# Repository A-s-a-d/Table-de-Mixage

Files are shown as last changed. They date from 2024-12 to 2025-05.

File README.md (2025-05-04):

# Cahier des charges  
[📄 lien vers Cahier des charges global (par le chef de projet)](CDC.pdf)  

Le but du projet est de créer une **table de mixage hybride**.  
Le système est divisé en **quatre sous-systèmes principaux**, chacun ayant un rôle spécifique dans la gestion du son, de l’alimentation et de l’interaction avec l’utilisateur.

---

# Sous-système : Entrées analogiques et numériques  
Ce sous-système gère la **réception des signaux audio et numériques** provenant des instruments.  
Il comprend l’interface physique entre les entrées (microphones, synthétiseurs, entrées MIDI) et le **programme de traitement** fonctionnant sur la Raspberry Pi.  
L’objectif est d’assurer une **conversion propre** des signaux vers un format numérique exploitable.

[📁 lien vers Dossier Sous-système Entrées](SousSysteme_Entrees/)  

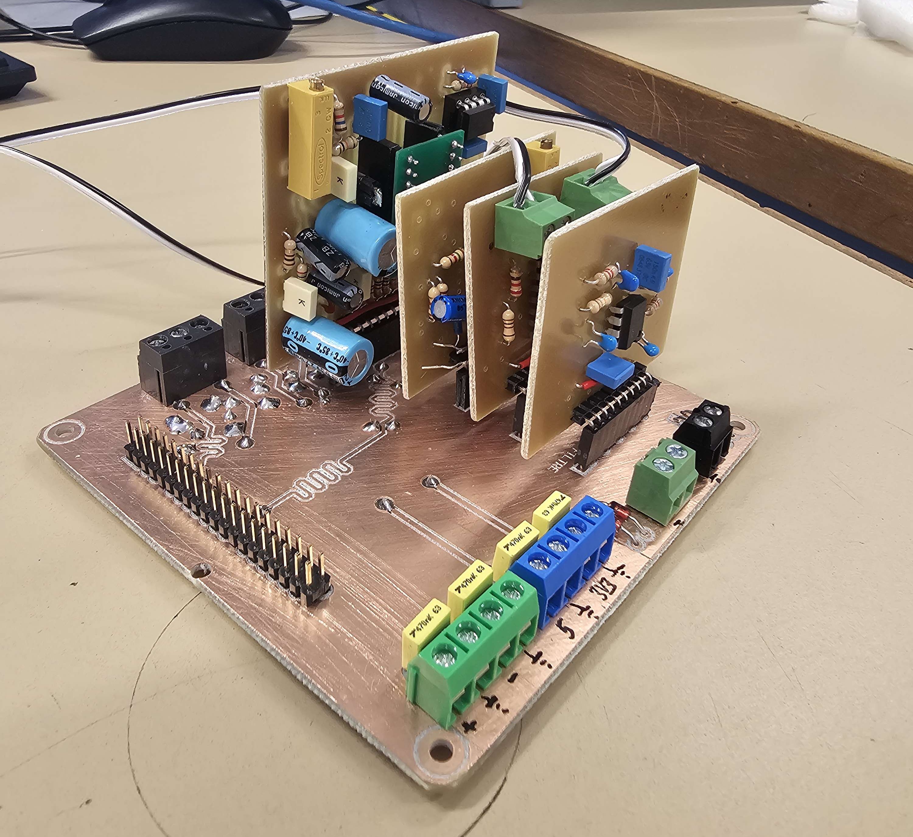
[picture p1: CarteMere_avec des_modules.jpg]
Carte mère avec des modules


---

# Sous-système : IHM et effets  
Ce sous-système englobe l’**interface homme-machine (IHM)** ainsi que la gestion des **effets sonores** (réverbération, équalisation, filtres, etc.).  
Il permet à l’utilisateur d’interagir en temps réel avec la table de mixage à l’aide de boutons, d’écrans ou de potentiomètres.

[📁 lien vers Dossier Sous-système IHM et effets](SousSysteme_IHM/)

---

# Sous-système : Amplification et restitution  
Ce sous-système s’occupe de **l’amplification** du signal audio traité et de sa **restitution** via des sorties jack ou haut-parleurs.  
Il est chargé de garantir une **qualité sonore fidèle** et adaptée aux usages finaux (monitoring, diffusion, etc.).

[📁 lien vers Dossier Sous-système Amplification et restitution](SousSysteme_Ampli_Restitution/)

---

# Sous-système : Alimentation et CAO 3D  
Ce sous-système prend en charge la **gestion de l’alimentation électrique** de l’ensemble du système, incluant la protection et la distribution.  
Il comprend également la **modélisation 3D** du boîtier via des outils de CAO, pour intégrer tous les composants de manière ergonomique.

[📁 lien vers Dossier Sous-système Alimentation et CAO 3D](SousSysteme_Alim/)

---

# Planification  
[📄 lien vers Dossier de planification du projet](DossierPlanification.pdf)

## Diagramme de Gantt  
[📊 lien vers Gantt (version 2)](Gantt_V2.pdf)

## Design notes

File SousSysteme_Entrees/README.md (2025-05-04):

# Sous-système : Entrées analogiques et numériques  

Ce sous-système est dédié à la **gestion des signaux d'entrée**, qu’ils soient **analogiques (ex. : micro, instruments)** ou **numériques (ex. : MIDI, USB)**.  
Il assure la **numérisation, le pré-traitement**, et le **transfert des données** vers le cœur logiciel de la Raspberry Pi.  
Ce sous-système est crucial pour acquisition des signaux.

---

## 📄 [Documentation / Dossier Technique](Documentation/)  
Ce dossier contient :
- Les **spécifications fonctionnelles et techniques** de ce sous-système
- Les **schémas blocs**
- Les **justifications des choix de composants**
- Le **compte rendu de tests** et mesures

C’est la référence principale pour comprendre la logique et l’architecture de ce module.

---

## 🔧 [Électronique](Electronique/)  
Ce répertoire regroupe :
- Les **schémas électroniques** (fichiers Altium, PDF, etc.)
  - voir video pour comment convertir fichier Altium en Kicad : https://www.youtube.com/watch?v=ORND7ThJx7o
- Les **typons** et routages PCB (Gerber)
- Les **simulations** (LTSpice)
Il documente toute la partie matérielle et les circuits analogiques/numériques nécessaires à l’interface avec la Raspberry Pi.

---

## 💻 [WorkSpace Linux / Programmes Linux](Linux_WorkSpace/)  
Ce dossier contient :
- Les **programmes de traitement des entrées** développés sous Linux
- Les **scripts d’acquisition**
- La configuration de l’environnement Linux pour le sous-système (drivers, services, dépendances, etc.)
- 
C’est ici que se fait le lien entre le matériel d’acquisition et le **traitement logiciel**.

---

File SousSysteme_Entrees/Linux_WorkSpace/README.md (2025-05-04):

## 💻 [WorkSpace Linux / Programmes Linux](Linux_WorkSpace/)

Ce répertoire regroupe tous les **programmes, fonctions, scripts et tutoriels** nécessaires au fonctionnement du sous-système sous Linux. Il est conçu pour faciliter le développement, l’automatisation et le test sur Raspberry Pi.

---

### 🔤 [C / C++ Programming](Linux_WorkSpace/C_Cpp_Programming/)

Contient des **exemples de code, fonctions spécifiques au sous-système**, ainsi que des **modèles de projet**.

#### 📁 Exemples :  
- [Non Blocking Execution (C)](Linux_WorkSpace/C_Cpp_Programming/Exemples/NonBlockingExecutionC/)
- [Digital Write sur GPIO de la Pi](Linux_WorkSpace/C_Cpp_Programming/Exemples/Pi_Digital_write/)
- [Test SPI](Linux_WorkSpace/C_Cpp_Programming/Exemples/Spi_Test/)
- [Multithreading + Synchronisation](Linux_WorkSpace/C_Cpp_Programming/Exemples/Threading_with_Synchronization/)
- [UART Data Handling](Linux_WorkSpace/C_Cpp_Programming/Exemples/Uart_data/)
- [Utilisation des Threads](Linux_WorkSpace/C_Cpp_Programming/Exemples/Use_Threads/)

#### 📁 Fonctions spécifiques au Sous-Système :  
- [Génération d'horloge 11.265 MHz](Linux_WorkSpace/C_Cpp_Programming/Function_SS/CLK_11_265_000Hz/)
- [Réception MIDI IN](Linux_WorkSpace/C_Cpp_Programming/Function_SS/MIDI_IN/)
- [SPI - MCP3564 (ADC)](Linux_WorkSpace/C_Cpp_Programming/Function_SS/Spi_Mcp3564/)

#### 📁 Templates de projets :  
- [Template C/C++](Linux_WorkSpace/C_Cpp_Programming/Templates/Template_C_Cpp/)
- [Template avec WiringPi](Linux_WorkSpace/C_Cpp_Programming/Templates/Template_WiringPi/)

---

### ⚙️ [Installations et Automatisation](Linux_WorkSpace/Installations_and_automation/)

Instructions, guides et scripts pour la **configuration de l’environnement Linux** et les installations nécessaires.

- [Activer l’UART](Linux_WorkSpace/Installations_and_automation/Activate_uart.md)
- [Configurer Git](Linux_WorkSpace/Installations_and_automation/git.md)
- [Liste des installations nécessaires](Linux_WorkSpace/Installations_and_automation/Installations_needed.md)
- [Connexion Bureau à Distance](Linux_WorkSpace/Installations_and_automation/RemoteDesktop.md)

---

### 🖥️ [Commandes Linux](Linux_WorkSpace/linux_commands/)

Scripts utiles pour la ligne de commande, manipulation de fichiers, utilisateurs, etc.

- [Commandes fichiers/dossiers](Linux_WorkSpace/linux_commands/file_and_folder_commands.sh)
- [Commandes importantes](Linux_WorkSpace/linux_commands/important_commands.sh)
- [Commandes utilisateur](Linux_WorkSpace/linux_commands/user_commands.sh)

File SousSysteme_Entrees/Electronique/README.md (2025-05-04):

## 🔧 [Électronique](Electronique/)

Ce répertoire regroupe toute la conception matérielle et les tests associés au sous-système Entrées. Il est structuré en plusieurs sous-dossiers détaillés ci-dessous.

---

### 📐 [CAO PCB](Electronique/CAO_PCB/)  
Contient les projets de **conception des circuits imprimés** avec leur hiérarchie modulaire.

- [01 - Suiveur](Electronique/CAO_PCB/01-Suiveur/)
- [02 - Détection et Ampli](Electronique/CAO_PCB/02-Detection_et_Ampli/)
- [03 - Offset et PBF](Electronique/CAO_PCB/03-Offset_et_PBF/)
- [04 - ADC + Filtre Antialiasing](Electronique/CAO_PCB/04-ADC+antiallaising/)
- [Assemblage des Modules Analogiques](Electronique/CAO_PCB/Assamblage_Modules_Analogique/)
- [Carte Mère](Electronique/CAO_PCB/Carte_Mere/)
- [MCP3564 (Convertisseur ADC)](Electronique/CAO_PCB/MCP3564/)
- [Library - Composant ](Electronique/CAO_PCB/Library)

---

### 🧾 [Fichiers Gerber (CAO PCB Gerber)](Electronique/CAO_PCB_GERBER/)  
Fichiers prêts pour la **fabrication des circuits imprimés**.

- [01 - Suiveur](Electronique/CAO_PCB_GERBER/01-Suiveur/)
- [02 - Détection et Ampli](Electronique/CAO_PCB_GERBER/02-Detection_et_Ampli/)
- [03 - Offset et PBF](Electronique/CAO_PCB_GERBER/03-Offset_et_PBF/)
- [04 - ADC + Antialiasing](Electronique/CAO_PCB_GERBER/04-ADC+antiallaising/)
- [Carte Mère](Electronique/CAO_PCB_GERBER/Carte_Mere/)
- [MCP3564](Electronique/CAO_PCB_GERBER/MCP3564/)

---

### 🔁 [Simulations](Electronique/SIMULATIONS/)  
Simulations de circuits réalisés sous LTspice ou autre pour validation des choix de conception.

---

### 🧪 [Tests](Electronique/TESTS/)

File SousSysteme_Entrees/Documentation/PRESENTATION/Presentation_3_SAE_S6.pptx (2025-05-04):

## Table de Mixage : SmartMix

SAE BUT 3 GEII ESE

## Sommaire

1. Présentation de système
2. Détails des sous-systèmes
3. Conception et mise en œuvre
4. Implantation
5. Vérification
6. Dysfonctionnements et maintenance
7. État actuel du système
8. Conclusion et pistes d'amélioration

## Présentation de système

Mixage des signaux audios (analogiques ou numériques) envoyés par des instruments développés par les étudiants de BUT 3 GEII ESE

Fonctionnalités clés :
- 2 Entrées Numériques
- 2 Entrées Analogiques
- Synchronisation des données

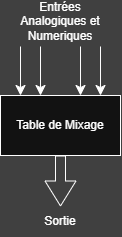
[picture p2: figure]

## FAST

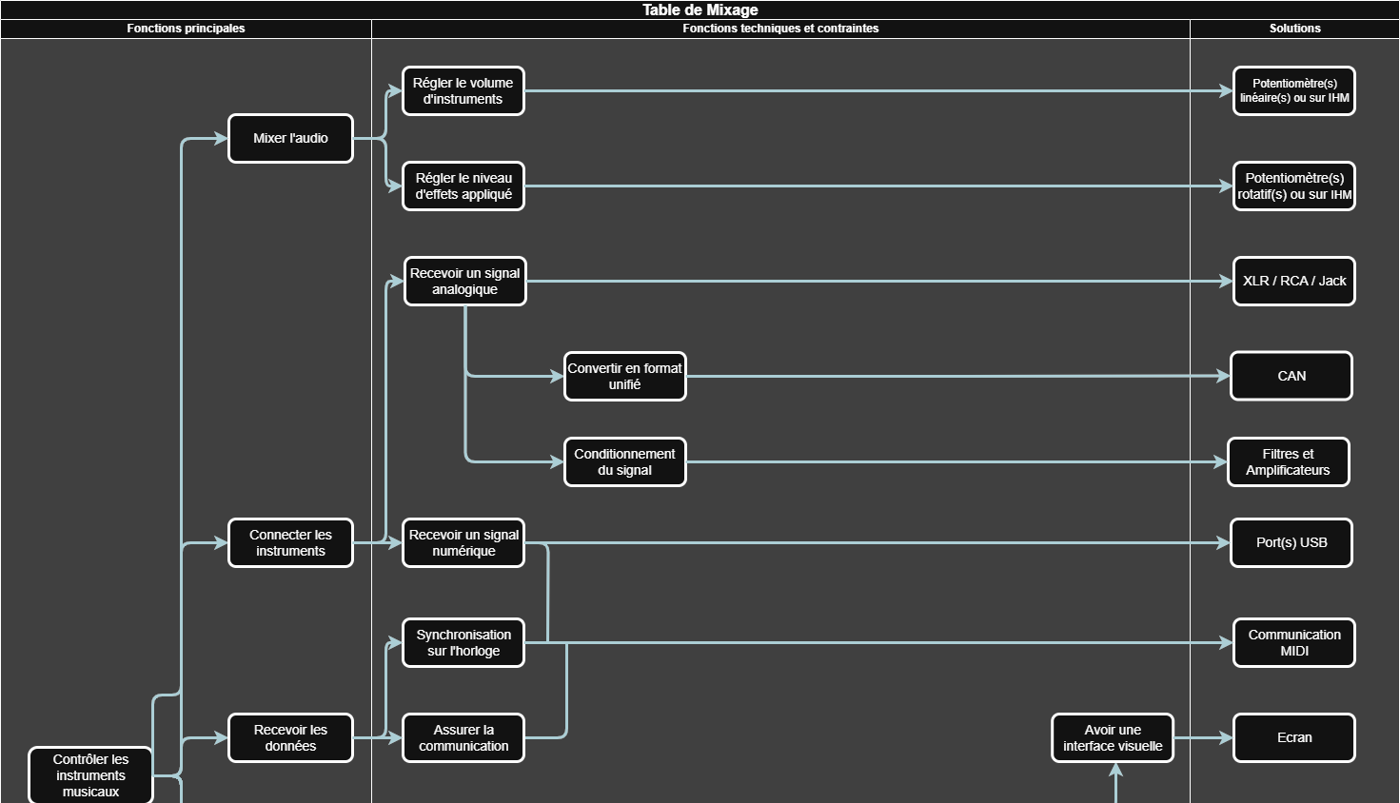
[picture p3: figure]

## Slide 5

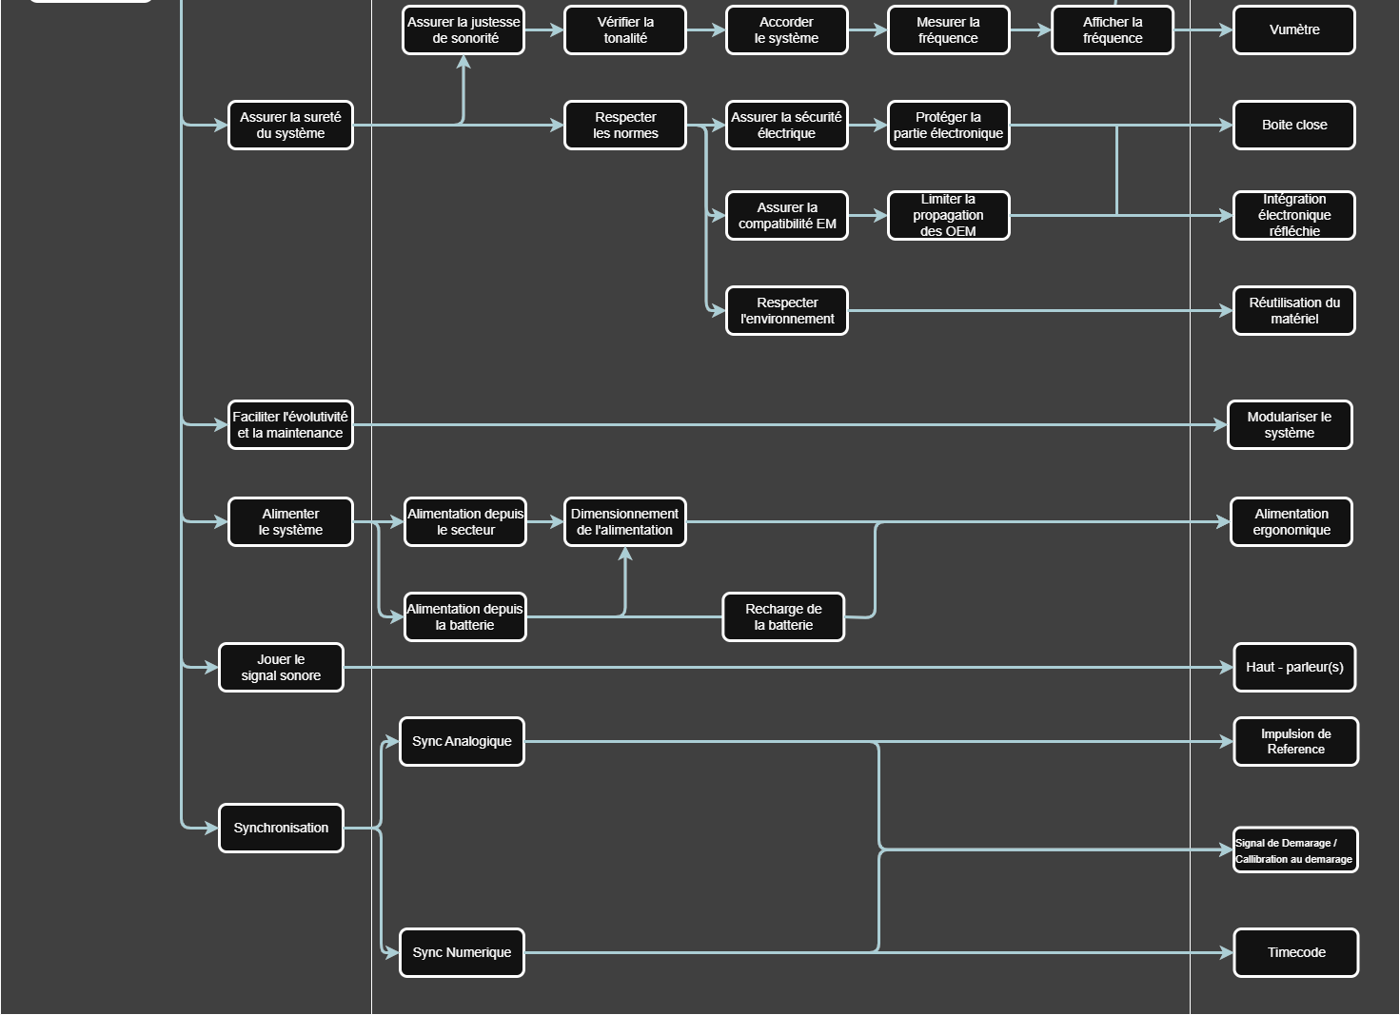
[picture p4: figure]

## Détails des sous-systèmes

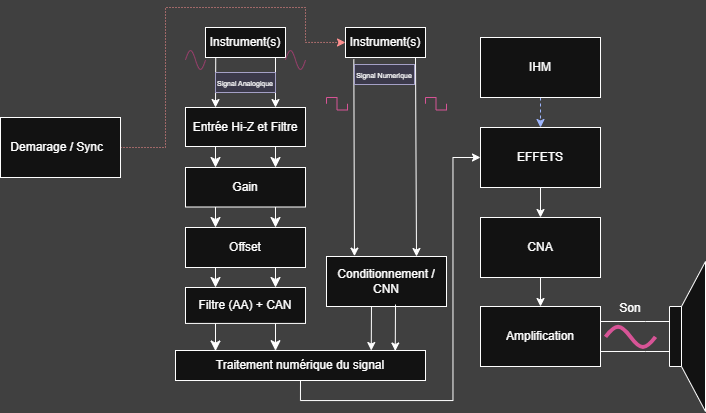
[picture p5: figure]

## Conception

- Conception d’un système électronique modulaire
- Traitement des Signaux analogiques et numériques : filtrage, Gain, Offset, conversion, synchronisation
- Choix techniques justifiés en fonction des contraintes de performance, consommation et coût
- Outils et technologies utilisés :
  - Raspberry Pi 4B
  - CAO : Altium Designer
  - Simulation : LTSpice
  - Langages : C++, Python
  - Versioning : Git (GitHub -> GitLab)

## Conception

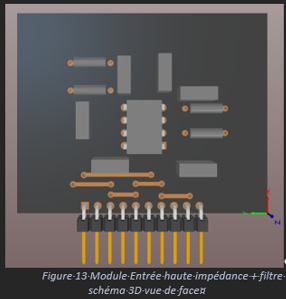
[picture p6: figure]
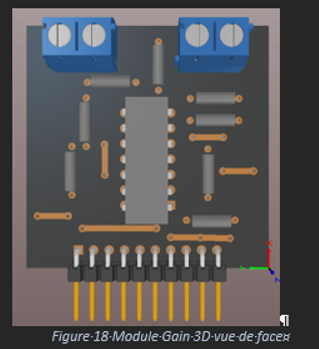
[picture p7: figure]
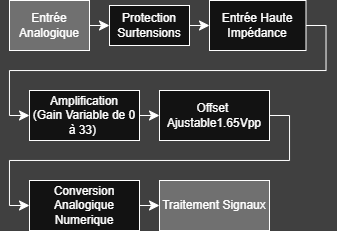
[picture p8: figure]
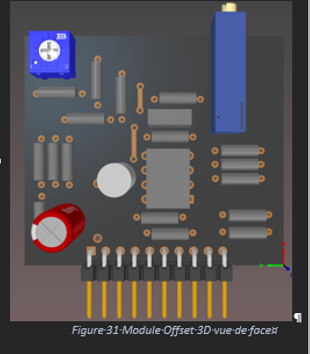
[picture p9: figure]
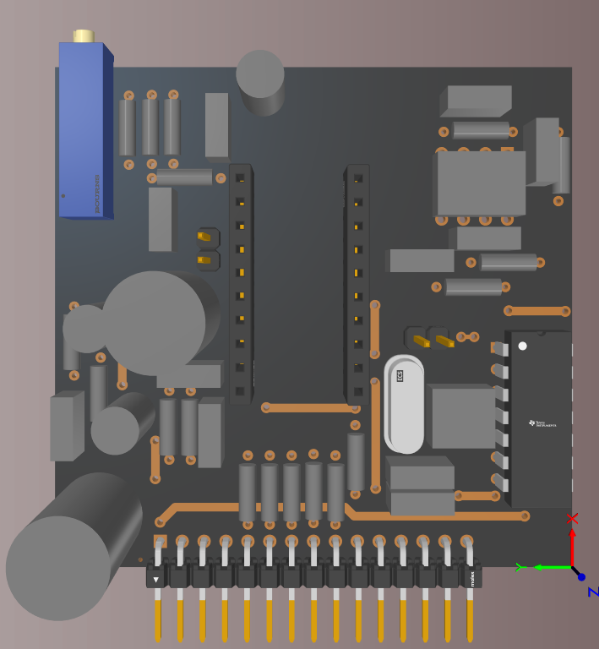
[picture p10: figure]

## Conception

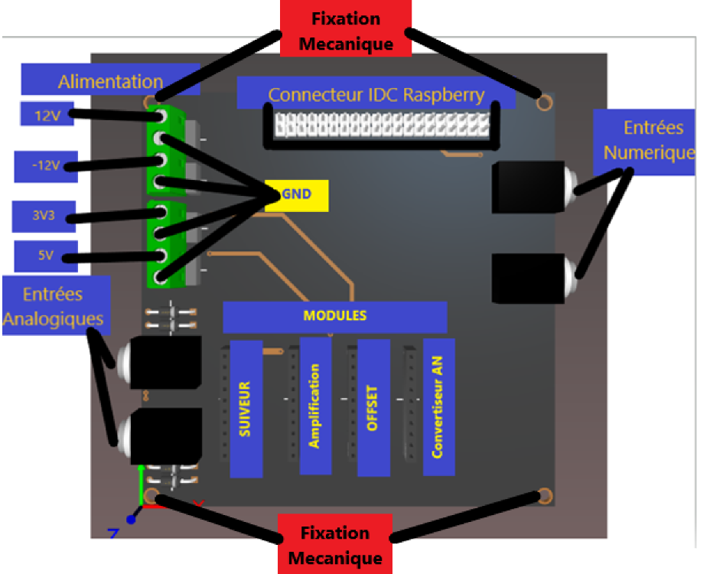
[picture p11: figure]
Carte Mere avec des modules

## Vérification

- Approche PDCA (Plan – Do – Check – Act) :
  - Plan : Planifier : définition des objectifs de tests et critères de validation
  - Do : Déployer : exécution des tests unitaires et d'intégration
  - Check : Contrôler : analyse des résultats, identification des écarts
  - Act : Ajuster : actions correctives et amélioration continue

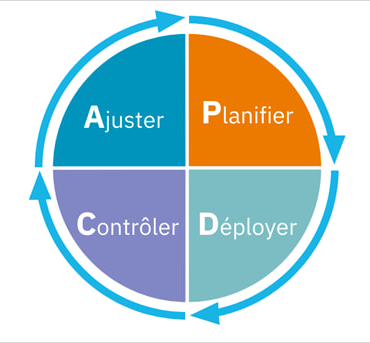
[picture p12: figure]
Cycle PDCA ou Roue de deming

## Vérification

- Exemple :
  - Plan : Conception de Carte ADC et horloge externe avec un oscillateur quartz
  - Do : Test de différents signaux
  - Check : problème avec l’horloge 11MHz, a cause des caractéristiques des composants
  - Act : Configurer la carte pour utiliser le 2eme mode de Horloge Externe.

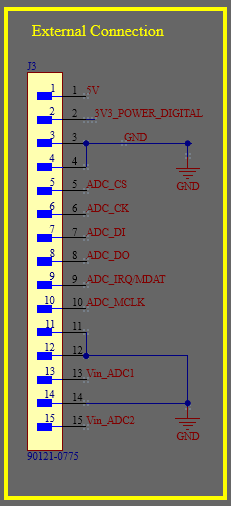
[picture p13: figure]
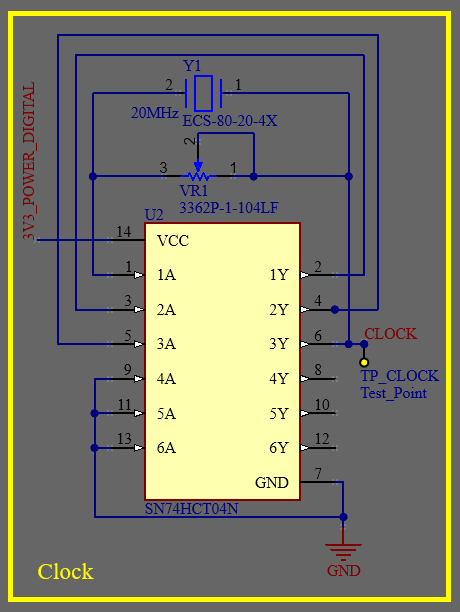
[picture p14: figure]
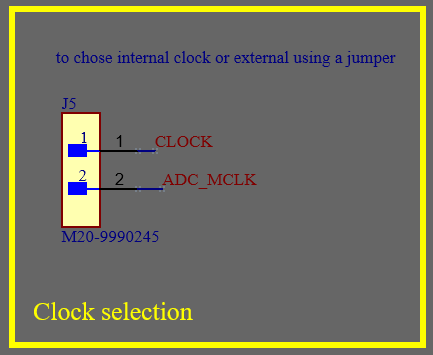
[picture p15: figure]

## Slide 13

Exemple de dysfonctionnement

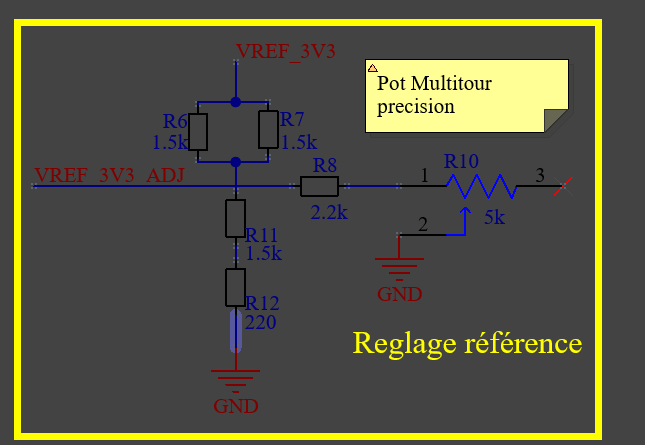
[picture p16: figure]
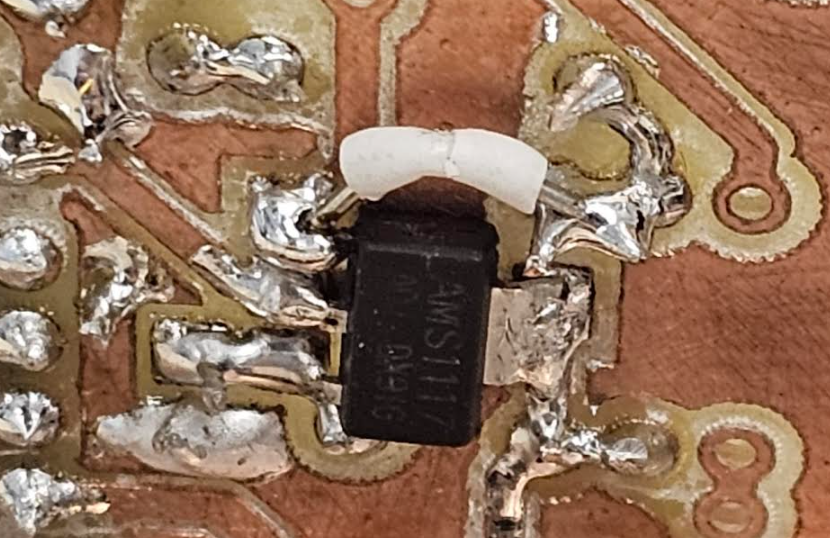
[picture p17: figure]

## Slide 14

Synthèse globale des Test et état actuelle de système

Sous-système | Modules Testés | Type de Test | Critères de Validation | Résultats | Actions Correctives
Carte Mère | FT9-0 & FT9-1 | Tests de fonctionnement | Bonne modularité et absence de court-circuit | Fonctionnel | Aucune
Entrée Audio Analogique | FT2-0 | Test de pré-amplification et filtrage | Amplification correcte, atténuation bruit | Fonctionnel | Aucune
| FT2-1 | Test de régulation du gain | Variation du gain conforme aux attentes | Fonctionnel | Aucune
| FT2-2 | Test de décalage (offset) | Offset réglable et stable | Fonctionnel | Aucune
| FT3-0 | Conversion analogique-numérique (ADC) | Résolution entre 12 et 24 bits, échantillonnage à 44,1 kHz | Fonctionnel | Aucune
Entrée Audio Numérique | FT1-0 | Test de réception MIDI | Réception des messages MIDI sans erreur | Fonctionnel | Aucune
| FT6 | Synchronisation MIDI | | Non-disponible ou en cours | Aucune
| FT3 -1 | Programme Conversion Analogique Numérique | | Non-disponible ou en cours | Aucune

## Implantation, Checklist

- Alimentations
  - Tensions requises : +12V, -12V, 3.3V, 5V.
  - Connexion aux connecteurs dédiés.
- 2. Connexions des Entrées Analogiques & Numériques
  - Sources Analogiques : jack 3.5mm, sources audios.
  - Signaux Numériques : Niveau logique 3.3V pour le MIDI, jack 3.5mm

- 3. Installation du Système
  - Préparation de la carte SD.
  - Installation de Raspberry Pi OS et des bibliothèques nécessaires.
  - Démarrage de la Raspberry Pi avec le programme dédié.
- 4. Précautions
  - Respect des niveaux de signal : +4 dBu (1.736V peak) pour l’analogique.
  - Manipulation électrique uniquement système éteint.
  - Suivi des schémas et consignes de sécurité.

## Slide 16

Maintenance Préventive

Définition :
Intervention anticipée pour éviter l’apparition de pannes.
Actions réalisées :
- Vérification régulière des connexions entre modules
- Inspection visuelle pour détecter usure ou corrosion
- Nettoyage des éléments sensibles
- Exemple concret : Nettoyage régulier des potentiomètres pour garantir leur bon fonctionnement

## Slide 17

Maintenance Corrective

Définition :
Intervention après l'apparition d'un dysfonctionnement pour restaurer le système.
Actions réalisées :
- Remplacement des modules ou composants défectueux
- Réparation des connexions endommagées
- Exemple concret : Remplacement des potentiomètres en fin de vie ou présentant des erreurs de lecture

## Facilité de Maintenance

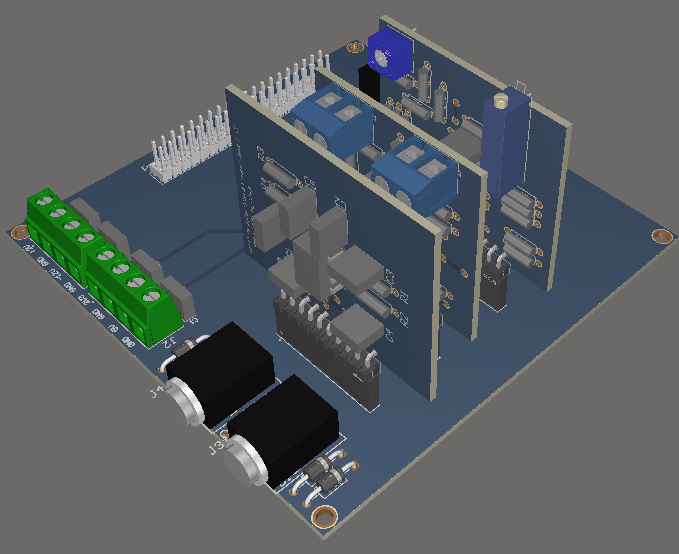
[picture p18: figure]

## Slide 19

Check List & CDC

- Mixer l’Audio
- Connecter les Instruments
- Recevoir les données
- Assuer la sureté du systeme
- Facilite de l’évoluivité et la maintenance
- Alimenter le système
- Envoyer un signal sonore en sortie.
- Synchronisation

Fonctionne
Fonctionne en état degradé
Non fonctionnel

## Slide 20

Reste a Faire

- Finir la programmation de ADC
- Intégrer tous les systèmes ensemble
- Gain automatique : Signaux analogiques
- Mettre plus d’entrées et moyens d’envoyer des signaux.
- Mettre en place des procédures de maintenance automatisées pour détecter les défaillances rapidement.
- Traitement temps réel.

Pistes ameliorations

## Questions

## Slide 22

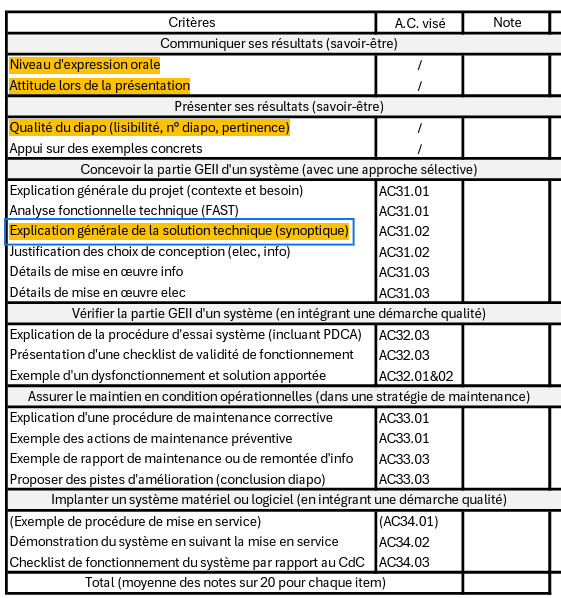
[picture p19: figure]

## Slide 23

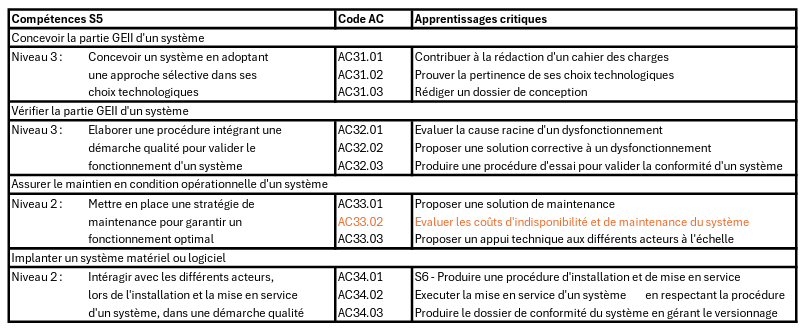
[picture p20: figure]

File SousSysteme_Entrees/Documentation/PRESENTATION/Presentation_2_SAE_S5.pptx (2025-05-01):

## Table de Mixage : SmartMix

SAE BUT 3 GEII ESE

MUHAMMAD Asad

## Sommaire

1. Présentation et Objectifs
2. Présentation des sous-systèmes
3. Approche pour la conception du système
4. Détails des sous-systèmes, Conception et mise en œuvre
5. État actuel du système
6. Dysfonctionnements et maintenance
7. Conclusion et pistes d'amélioration

## Contexte et Besoin

Mixage des signaux audios (analogiques ou numériques) envoyés par des instruments développés par les étudiants de BUT 3 GEII ESE

Fonctionnalités clés :
- 2 Entrées Numériques
- 2 Entrées Analogiques
- Synchronisation des données


## FAST


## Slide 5


## Caractéristiques principales

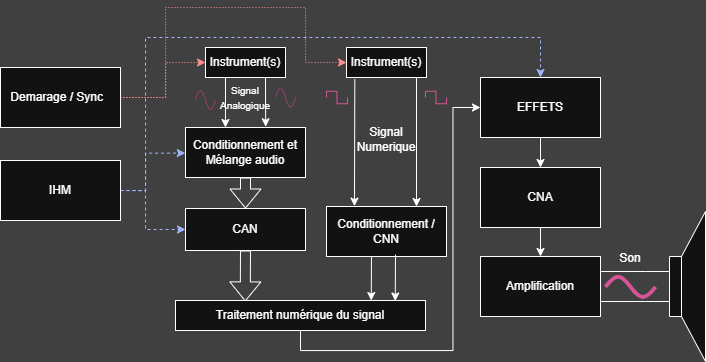
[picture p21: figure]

## Conditionnement de signal analogique


100mVpp- ~3.3Vpp

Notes: Simulations electriques sur LTSpice et PCB sur Altium designer

## Entrée Numérique

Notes: Choix Raspberry Pi :
Interface Graphique sur un ecran couleur
Performances améliorées
Conectivité et interfacess disponibles, Nombres d’UARTS disponibles
Gestion des Tâches Complexes
Plus d’outils disponiibles avec une possibilitées de programmer en plusieurs languages, automatiser avec des scripts.

Inconvenient :
Pas Temps reel, mais la vitesste doit etre suffisant pour ne pas impacter le système.
Sinons des solutions comme :
isolations des cœurs
Et programmation multicoeurs

## Approche de Conception : Modulaire

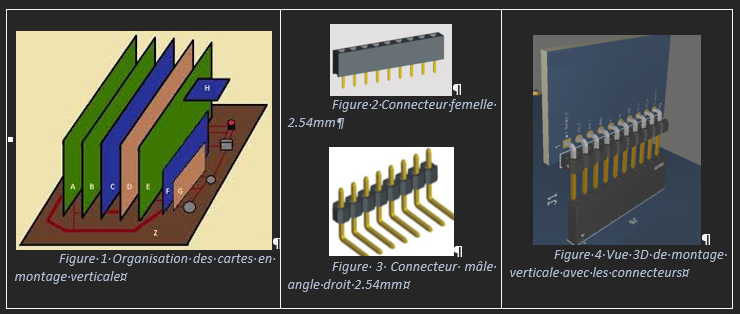
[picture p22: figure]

Développement parallèle, Maintenance Facile, Réutilisabilité, Améliorations faciles.

## Entrée et Protection Surtensions

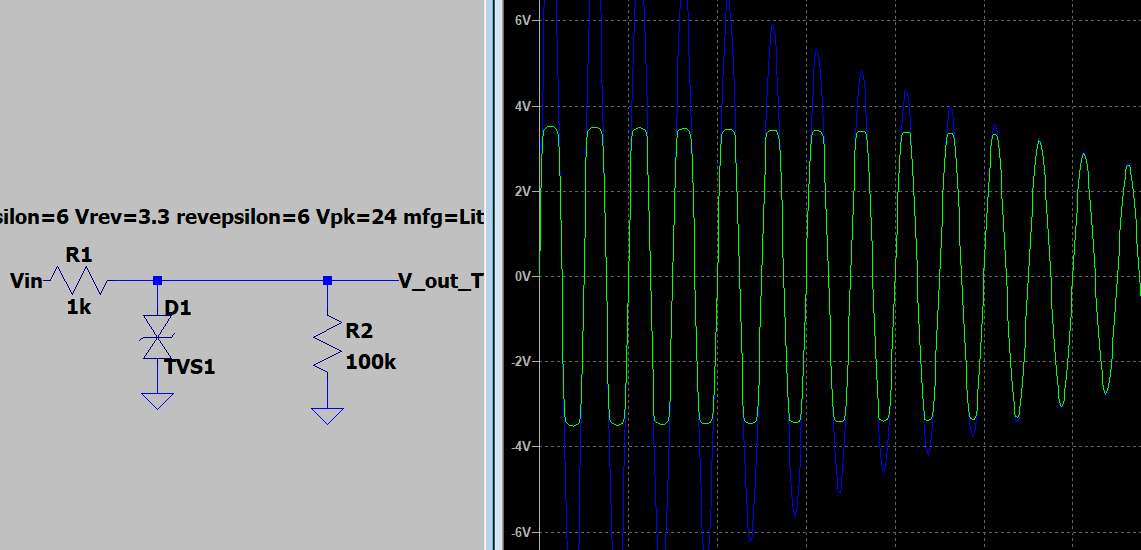
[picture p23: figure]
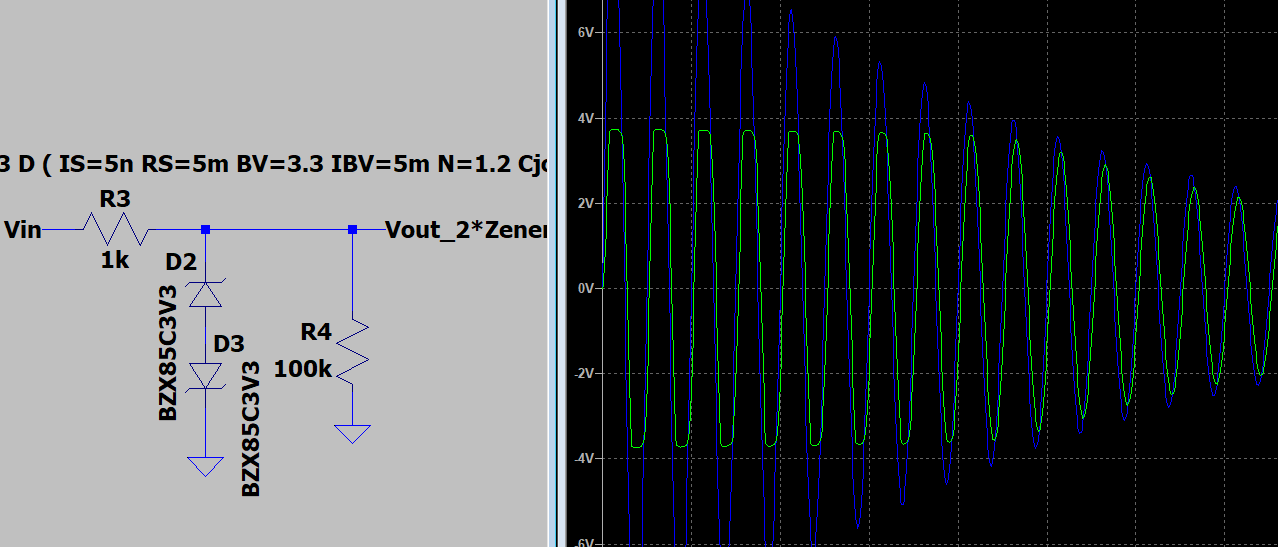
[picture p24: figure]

## Entrée Haute Impédance

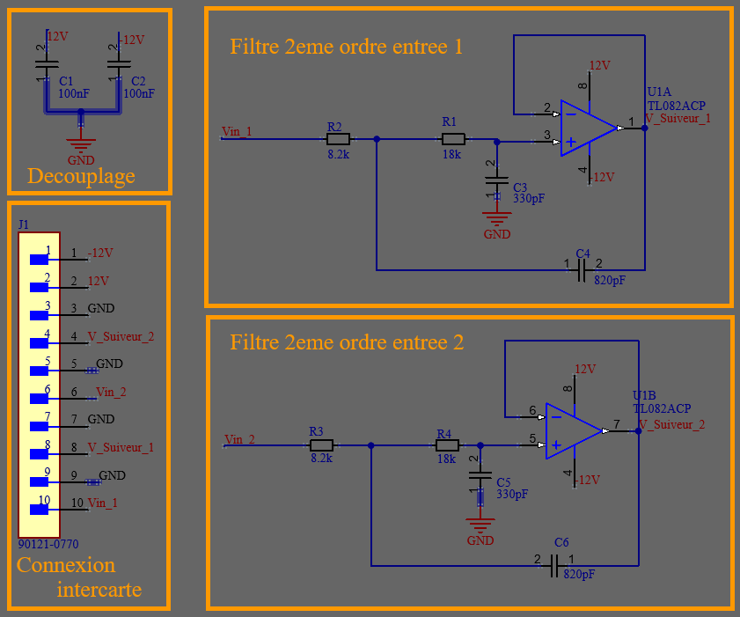
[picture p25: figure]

Module


## Entrée Haute Impédance

Module


## Amplification


Module

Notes: Ampli gain automatique

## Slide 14

Amplification


A module


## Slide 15

Offset

Module

## Offset


A module


## Conversion Analogique Numérique

Module
- ADC : Mcp3564
  - 24 bits
  - Maximum 152kHz
  - SPI

En developpement

## Carte Mère


## Mise en œuvre électrique, Checklist

- Alimentations
  - Tensions requises : +12V, -12V, 3.3V, 5V.
  - Connexion aux connecteurs dédiés.
- 2. Connexions des Entrées Analogiques & Numériques
  - Sources Analogiques : jack 3.5mm, sources audios.
  - Signaux Numériques : Niveau logique 3.3V pour le MIDI, jack 3.5mm

- 3. Installation du Système
  - Préparation de la carte SD.
  - Installation de Raspberry Pi OS et des bibliothèques nécessaires.
  - Démarrage de la Raspberry Pi avec le programme dédié.
- 4. Précautions
  - Respect des niveaux de signal : +4 dBu (1.736V peak) pour l’analogique.
  - Manipulation électrique uniquement système éteint.
  - Suivi des schémas et consignes de sécurité.

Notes: Remarque : La conversion Analogique-Numérique n'est pas encore disponible. Une mise à jour du document et du programme sera effectuée sur GitLab ultérieurement.

## Entrée Numérique et Isolation électrique


=

## Données Midi

MIDI Communication Tips – CHD Elektroservis

MIDI Standard | Utilisé | Pourquoi
31250 baud | 115200 baud | 31250 n’est pas standard 16C650, donc il faut une configuration manuelle.
0 – 5V | 0 – 3.3V | 0-3.3V is the logic levels for Raspberry Pi.

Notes: N’est pas en kernal,
Standard 16C650
Diviseur flotant donc peutetre avec freqence de horloge a modifier.
termios
A kernel is a computer program at the core of a computer's operating system that always has complete control over everything in the system. The kernel is also responsible for preventing and mitigating conflicts between different processes.[1] It is the portion of the operating system code that is always resident in memory[2] and facilitates interactions between hardware and software components. A full kernel controls all hardware resources (e.g. I/O, memory, cryptography) via device drivers, arbitrates conflicts between processes concerning such resources, and optimizes the utilization of common resources e.g. CPU & cache usage, file systems, and network sockets. On most systems, the kernel is one of the first programs loaded on startup (after the bootloader). It handles the rest of startup as well as memory, peripherals, and input/output (I/O) requests from software, translating them into data-processing instructions for the central processing unit.

## GPIO : Uart

Raspberry Pi


## Configuration Uart

- Installer Pi Os
- Modifier les fichiers de configuration de démarrage " “Boot” pour activer les UARTs.
- Installer la bibliothèque : Wiring Pi.
- C / C++ programme pour la réception des données séries.
- Les données sont disponibles pour le traitement numérique.

Raspberry Pi

## Mise en oeuvre Informatique, Checklist

- 1. Installation et Configuration du Système
  - Préparation de la carte SD avec Raspberry Pi OS
  - Installation des bibliothèques nécessaires (WiringPi, etc.)
- 2. Développement et Programmation
  - Gestion des entrées/sorties MIDI
  - Lancement du programme de réception des données MIDI.
- 3. Tests et Validation
  - Vérification du bon fonctionnement conditionnement des signaux analogiques.
  - Vérification de la réception des données MIDI.

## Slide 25

Synthèse globale des Teste et état actuelle de système

Sous-système | Modules Testés | Type de Test | Critères de Validation | Résultats | Actions Correctives
Carte Mère | FT9-0 & FT9-1 | Tests de fonctionnement | Bonne modularité et absence de court-circuit | Fonctionnel | Aucune
Entrée Audio Analogique | FT2-0 | Test de pré-amplification et filtrage | Amplification correcte, atténuation bruit | Fonctionnel | Aucune
| FT2-1 | Test de régulation du gain | Variation du gain conforme aux attentes | Fonctionnel | Aucune
| FT2-2 | Test de décalage (offset) | Offset réglable et stable | Fonctionnel | Aucune
| FT3-0 | Conversion analogique-numérique (ADC) | Résolution entre 12 et 24 bits, échantillonnage à 44,1 kHz | Non-disponible ou en cours | Aucune
Entrée Audio Numérique | FT1-0 | Test de réception MIDI | Réception des messages MIDI sans erreur | Fonctionnel | Aucune
| FT6 | Synchronisation horloge MIDI | | Non-disponible ou en cours | Aucune
| FT3 -1 | Programme Conversion Analogique Numerique | | Non-disponible ou en cours | Aucune

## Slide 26

Exemple de dysfonctionnement

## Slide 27

Maintenance

- Corrective :
  - Remplacement des modules défectueux.
- Préventive :
  - Vérification régulière de la bonne connexion des modules.
  - Inspection des connexions pour détecter tout signe d’usure ou de corrosion.

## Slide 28

Pistes ameliorations

- Gain automatique : Signaux analogiques
- Mettre plus d’entrées et moyens d’envoyer des signaux.
- Mettre en place des procédures de maintenance automatisées pour détecter les défaillances rapidement.
- Traitement temps réel.

## Questions

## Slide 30


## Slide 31


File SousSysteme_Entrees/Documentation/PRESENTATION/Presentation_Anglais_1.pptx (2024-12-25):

## Mixing Console

SAE BUT 3 GEII ESE

MUHAMMAD Asad

## Summary

- Introduction
- Key Objectives
- How does It Work?
- Core Features
- Eco-Friendly and Cost-Effective
- Development Timeline
- Teamwork and Integration
- Conclusion

## Introduction


Key points :
- Designing an automated audio mixer.
- Synchronizing multiple music streams (MIDI and analog).

## Key Objectives

- Develop a functional audio control system.
- Ensure compatibility with 2 digital and 2 analog inputs.
- Ensure Synchronisation of signals.
- Incorporate sustainable, cost-effective design principles.

## How does It Work?


Key functions:
- MIDI and analog input handling.
- Real-time synchronization.
- Physical interface with faders, knobs, and display.
- Power supply.

## Core Features


## Eco-Friendly and Cost-Effective

Key points
Reuse of existing materials.
Budget cap of €200 for new components.
Open-source principles for future use and transparency.

## Development Timeline


## Teamwork and Integration

- Signal Input + Signal Processing
- User Interface + Signal Effects
- 3D-CAD + Power supply
- Signal Output + Amplification

## Conclusion and current state

- What the project achieves.
- Importance of sustainability and innovation.
- Future potential for advanced system.

## Questions

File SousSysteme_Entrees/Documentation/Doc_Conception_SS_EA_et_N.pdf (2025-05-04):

BUT 3 – SAE S5

CY IUT – GEII Neuville

# Document de Conception

## Projet tutoré Mixeur Sous-système Entrées

## Document rédigé par : MUHAMMAD Asad Version : 1.2 [4 mai 2025]

BUT 3 – SAE S5 | Document de Conception


4 mai 2025 | Version : 1.2 | 1

## Historique des modifications et révisions de ce document :

N° de version | Date | Auteur | Description et circonstances de la modification
V 0 | | MUHAMMAD Asad | Brouillon : première version, modèle fourni.
V 1.0 | 09/02/2025 | MUHAMMAD Asad | Première rédaction complète du document.
V1.1 | 16/02/2025 | MUHAMMAD Asad | Corrections (valeurs numériques …etc)
V 1.2 | 04/05/2025 | MUHAMMAD Asad | Mise a jour Fin de Projet

## Grilles d'évaluations

## Avant-propos¹

Ce document présente la conception d’une table de mixage audio destiné à offrir une solution compacte et performante pour le traitement et la gestion de signaux sonores.

L’approche adoptée dans ce document vise à fournir une description claire de l’architecture du système, des choix techniques et des principales fonctionnalités, sans entrer dans les détails de mise en œuvre. Il sert de base à la compréhension globale du projet avant d’aborder les aspects plus spécifiques liés à la fabrication et au développement logiciel.

1 Référence : Gestion de projet, 50 outils pour agir ; F. Bouchaouir, Y. Dentinger, O. Englender ; Vuibert ;
2014. | Expression du besoin et cahier des charges fonctionnel ; J. Bernard-Bousières ; AFNOR ; 2012.

## Table des matières

## Répartition des responsabilités dans la rédaction du dossier

Partie du dossier | Responsable
Avant-propos I. Contexte du projet A. Situation et description B. Besoins et objectifs II. Rappel des fonctions | Muhammad Asad & VRONSKYI Volodymyr
III. Choix des outils de travail | Assignation en fonction des outils utilisés dans chaque sous-système
IV. Conception détaillée des fonctions A. Assurer la fiabilité et la maintenance 1. Système modulaire avec sous-systèmes indépendants 2. Protection des entrées audio contre les surtensions | Muhammad Asad & VRONSKYI Volodymyr
3. Protection des alimentations contre les courts-circuits | RAMIRES MATOS Victor & IDMOND Benjy
B. Gestion de l’entrée audio analogique 1. Conditionner le signal analogique (pré-amplification et filtrage) 2. Régulation dynamique du gain du signal 3. Application d’un décalage sur le signal analogique 4. Conversion du signal analogique en numérique | Muhammad Asad & VRONSKYI Volodymyr
C. Gestion de l’entrée audio numérique 1. Réception des signaux MIDI via interface DIN ou USB 2. Synchronisation des horloges MIDI avec le traitement audio 3. Conversion des données MIDI en signal audio | Muhammad Asad & VRONSKYI Volodymyr
D. Traitement numérique du signal audio 1. Application de filtres et algorithmes de mixage numérique 2. Gestion du mixage audio en temps réel ….3. Fournir un IHM pour la gestion des paramètres de mixage et effets. | YIGIT Enes & EL KARANI Djibril
4. Restitution du signal audio traité 5. Sortie stéréo ou ligne pour restitution sonore | LATHRO-SERI Nathan & ERBE Gabriel
E. Amplification du signal audio 1. Amplification en tension et en courant pour restitution optimale | LATHRO-SERI Nathan & ERBE Gabriel
F. Gestion de l’alimentation électrique 1. Alimentation via batterie rechargeable 2. Recharge via adaptateur secteur ou alimentation DC G. Format compact et ergonomie 1. Conception d’un boîtier robuste et léger 2. Optimisation des dimensions pour transport et intégration | RAMIRES MATOS Victor & IDMOND Benjy

## Table des Figures

Figure 19 Régulateur de tension variable/programmable pour une référence de tension stable........ 23

## I. Contexte du projet

### A. Situation et description

Le projet consiste à concevoir et réaliser une table de mixage audio automatique capable de traiter et de synchroniser plusieurs flux audios provenant d’instruments de musique. Ce dispositif sera intégré à l’Orchestrion, un système automatisé conçu pour reproduire les performances d’un orchestre en combinant différents instruments.

Développé dans le cadre de la SAE (Situation d’Apprentissage et d’Évaluation), ce projet sera présenté lors des Journées Portes Ouvertes de l’IUT de Cergy-Pontoise. Il met en avant la conception d’un dispositif électronique physique tout en respectant des contraintes écologiques et économiques.

### B. Besoins et objectifs

L’objectif principal de ce projet est de valoriser les enseignements du BUT GEII (Bachelor Universitaire de Technologie en Génie Électrique et Informatique Industrielle) à travers la création d’une unité de contrôle audio automatisée.

Ce mixeur audio doit permettre :

- Le traitement et la synchronisation de plusieurs sources sonores en temps réel.
- Une intégration optimisée au sein de l’Orchestrion, garantissant une interaction fluide avec les instruments automatisés.
- Une gestion efficace du signal audio tout en maintenant une faible consommation énergétique.

En plus des contraintes techniques, le projet répond également à des enjeux écologiques et économiques, en favorisant l’utilisation de composants optimisés et durables.

## II. Rappel des fonctions

- FT9 : Assurer la fiabilité et la maintenance
- FT9-0 : Concevoir un système modulaire avec des sous-systèmes indépendants (entrée audio, traitement, interface utilisateur, alimentation).
- FT9-1 : Garantir la sécurité électrique grâce à une protection contre les surtensions et courts-circuits sur les entrées Analogiques et Numériques.
- FT9-2 : Garantir la sécurité électrique grâce à une protection contre les surtensions et courts-circuits sur les Alimentations.
- FT2, FT3 : Gérer l’entrée audio analogique
- FT2-0 : Conditionner le signal analogique via pré amplification et filtrage.
- FT2-1 : Réguler le gain du signal d’entrée.
- FT2-2 : Appliquer un décalage (offset) sur le signal analogique AC.
- FT3 : Convertir le signal analogique en numérique (ADC) avec une résolution minimale de 12 à 16 bits et une fréquence d’échantillonnage de 44,1 kHz.
- FT1, FT6 : Gérer l’entrée audio numérique
- FT1-0 : Réceptionner les signaux MIDI.
- FT6 : Synchroniser les horloges MIDI avec le traitement audio interne.
- FT1-1 : Convertir les données MIDI en audio grâce à une synthèse numérique.
- FT5, FT6, FT7, FS1, FS2 : Assurer le traitement numérique du signal et produire un signal sonore
- FT5-0 : Appliquer des algorithmes de filtrage numérique (IIR/FIR) et de mixage pour ajuster les niveaux sonores et ajouter des effets.
- FT5-1 : Gérer le mixage audio en temps réel avec une allocation dynamique des canaux.
- FT7, FS1, FS2 : Fournir une IHM pour la gestion des paramètres de mixage et effets.
- FT6-0 : Restituer le signal audio
- FT6-1 : Fournir une sortie stéréo pour deux haut-parleurs intégrés ou une sortie ligne (non amplifiée).
- FT6-2 : Amplifier le signal audio
- Assurer l’amplification en tension et en courant du signal audio pour une restitution optimale.
- FT8 : Gérer l’alimentation électrique
- Assurer une alimentation via une batterie rechargeable.
- Permettre la recharge via un adaptateur secteur, une alimentation DC.
- FC6, FT9 : Garantir un format compact et une bonne ergonomie
- Concevoir un boîtier robuste et léger, en matériaux résistants aux chocs et adaptés aux manipulations fréquentes.
- Optimiser les dimensions pour faciliter le transport et l’intégration dans un setup mobile.¹

1
Les Fonction barrées seront rédigées dans le document de fabrication de sous système

## III.Choix des Outils de travail

### A. Conception du PCB avec Altium Designer

1. Altium Designer : Outil Principale :

Pour la réalisation du circuit imprimé, Altium Designer a été choisi en raison de ses capacités avancées en conception multi-cartes, ce qui est particulièrement adapté à l’architecture modulaire du projet.

La conception du PCB suit plusieurs étapes :

- Schématisation du circuit : Création des schémas électriques des différentes cartes en définissant les composants et leurs connexions.
- Placement des composants : Positionnement des composants sur le PCB en prenant en compte l’optimisation de l’espace et les contraintes thermiques.
- Routage des pistes : Traçage des connexions électriques en respectant les règles de conception pour minimiser les interférences et assurer la qualité du signal.
- Vérifications : Analyse du design via les outils de validation d’Altium Designer afin d’éviter les erreurs électriques et mécaniques.
- Intégration dans un projet multi-cartes : Ajout et gestion des différentes cartes (carte mère et cartes modules) dans un projet multi-cartes d'Altium Designer, facilitant ainsi la cohérence des connexions et l’optimisation du routage inter-cartes.
- Génération des fichiers de fabrication : Production des fichiers Gerber et des documents nécessaires à la fabrication et à l’assemblage du circuit imprimé.

Grâce à Altium Designer, l’architecture modulaire et verticale du système est optimisée, assurant une intégration mécanique et électrique efficace entre la carte mère et les modules.
2. Alternatives : Ki-Cad et Proteus pour certaines parties du projet
Pour les circuits qui ne nécessitent pas une architecture modulaire et qui doivent uniquement gérer des entrées et sorties, d’autres logiciels peuvent être employés :

Ki-Cad : Open-source, idéal pour des conceptions simples et collaboratives sans restriction de licence.

Proteus : Disponible à l’université, utile pour des schémas rapides et des simulations avant fabrication.

Ces outils offrent une flexibilité supplémentaire en fonction des besoins spécifiques du projet, tout en maintenant Altium Designer comme principal logiciel pour la conception des modules et de la carte mère.

### B. Simulations circuits LTSPICE

1. LTSPICE : Outil principal pour la simulation de circuits

LTSpice est privilégié pour la simulation des circuits en raison de son large choix de composants et de la facilité de création des modèles de simulation. Il offre une flexibilité optimale pour concevoir des simulations précises et réalistes de circuits complexes. L'outil permet également d'ajuster facilement les paramètres des composants, ce qui facilite la modélisation fine des comportements électriques. Grâce à sa puissance et à ses capacités de simulation rapide, LTSpice permet d'identifier et de corriger d'éventuelles erreurs avant la fabrication, réduisant ainsi les risques et les coûts.

2. Alternative : Proteus pour des simulations et conception PCB


En alternative, Proteus peut être utilisé pour les simulations de circuits. Il permet de passer facilement de la simulation à la conception du PCB, ce qui simplifie l'ensemble du processus de conception. Toutefois, Proteus est limité par un choix restreint de composants par rapport à LTSpice, ce qui peut rendre son utilisation moins flexible pour certains parties complexes nécessitant des composants spécifiques.

C. Choix de « cerveau » de notre système.

Notre système doit gérer plusieurs signaux analogiques et numériques en entrée et en sortie, tout en fournissant une interface utilisateur permettant de contrôler et d’ajuster différents paramètres. Pour cela, nous avons besoin d’un dispositif capable d’exécuter plusieurs tâches en parallèle, de traiter des signaux en temps réel et de communiquer avec divers périphériques.

Après analyse des différentes options, nous avons opté pour une Raspberry Pi 4, un micro-ordinateur monocarte (SBC) puissant et polyvalent, développé par la Fondation Raspberry Pi.
1. Caractéristiques de la Raspberry Pi 4 : La Raspberry Pi 4 est équipée d’un processeur Broadcom BCM2711, un quad-core Cortex-A72 (ARM v8) cadencé à 1,5 GHz, offrant des performances nettement supérieures aux générations précédentes. Elle dispose de plusieurs interfaces de communication et d’entrées/sorties essentielles pour notre application :
- 40 broches GPIO configurables pour différents usages.
- UART : 6 interfaces (dont certaines partagées avec d'autres fonctions)
- SPI : 6 interfaces matérielles.
- I²C : 6 interfaces matérielles.
- PWM : Jusqu'à 2 canaux matériels, plus d'autres via software.
- GPIO : 28 broches utilisables pour des entrées/sorties générales.
- Connectivité avancée :
- 2× USB 3.0 + 2× USB 2.0
- 2× micro-HDMI (résolution jusqu’à 4K)
- Ethernet Gigabit et Wi-Fi 5 GHz pour la communication réseau
- Slot microSD pour le stockage du système et des données
2. Pourquoi une Raspberry Pi 4 et non un microcontrôleur ? Contrairement aux microcontrôleurs comme les STM32 ou ESP32, la Raspberry Pi 4 dispose d’un système d’exploitation (Linux) qui permet d’exécuter plusieurs processus simultanément, ce qui est essentiel pour notre projet. Elle facilite également le développement grâce à la prise en charge de multiples langages de programmation (Python, C, C++, JavaScript, etc.), tandis que les microcontrôleurs nécessitent souvent un code unique compilé en firmware.

En comparaison avec les FPGA, bien que ceux-ci soient plus performants pour le traitement parallèle, ils nécessitent une programmation bas niveau (VHDL/Verilog) et ne disposent pas d’un système d’exploitation intégré, rendant la gestion des tâches complexes plus contraignante.

Avantages pour notre projet :

- Puissance de calcul suffisante pour le traitement du signal et l’analyse audio.
- Compatibilité avec un large éventail de capteurs et périphériques via ses nombreuses interfaces GPIO.
- Possibilité d’exécuter plusieurs scripts et processus en parallèle, notamment pour la gestion des signaux et l’interface utilisateur.
- Facilité d’utilisation et de développement (comparé à FPGA) grâce à un environnement Linux complet.

Grâce à ces caractéristiques, la Raspberry Pi 4 s’impose comme le choix idéal pour notre projet, offrant un équilibre optimal entre performance, flexibilité et accessibilité.

### D. Choix de langage de programmation

Pour programmer notre Raspberry Pi, nous avons décidé d’utiliser le langage C comme langage principal. Ce choix est principalement motivé par plusieurs raisons :

- Performance : Le langage C permet un contrôle précis sur les ressources matérielles et optimise l’utilisation du processeur, ce qui est essentiel dans un projet embarqué où la gestion des performances est cruciale, notamment pour le traitement audio en temps réel.
- Portabilité : Le C est largement utilisé dans les environnements embarqués et supporté par de nombreuses plateformes, ce qui garantit une bonne compatibilité et pérennité du projet.
- Bibliothèques et support : Le Raspberry Pi dispose de nombreuses bibliothèques en C, notamment pour interagir avec les périphériques GPIO, les interfaces série (comme UART pour MIDI), et d'autres modules nécessaires au bon fonctionnement du projet.

Par ailleurs, Bash est également utilisé dans le projet pour automatiser certaines tâches, telles que la gestion des processus de démarrage du système, la configuration initiale des périphériques ou l'exécution de scripts de maintenance. L'utilisation de Bash permet de simplifier l'administration et la configuration du système sans avoir à développer des scripts complexes dans des langages de plus haut niveau.

Enfin, Node.js est utilisé pour certaines parties du projet nécessitant une gestion d’événements asynchrones, notamment pour l’interface utilisateur ou la gestion de la communication réseau. Node.js est particulièrement adapté pour ces tâches en raison de sa nature non-bloquante et de sa capacité à gérer des entrées/sorties simultanées de manière efficace. Il permet également de développer des applications Web ou des interfaces simples pour interagir avec notre système via un navigateur, ce qui facilite la gestion et le contrôle du mixeur audio à distance.

## IV.Conception détaillée des fonctions

### A. Assurer la Fiabilité et maintenance

1. Système modulaire avec sous-systèmes indépendants L’architecture du système repose sur une conception modulaire visant à améliorer la flexibilité, la maintenance et l’évolutivité du dispositif. Cette approche permet d’individualiser les différentes fonctions du système en les répartissant sur plusieurs cartes distinctes.
1.1. Justification du découpage en modules Plutôt qu’un circuit unique intégrant l’ensemble des fonctionnalités, le choix d’une architecture modulaire a été retenu pour plusieurs raisons :
- Maintenance facilitée : En cas de panne ou d’évolution, il est possible de remplacer un module spécifique sans impacter l’ensemble du système.
- Optimisation de l’espace : Le montage avec des modules permet une conception plus compacte et structurée.
- Facilité d’assemblage et d’évolution : Des améliorations futures peuvent être intégrées en remplaçant ou en ajoutant de nouveaux modules.
1.2. Organisation des cartes Le système est structuré autour de deux types de cartes principales :
- Carte mère : Elle assure l’interconnexion entre les différents modules et gère l’alimentation et la distribution des signaux.
- Cartes modules : Chacune d’elles remplit une fonction spécifique et se connecte à la carte mère via un connecteur dédié. Ces cartes peuvent inclure des fonctions comme le conditionnement du signal, la conversion analogique-numérique (ADC), le traitement numérique ou l’amplification.
1.3. Connectique et assemblage Les cartes modules sont montées verticalement sur la carte mère à l’aide de connecteurs headers mâles coudés sur les modules et connecteurs femelles 2,54 mm sur la carte mère. Cette disposition permet un gain de place, une meilleure accessibilité aux composants et une maintenance facilitée, tout en garantissant une connexion robuste entre les différents éléments du système.

Figure 1 Organisation des cartes en montage verticale

Figure 2 Connecteur femelle 2.54mm

Figure 3 Connecteur mâle
angle droit 2.54mm

Figure 4 Vue 3D de montage verticale avec les connecteurs

2. Protection des entrées audio contre les surtensions (FT9-1) Pour garantir la fiabilité et la durabilité du système, plusieurs protections électriques sont prises en compte dans la conception :
- Protection contre les surtensions : les entrées du système intègrent des diodes TVS (Transient Voltage Suppression) afin d’absorber les pics de tension et de préserver les composants sensibles.

Deux circuits à diodes sont proposés : l’un utilisant une diode TVS, l’autre basé sur deux diodes Zener offrant un fonctionnement similaire.

Dans la simulation ci-dessous, une diode TVS bidirectionnelle est utilisée. On observe que celle-ci absorbe efficacement les pics de tension dépassant sa tension de claquage (bleu : entrée, vert : sortie).


Figure 5 Montage protection pics de surtension, avec doide TVS bidirectionnelle

De même, la simulation suivante illustre le comportement d’un circuit avec deux diodes Zener, permettant d’absorber les surtensions au-delà de la tension de claquage.


Figure 6 Montage protection pics de surtension avec 2 diodes Zeners

Ces circuits permettent de protéger les entrées de notre système contre les pics de surtensions, le 2eme on peut réaliser le 2eme montage avec les composants disponible à l’IUT, donc on choisit le 2eme montage.

- Circuits de clampage / Limitation de la tension des entrées analogiques : L’intégration de diodes Zener, Schottky ou d’un montage à amplificateur opérationnel permet de limiter la tension d’entrée des ADC à une valeur prédéfinie, assurant ainsi leur protection contre les surtensions (exemple : 3.3V pour les entrées audio).

Deux montages sont proposés : l’un utilisant une diode Zener, l’autre un amplificateur opérationnel.

La simulation suivante illustre le circuit de clampage avec une diode Zener (basé sur le même principe que montage en Figure 5 et Figure 6). Lorsque la tension aux bornes de la diode dépasse sa tension de claquage, celle-ci devient conductrice et limite la tension en sortie.


Figure 7 Circuit de clampage entrée analogique avec diode Zener

La simulation suivante montre le circuit de clampage utilisant un amplificateur opérationnel en montage non inverseur avec un gain de 1. La sortie de l’AOP ne pouvant pas dépasser sa tension d’alimentation, elle est automatiquement limitée lorsque la tension d’entrée excède cette valeur maximale.


Figure 8 Circuit de clampage entrée analogique avec AOP

Nous avons choisi d’utiliser le deuxième montage avec un AOP, car notre circuit intègre déjà des amplificateurs opérationnels. En limitant la tension d’alimentation de l’AOP, nous pouvons réaliser cette fonction. L’AOP sélectionné doit avoir une sortie Rail-to-Rail afin de garantir un fonctionnement optimal. L’un des modèles disponibles répondant à ces critères est le MCP6022, qui est également disponible dans le stock de l’université.

- Isolation galvanique : Afin de protéger les circuits sensibles et d’éviter les interférences, une isolation galvanique est envisagée sur certaines interfaces critiques, comme l’entrée MIDI et d’autres interfaces numériques.

Deux montages sont proposés, basés sur un optocoupleur à phototransistor.

Le premier montage, simple, est limité à une fréquence maximale d’environ 25 kHz. En effet, les caractéristiques internes du phototransistor imposent des temps de montée et de descente qui restreignent la fréquence de fonctionnement.


Figure 9 Montage simple optocoupleur à phototransistor, Fmax<=25kHz

Le montage suivant améliore les performances en utilisant le même optocoupleur, mais avec un circuit optimisé inspiré d’un schéma publié dans le livre Troubleshooting Analog Circuits de Bob Pease, le montage proposé avec un inverseur en sortie permet d’avoir une fréquence max d’environ 125kHz.


Figure 10 Montage améliorée optocoupleur à phototransistor. Fmax <= 125kHz

Ce circuit améliore le transfert de courant effectif (CTR) en ajoutant un transistor en sortie, permettant une meilleure commutation et une tension de sortie allant de rail à rail. Deux résistances supplémentaires optimisent également le temps de réponse :

- R1 accélère le temps de descente en tirant la base du transistor de sortie vers le bas.
- R2 applique une rétroaction positive sur la base du phototransistor, augmentant son courant de base lorsqu’il commence à conduire, ce qui accélère son activation.

Dans cette configuration, Pease recommande des valeurs de 2 MΩ pour R1 et 1 kΩ pour R2.

Ce circuit introduit un léger retard sur le signal de sortie, mais celui-ci reste négligeable dans le cadre de notre application et ne pose pas de problème de performance.

Le choix du montage utilisé dépendra de la fréquence des signaux à isoler afin d’assurer une transmission fiable et adaptée aux exigences du système.

Pour les signaux basés sur les spécifications MIDI, dont le baud rate est de 31 250 bauds, le montage de Buson amélioré basé sur l’optocoupleur à phototransistor 4N25 est un bon choix. Il peut également être remplacé par un 6N138, ces deux composants étant des optocoupleurs de type Darlington.

En revanche, pour les signaux à fréquences plus élevées, tels que I2C et SPI, ce montage n’est pas adapté. D’autres optocoupleurs, comme le 6N137, peuvent être utilisés. Ce dernier dispose d’une sortie numérique et peut gérer des signaux allant jusqu’à 10 MBd, ce qui le rend parfaitement compatible avec ces signaux.

Note : Au final les optocoupleurs n’étaient pas ajoutés dans le design de PCB car n’étaient pas disponible.


3. Protection des alimentations contre les courts-circuits

### B. Gestion de l’entrée audio analogique

1. Conditionner le signal analogique (filtrage) Le filtrage est une étape essentielle du conditionnement du signal analogique. Il permet d’éliminer les composantes indésirables, telles que le bruit haute fréquence ou les interférences, garantissant ainsi une meilleure qualité audio.

En plus de son rôle dans la purification du signal, le filtrage assure une entrée haute impédance, ce qui est crucial pour préserver l’intégrité du signal. Une haute impédance limite le courant entrant et empêche la source audio d’être « chargée », réduisant ainsi l’atténuation et la distorsion pour une transmission fidèle et sans perte de qualité.

Enfin, cette étape est essentielle pour l’adaptation du signal au traitement numérique, notamment en supprimant les fréquences supérieures à la bande utile afin d’éviter les artefacts tels que l’aliasing lors de la conversion analogique-numérique (CAN).

1.1. Choix du filtre : un filtre passe-bas actif d’ordre 2 Pour notre application, nous avons opté pour un filtre passe-bas actif de type Sallen-Key d’ordre
2. Ce choix offre un bon compromis entre simplicité de mise en œuvre, stabilité et efficacité dans l’atténuation des hautes fréquences.

Justification du choix d’un filtre d’ordre 4 :

Un filtre d’ordre 2 présente une pente d’atténuation de -12 dB/octave, ce qui est suffisant pour limiter les hautes fréquences au-delà de 20 kHz, tout en minimisant la complexité du circuit. Contrairement à un filtre d’ordre 4, il nécessite moins de composants actifs et réduit ainsi la consommation d’énergie et les erreurs de phase potentielles.

Caractéristiques du filtre :

- Type : Passe-bas actif (Sallen-Key)
- Ordre : 2
- Fréquence de coupure (fc) : 20 kHz
- Gain : Unité (1x) pour éviter toute amplification ou atténuation non souhaitée

Voici le montage du filtre d’ordre 2 :


Figure 11 Montage Filtre Sallen-Key d’ordre 2

L'élément actif est un amplificateur de tension de gain K. Idéalement, l'amplificateur doit avoir une impédance d'entrée assez grande pour pouvoir être considérée comme infinie, et une impédance de sortie nulle. Il réalise la fonction suivante :

Vs

(t) = KV1(t)

Pour un ampli-op idéal, la fonction de transfert est de la forme suivante :

H(ω) = A

K
1 + mj ω
ωc

+ (j

ω
ωc

)

2

Avec :

ω0 =

1
R√C1C2

m = 2√
C1
C2

+ √
C2
C1

(1 − K)

Pour concevoir le filtre et calculer précisément les valeurs des composants, nous allons utiliser Analog Filter Wizard développé par Analog Devices. Cet outil permet de réaliser des filtres en fonction des paramètres souhaités et fournit des suggestions optimisées pour garantir des performances optimales. Il facilite également la simulation et l'ajustement des valeurs afin d'obtenir la meilleure réponse en fréquence possible.

Lien vers le site : https://tools.analog.com/en/filterwizard/


Figure 12 Analog filter wizard

Figure 13 Paramètres de filtre sur Analog filter wizard

En utilisant le logiciel de conception de filtres, nous avons conçu le filtre suivant :


Figure 14 Filtre proposé par analog filter wizard en fonction des parametres

Il s'agit d'un filtre de second ordre Chebyshev, avec une ondulation de 0,07 dB dans la bande passante. Ce filtre présente des caractéristiques de réponse en fréquence telles que :

- Une atténuation de -1 dB à 20 kHz.
- Une atténuation de -3 dB à 26,5 kHz.

En ce qui concerne la phase, le filtre présente une variation qui atteint -72° à la fréquence maximale de 20 kHz. Cette phase montre l’effet de la réactivité du filtre aux hautes fréquences, un aspect important à prendre en compte pour éviter des distorsions indésirables dans le signal, surtout dans les applications audio où la précision de phase est cruciale pour la qualité du son.

Le choix du filtre Chebyshev de second ordre a été motivé par son excellent compromis entre la réponse en fréquence et la régularité de la phase dans les applications audio. Bien que ce type de filtre introduise une petite ondulation dans la bande passante, il permet d’obtenir des caractéristiques de coupure plus nettes et d’atteindre un niveau d'atténuation suffisant dans la bande de transition, ce qui est essentiel pour le traitement des signaux audio dans notre projet.


Figure 15 Diagramme de Bode (Gain) de filtre | Figure 16Diagramme de Bode (Phase) de filtre

2. Régulation du gain du signal Le signal provenant des sources telles que les instruments de musique n'est pas suffisamment amplifié pour être utilisé avec un convertisseur analogique-numérique (ADC), et pour exploiter pleinement la plage de mesure de ce dernier, il doit être adapté. Nous allons donc utiliser un amplificateur de tension pour adapter ce signal à l'entrée de l'ADC.

Les sources musicales ont une amplitude variante entre 50 mVpp et 1,65 Vpp, mais nous souhaitons obtenir un signal de sortie maximum de 0 à 3,3 V (soit un signal équivalent de 1,65 Vpp). Pour cela, un gain variable est nécessaire :

- Gain de 1 (pas d'amplification) si le signal d'entrée est de 1,65 Vpp,
- Gain de 33 si le signal d'entrée est de 50 mVpp, ce qui permettra d'obtenir 1,65 Vpp en sortie.

Pour obtenir ce gain réglable, nous allons utiliser un potentiomètre afin de permettre un ajustement manuel du gain en fonction des besoins.

2.1. Montage de l'amplificateur Le circuit d'amplification sera constitué de deux amplificateurs :
- Un amplificateur inverseur avec un gain variable allant de 0 à 33.
- Un second amplificateur inverseur avec un gain de 1.

Le second amplificateur est utilisé pour conserver la phase entre l'entrée et la sortie du système. Le premier amplificateur permet de régler le gain en fonction de l'amplitude du signal d'entrée, et le second amplificateur rétablit la phase tout en maintenant un gain unitaire pour éviter toute inversion de phase indésirable dans le signal amplifié.

Voici le montage d’un amplificateur inverseur :


Figure 17 Montage Amplificateur Inverseur

Le gain d’un amplificateur inverseur est de : Ve
Vs

= G = −

R2
R1

En mettant en série deux montages inverseurs, nous pouvons éliminer le signe négatif. L’avantage de cette configuration, comparée à d’autres comme le montage non-inverseur, est qu’elle permet d’obtenir un gain minimum de 0.

Voici le schéma de notre système :


Figure 18 Montage 2 régulation du gain du signal

Un potentiomètre est utilisé dans le premier montage, permettant de régler le gain.

3. Application d’un décalage sur le signal analogique Le signal audio provenant des instruments de musique est un signal alternatif (AC), ce qui signifie qu’il comporte des parties négatives. Or, ces signaux ne sont pas adaptés aux circuits numériques, tels que les convertisseurs analogique-numérique (CAN), les microcontrôleurs et d’autres composants numériques, qui pourraient être endommagés par des tensions négatives.

Pour éviter cela, nous devons ajouter une composante continue (DC) à notre signal, également appelée offset ou décalage DC. Cet ajout permet de décaler le signal vers des valeurs strictement positives, le rendant compatible avec les circuits numériques tout en préservant son intégrité.

3.1. Source de tension stable et fixe L'ajout d’un décalage DC nécessite une tension de référence stable et fixe pour assurer un décalage constant du signal, sans fluctuations indésirables.

Nous utilisons un régulateur de tension pour générer cette tension de référence. Comparé à d’autres solutions, comme une référence basée sur une diode Zener ou des circuits similaires, le régulateur de tension offre une meilleure stabilité, une précision accrue, et réduit la sensibilité aux variations de charge et de température. En effet, les diodes Zener peuvent être sujettes à des variations de tension en fonction du courant qui les traverse, ce qui peut entraîner une instabilité de l’offset.

Le montage suivant utilise un potentiomètre multi tour de précision, permettant d'ajuster précisément la tension de référence et donc l’offset appliqué au signal.


Figure 19 Régulateur de tension variable/programmable pour une référence de tension stable


Figure 20 Montage simplifié regulateur de tension variable/programable.

Pour que la référence de tension soit réglable, la tension en sortie de montage d’un régulateur de tension de variable se définie par la relation suivante :

Vout = 1.25 ∗ (1 +
R1′

R3′)

Dans le montage simplifié (Figure 20), la valeur de R3' est fixée, tandis que R1' est réglable, ce qui permet un ajustement précis du circuit. Cependant, si R1' était un potentiomètre unique, Vout pourrait descendre jusqu'à 1.25V, ce qui n’est pas idéal pour un réglage de précision.

Pour pallier ce problème, le montage présenté en Figure 19 propose une solution améliorée. Il utilise une résistance fixe R2 en parallèle avec un réseau de deux résistances en série (R2 + R4), où R4 est un potentiomètre. Cette configuration permet de régler la tension dans une plage définie autour de 3.3V, évitant ainsi d'atteindre des valeurs trop basses qui compromettraient la précision du réglage.

Cella nous donne l’expression suivante :

Vout = 1.25 ∗ (1 +
R1

′ =

R1(R2 + R4)
R1 + (R2 + R4)

R3 = R3′ )

3.2. Montage Offset
Pour ajouter un offset au signal audio, nous utilisons un amplificateur différentiel, qui permet d'additionner la tension de référence à notre signal tout en maintenant une bonne linéarité et une faible distorsion. Ce montage garantit que le décalage DC est appliqué de manière uniforme, sans altérer les caractéristiques du signal d'origine.

Principe du montage différentiel :


Figure 21 Montage amplificateur différentiel

L’amplificateur opérationnel (AOP) est supposé idéal et fonctionne en régime linéaire, ce qui signifie que ses entrées sont à des tensions égales :

V+ = V−

La tension V+ est obtenue via un pont diviseur de tension, tandis que V−est déterminée par le théorème de Millman :

V+ = V2 (

R2
R1 + R2

)

V− =

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
V1R2 + VsR1
R1 + R2

or, puisque V+ = V− =

V2R2
R1 + R2

=

V1R2 + VsR1
R1 + R2

⇔

V2R2
R1 + R2

= (V2 − V1

)

R2
R1 + R2

⇔ Vs =

R2
R1

(V2 − V1

)

En choisissant R1 = R2, nous obtenons l'expression suivante :

Vs = V2 − V1

3.3. Justification et mise en œuvre Nous avons choisi V2 comme tension de référence, car nous souhaitons ajouter un offset positif au signal. Cela signifie que le signal d’entrée doit être appliqué sur V1 (entrée inverseuse).

Ce choix entraîne une inversion de phase du signal, ce qui n'est pas problématique en soi. Si nécessaire, un montage inverseur en amont permettrait de rétablir la phase d'origine.

Pour notre application, nous devons ajouter un offset de 1.65V à un signal audio de 1.63Vpp, afin d’obtenir un signal compatible avec un système numérique en 0 - 3.3V.

En choisissant R1 = R2, la tension sur l'entrée non inverseuse V+ est divisée par 2, ce qui signifie que pour obtenir un décalage de 1.65V, il faut appliquer une tension de 1.65 V / 2 = 825mV sur l'entrée V+.

Le pont diviseur de tension doit donc réduire la tension de référence de 3.3V à 825mV, soit : 3.3V
4

= 825mV

Le montage réalisé suit donc la fonction :

Vs = −Vin + 1.65

Dans la simulation suivante, nous pouvons observer que l’offset est bien appliqué à notre signal, bien que celui-ci soit inversé.


Figure 22 Simulation Offset avec montage différentiel

4. Conversion du signal analogique en numérique Après avoir conditionné le signal analogique, il est nécessaire de le numériser à l'aide d'un convertisseur analogique-numérique (ADC).

Contrairement à la plupart des microcontrôleurs, notre micro-ordinateur ne possède pas d’ADC intégré, nous devons donc utiliser un convertisseur externe.

Pour un signal audio, la qualité minimale recommandée est de 16 bits avec une fréquence d’échantillonnage de 44,1 kHz, soit un débit de 705 kbps sans compression. La fréquence maximale audible par l’oreille humaine est d’environ 20 kHz. Selon le théorème de Nyquist, la fréquence d’échantillonnage doit être au moins deux fois supérieure pour éviter la perte d’information. En choisissant 44,1 kHz, nous respectons cette condition tout en optimisant la taille des données à traiter.

Représentation de numérisation d’un signal et impact selon la fréquence d’échantillonnage :


Figure 23 Numérisation d'un signal et impact de fréquence d'échantillonnage

Voici un tableau présentant les différentes qualités standards :


Figure 24 Tableau présentant quelques exemples des standard qualité audio

Ce choix correspond à une qualité "High Fidelity" (44,1 kHz, 16 bits). Toutefois, une qualité inférieure avec une fréquence d’échantillonnage et une résolution réduites reste envisageable si la priorité est de minimiser la quantité de données.

4.1. Choix du Convertisseur Analogique-Numérique Nous avons sélectionné l’ADC suivante qui communique en utilisant le SPI :

MCP3564 : ADC 24 bits, jusqu’à 8 canaux, utilisant une architecture ΔΣ (Delta-Sigma). Il offre une meilleure résolution et une faible distorsion, idéal pour des applications nécessitant une grande précision.

Fréquence d’échantillonnage : 44kHz par canal donc 88kHz pour 2.

En sélectionnant mode OSR total 32. La fréquence MCLK doit être de 11.265MHz pour avoir cette configuration. Pour cella on utilise l’horloge externe généré par la Raspberry pi.

4.2. Filtre anti repliement La fréquence d’échantillonnage réel est de 1.408MHz donc pour le filtre anti repliement on peut choisir un filtre d’ordre plus petit.

### C. Gestion de l’entrée audio numérique

Le MIDI (Musical Instrument Digital Interface) intervient dans le contrôle des instruments de musique tels que les échantillonneurs ou synthétiseurs dédiés ou intégrés aux ordinateur sous forme de cartes. Le MIDI permet également de contrôler les consoles de mixage, des processeurs d'effets et des systèmes d'enregistrement.

Le MIDI est une interface de contrôle sérielle originellement dédiée aux systèmes musicaux. Mais il a rapidement débordé de sa vocation première et intervient aujourd'hui dans le contrôle d'un large éventail de matériel non seulement audio, mais destinés à l'éclairage du spectacle.

Le protocole MIDI intègre de nombreux paramètres de commande, la majorité d'entre eux étant librement affectables par l'utilisateur en fonction de ses besoins. Il est possible de contrôler des instruments de musique polyphonique en temps dit pseudo-réel : les temps de transmission ne sont pas perceptibles dans la majorité des cas. Il est également possible d'adresser plusieurs appareils différents sur le même flot de données MIDI.

Le MIDI est un moyen économique de contrôler et stocker des informations sonores. En comparaison avec de l'audionumérique échantillonné (16 bits/44100 Hz) qui peu requérir un espace de stockage très important, les informations MIDI pour une minute de musique peuvent tout à fait ne pas excéder 5 ko. De même la charge de travail imposée à un ordinateur est beaucoup plus faible avec du MIDI qu'avec de l'audio.

1.1. Connectique et interface MIDI Historiquement, le MIDI utilise un connecteur DIN 5 broches, mais depuis MIDI 2.0, une alternative est le mini-jack TRS 2,5 mm, plus compact et couramment utilisé sur les appareils récents. L’adaptation entre DIN-5 et TRS est possible avec un câblage approprié.

Afin d'utiliser un ordinateur comme contrôleur central dans un système MIDI, il faut disposer d'une interface MIDI. Chaque interface MIDI possède au moins un port IN et un port OUT. Le port THRU n'est pas toujours nécessaire.

1.2. Transport des données MIDI Le standard MIDI spécifie une interface sérielle unidirectionnelle fonctionnant à 31.24 kbits (à + ou - 1 %). Ce taux a été fixé à l'époque où la vitesse des microprocesseurs était beaucoup plus basse qu’aujourd’hui : ce taux était une division pratique d'un taux d'horloge maître type de 1 ou 2 MHz. Le taux devait de plus être suffisamment bas pour assurer une transmission sans perte sur des câbles et interfaces simples, tout en autorisant un délai de transmission raisonnable entre instruments.

La transmission des données est unidirectionnelle entre le transmetteur et le récepteur. Le retour requiert une liaison MIDI séparée.

Les messages de contrôle sont transmis par groupes d'octets précédés par un bit de début et suivis par un bit de fin à chaque octet afin de synchroniser la réception des données, la transmission étant asynchrone.

L'addition des bits de début et de fin indique que chaque mot de 8 bits occupe en fait une période de 10 bits à la transmission (pour une durée totale de 320 microsecondes). Un message MIDI typique consiste en un, deux ou trois octets. Certains messages spéciaux peuvent toutefois être plus longs.

1.3. Canaux MIDI
Les messages MIDI sont constitués d'un certain nombre d'octets. Chaque partie du message a une vocation spécifique, l'une d'entre elles étant de définir le canal de réception auquel le message est destiné. De cette façon, un appareil de contrôle peut adresser ses données à un appareil de réception de manière spécifique.

Un appareil réglé pour recevoir un ou plusieurs canaux donnés réagit uniquement aux informations qui sont adressées à ces canaux et ignorent les autres.

A la base, il existe 16 canaux MIDI et les instruments peuvent être réglés en vue de recevoir spécifiquement sur un ou plusieurs de ces canaux, ou sur tous les canaux à la fois.

La limite de 16 canaux peut être dépassée en utilisant une interface multiport connectée à un ordinateur. Chacun des ports physique de l'interface peut alors prendre en charge 16 canaux MIDI.

1.4. Structure des messages MIDI A la base, il existe deux types d'octets de message MIDI : l'octet de statut et l'octet de données.

Sur les huit bits de ces octets, seuls sept sont actifs car le premier bit de chaque octet est réservé à la qualification du type (statut ou données) ce qui offre donc 2 puissance 7 (128) valeurs possibles.

Les octets de statut débutent toujours par un 0.

La première moitié (3 bits) de l'octet de statut indique le type de message. Cela donne donc 8 types de messages possibles. Il existe cependant des cas particuliers avec les message systèmes.

La seconde moitié le numéro de canal (4 bits) est attribuée à la définition du numéro de canal auquel le message est adressé. Cela offre 2 puissance 4 (16) canaux possibles.


Figure 25 Trame MIDI

Les messages MIDI standards peuvent avoir une longueur de 3 octets mais ce n'est pas le cas général, et certains cas assez communs font exception à la règle.


Le tableau suivant résume le format et le contenu des principaux types de message MIDI.

Figure 26 Format et le contenu des principaux types de message MIDI.

Le tableau des notes dans un message MIDI :

Figure 27 Notes MIDI

2. Synchronisation des horloges MIDI avec le traitement audio La synchronisation des horloges MIDI avec le traitement audio est un aspect crucial pour assurer que les événements MIDI (comme le déclenchement de notes ou de changements de contrôleurs) se produisent au moment exact dans le traitement audio.

Le MIDI TimeCode (MTC) est très exploité comme moyen de synchroniser des équipements contrôlés par MIDI avec une véritable référence temporelle. Les interfaces MIDI multiports disposent généralement d'un port de timecode SMPTE/EBU qui permet de lire et d'écrire du timecode longitudinal (LTC). Le LTC est converti en MTC et peut ainsi être géré par un logiciel MIDI.

Dans une trame de timecode LTC, deux groupes de données binaires sont alloués aux heures, minutes, secondes et images, ces groupes représentant respectivement les dizaines et les unités de chaque section, ce qui donne au total huit groupes binaires. Ce format doit être converti en un format compatible avec les autres données MIDI (octet de statut suivi par les octets de données).

Il existe deux types de message de synchronisation MTC :

Le premier (full-frame) met à jour le récepteur régulièrement. Il est transmis sous la forme d'un message en système exclusif universel en temps réel.

Le second (quarter-frame) met à jour la position du timecode en une fois, dans des situations comme l'avance rapide. Il est dénoté par l'octet de statut (&1F).

Comme une trame de timecode comporte trop d'informations pour pouvoir être transmise sous la forme standard du message MIDI à 3 octets. Elle est donc tronçonnées en 8 messages séparées (quarter-frame). Quatre de ces message sont transmis à chaque trame de timecode afin de limiter le taux de transmission. Chaque message du groupe de huit représente une partie de la valeur du timecode et prend la forme générale : & [F1] [ Données].


Figure 28 Format message MIDI Timecode

3. Conversion des données MIDI en signal audio La conversion des données MIDI en un signal audio réel est un processus clé qui permet de transformer les informations de contrôle MIDI en une sortie sonore. MIDI étant un protocole de données numériques ne générant pas directement de son, il faut un moteur de synthèse pour traduire ces données en un signal audio analogique ou numérique. Ce processus est réalisé grâce à un moteur de synthèse audio qui peut interpréter les messages MIDI reçus et générer un signal sonore en conséquence.

Les données MIDI, telles que les événements de note, les contrôleurs et les messages de changement de programme, sont utilisées pour activer des instruments virtuels ou des échantillons audio. Cela se fait généralement par deux approches principales : la synthèse par échantillonnage et la synthèse par modélisation physique. La synthèse par échantillonnage consiste à jouer des enregistrements préenregistrés de sons instrumentaux, alors que la synthèse par modélisation physique génère des sons à partir de modèles mathématiques des instruments.

Le signal audio généré peut être au format .wav, qui est un format standard pour les fichiers audio non compressés, ou un autre format approprié selon les besoins du système (par exemple, .aiff ou .flac pour la gestion d'audio compressé ou de haute qualité). Une fois les données MIDI converties en audio, ces signaux sont traités par le système de mixage, où ils peuvent être ajustés, modifiés et fusionnés avec d’autres signaux audio dans un environnement en temps réel.

La conversion MIDI vers audio dans ce projet est un élément essentiel pour permettre à l'Orchestrion de recréer des performances musicales en combinant les divers instruments MIDI et en les intégrant dans une composition sonore cohérente. Cela ouvre également la possibilité d'utiliser des effets audio comme la réverbération, la modulation ou le filtrage, afin d'ajuster le son final généré par les signaux MIDI.

### D. Traitement numérique du signal audio

1. Application de filtres et algorithmes de mixage numérique
2. Gestion du mixage audio en temps réel
3. Fournir un IHM pour la gestion des paramètres de mixage et effets.
4. Restitution du signal audio traité
5. Sortie stéréo ou ligne pour restitution sonore

### E. Amplification du signal audio

1. Amplification en tension et en courant pour restitution optimale

### F. Gestion de l’alimentation électrique

1. Alimentation via batterie rechargeable
2. Recharge via adaptateur secteur ou alimentation DC

### G. Format compact et ergonomie

1. Conception d’un boîtier robuste et léger
2. Optimisation des dimensions pour transport et intégration

## V. Développement en cours et prochaines étapes

Programmation ADC – SPI

Communication entre différentes programmes MIDI – SPI(ADC) - IHM

## ANNEX

Simulations :

Les Fichiers de simulations seront disponibles sur l’espace d’hébergement git (github et gitlab).

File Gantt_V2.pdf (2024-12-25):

24 | 30 | 7 | 14 | 21 | 28 | 4 | 11 | 18 | 25 | 2 | 9 | 16 | 23 | 30 | 6 | 13 | 20 | 27 | 3 | 10 | 17 | 24 | 3 | 10 | 17 | 24 | 31 | 7 | 14 | 21 | 28
9/24 | 10/24 | 11/24 | 12/24 | 1/25 | 2/25 | 3/25 | 4/25
Projet SAE | 0h | 16%
Initiation du Projet Jalons et livrab... | 0h | 68%
Recherche Bibliographique | 0 | 100%
Etude du Besoin et Analyse Fonctio... | 0 | 100%
Redaction CdC | 0 | 100%
Repartition des Taches | 0 | 100%
CdC sous systèmes | 0 | 10%
Liste de materiel | 0 | 0%
Dossier de conception | 0 | 0%
Document de fabrication électroniq... | 0 | 0%
Procédures et rapports de tests des ... | 0 | 0%
Procédure et rapport de maintenanc... | 0 | 0%
Prototype opérationnel | 0 | 0%
Soutenance S5 | 0 | 0%
Dossier d'oeuvre exécuté | 0 | 0%
Procédures et rapports de tests du s... | 0 | 0%
Procédure et rapport de maintenanc... | 0 | 0%
Procédure d'installation et de mise ... | 0 | 0%
Prototye opérationnel | 0 | 0%
Presentation Finale : Soutenance S6 | 0 | 0%
Flux Signaux Numerique : Raspber... | 0h | 21%
Recherches Sous Partie | 0 | 100%
Initialisation Raspberry pi 4 | 0 | 100%
Réception données Midi | 0 | 0%
CNN données MIDI | 0 | 0%
Synchroniser le flux de données | 0 | 0%
Flux Signaux Analogique | 0h | 11%
Conditionnement de signal | 0 | 30%
Conversion Analogique Numerique | 0 | 40%
Conversion Numerique Numerique | 0 | 0%
Synchronisation des Données | 0 | 0%
Envoie vers Raspberry | 0 | 0%
Conception PCB | 0 | 0%
Gestion donnees audio / effets | 0h | 0%
Ajouter les effets | 0 | 0%
IHM | 0h | 0%
1er Interface | 0 | 0%
Restitusion de signal Sonore | 0h | 0%
Amplification | 0 | 0%
Conversion Numerique Analogique | 0 | 0%
Tester des solutions pour l’ampli aud... | 0 | 0%
Alimentation | 0h | 0%
Alimentation principale | 0 | 0%
Alimentation Batterie | 0 | 0%
Systeme de Recharge | 0 | 0%
Systeme de Protection | 0 | 0%
CAO 3D | 0h | 0%
Modéliser la boite pour le prototype | 0 | 0%
Imprimer la boite | 0 | 0%

Recherche Bibliographique

Repartition des Ta; CdC sous systèmes; Recherches Sous Partie; Initialisat; Réception données Midi; CNN données MIDI; Synchroniser le flux de données; Conditionnement de signal; Conversion Analogique; Conversi; Synchronisation des Données; Envoie vers Raspberry; Conception PCB; Ajouter les effets; 1er Interface; Amplification; Conversion Numerique Analogique

Etude du Besoin et Analyse Fonctionnelle

Redaction CdC

Tester des solutions pour l’ampli audio déterminer la solution finale

Alimentation principale

Alimentation Batterie

Systeme de Recharge

Systeme de Protection

Modéliser la boite pour le pr

Im

Powered by TCPDF (www.tcpdf.org)

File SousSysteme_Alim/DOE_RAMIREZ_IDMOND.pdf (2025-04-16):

11/04/2025 | Version : 1.0 | 1

CY IUT – GEII Neuville

# Dossier d’œuvre exécuté

## Sous système: Alimentation et CAO

### Document rédigé par : « RAMIREZ Victor » Version : 1.0 – 11/04/2025

## Avant-propos

Dans le projet “Table de mixage”, il faut plusieurs tensions stables pour alimenter les cartes électroniques, les actionneurs et certains modules analogiques. Pour cela, une alimentation spécifique a été développée. Elle utilise un chargeur de PC comme source principale et transforme le 19V fourni en plusieurs tensions nécessaires au projet. Nous avons aussi été chargé de la conception assistée par ordinateur (CAO) du boîtier destiné à accueillir les éléments électroniques de la table de mixage automatique. Cette conception vise à répondre aux contraintes d’intégration physique des composants (Raspberry Pi, alimentation, cartes électroniques), tout en assurant robustesse, accessibilité, et bonne circulation de l’air. Ce document explique le fonctionnement, les choix techniques, les tests et les pistes d’amélioration de cette alimentation.

## Table des matières


11/04/2025 | Version : 1.0 | 4

## 1. Alimentation

### 1.1. Présentation du système d’alimentation

On utilise un chargeur de PC qui fournit 19V pour 3.4A. À partir de cette tension, on crée du 5V et du 3.3V avec deux convertisseurs Buck commandés par un NE555. Le NE555 est alimenté grâce à une diode Zener de 12V avec résistance série, car il consomme très peu. On crée aussi une tension symétrique ±9.5V à partir de la masse virtuelle, utile pour les parties analogiques. On appelle cela convertisseur Buck car ce type de convertisseur permet de réduire la tension d’entrée tout en conservant un bon rendement. C’est un convertisseur abaisseur (step-down) à base de composants discrets : interrupteur (MOSFET), diode, inductance et condensateurs.

### 1.2. Schéma de principe

Le schéma de principe ci-dessous illustre la répartition des tensions depuis l’entrée 19V fournie par un chargeur de PC. On observe la régulation vers 12V via une diode Zener pour alimenter le NE555, puis la génération des tensions 5V et 3.3V à travers deux convertisseurs Buck. Une masse virtuelle permet également de créer une tension symétrique ±9.5V, essentielle pour les modules analogiques.

### 1.3. Conception et fabrication

Le système d’alimentation a été conçu pour transformer une seule tension d’entrée de 19V, fournie par un chargeur de PC (3.4A), en plusieurs tensions adaptées aux besoins du projet : 5V, 3.3V et ±9.5V. Ces tensions alimentent les actionneurs, les cartes de contrôle et les circuits analogiques.

Convertisseurs Buck

On utilise deux convertisseurs Buck pour obtenir 5V et 3.3V.

Chaque convertisseur est composé de :

- Un NE555 configuré en oscillateur pour générer un signal PWM
- Un MOSFET piloté par le NE555
- Une diode Schottky, une bobine et un condensateur pour lisser la tension

Le rapport cyclique du signal du NE555 détermine la tension de sortie du Buck. Pour pouvoir régler cette tension plus précisément, on a intégré un potentiomètre multi-tours dans le circuit du NE555. Cela permet d’ajuster avec précision le rapport cyclique et donc d’obtenir une tension stable et bien réglée selon les besoins (5V ou 3.3V).

Pourquoi on appelle ça un convertisseur Buck ?

Le terme “Buck” vient de l’anglais et signifie réduction. Un convertisseur Buck est un circuit électronique qui abaisse une tension d’entrée élevée (ici 19V) vers une tension plus basse, tout en conservant un bon rendement. C’est un convertisseur de type step-down.

Alimentation du NE555 et masse virtuelle

Le NE555 est alimenté par une diode Zener de 12V avec une résistance série, car il ne consomme que très peu de courant.

Ensuite, pour obtenir une tension symétrique ±9.5V, on crée une masse virtuelle à partir de deux résistances identiques montées en pont diviseur, un AOP, des transistors et des condensateurs entre le +19V et la masse. Le point milieu devient une référence virtuelle.

Cette tension symétrique est utile pour les modules analogiques qui nécessitent un signal centré autour de 0V.

Réalisation sur plaque lab

Pour le moment, on n’a pas encore fabriqué le PCB. Tous les tests ont été faits sur plaque lab. Chaque convertisseur a été câblé séparément. On a respecté l’ordre logique des composants : NE555, MOSFET, diode, self, condensateur.

Les tests ont montré que les tensions étaient stables. Le potentiomètre multi-tours facilite beaucoup l’ajustement des 5V et 3.3V.

On a fait des tests de continuité avec un multimètre, puis des mesures de tension à vide et en charge. Le montage est stable et aucun composant ne chauffe anormalement.

On a aussi utilisé un oscilloscope pour observer le signal PWM du NE555. Le signal est propre, et la sortie en tension ne présente pas de bruit important.

Voici le schéma final de l’alimentation :


### 1.4. Dimensionnement de l’alimentation

Pour s’assurer que notre alimentation est adaptée, on a realisé un tableau des besoins. Il indique les tensions, les courants et les puissances minimales et maximales nécessaires au bon fonctionnement du projet.

Tension (V) | I Min (A) | I Max (A) | P Min (W) | P Max (W)
9 | 1 | 2 | 9 | 18
-9 | 1 | 2 | 9 | 18
5 | 3 | 5 | 15 | 25
3.3 | 1 | 2 | 3.3 | 6.6
Total | | | 36.3 | 67.6

Notre alimentation 19V-3.4A délivre 64.6W (19x3.4), ce qui est suffisant vu que tous les composants ne sont pas actifs à la fois. On a donc une marge acceptable, et le système est bien dimensionné.

### 1.5. Procédure de mise en service

Avant de connecter les autres sous-systèmes au système d’alimentation, il est important de suivre les étapes suivantes afin d’assurer une mise en service sécurisée et fonctionnelle :

Étapes de mise en service :

1. Inspection visuelle du circuit
- Vérifier l’intégrité du câblage (aucun fil dénudé ou mal connecté).
- S’assurer qu’il n’y a pas de court-circuit visible sur la plaque lab.
- Contrôler la polarité des composants sensibles (diodes, condensateurs, NE555, etc.).
2. Branchement de l’alimentation principale
- Connecter le chargeur de PC 19V – 3.4A à l’entrée du circuit.
- S’assurer que la tension est bien de 19V avant toute mise sous tension.
3. Mise sous tension et premières vérifications
- Mettre le système sous tension sans charge connectée.
- Mesurer la tension de la diode Zener : elle doit fournir environ 12V pour alimenter le NE555.
- Vérifier le signal PWM en sortie du NE555 à l’aide de l’oscilloscope.
4. Contrôle des tensions de sortie
- Mesurer la tension de sortie du convertisseur Buck 1 : elle doit être proche de 5V.
- Mesurer la tension de sortie du convertisseur Buck 2 : elle doit être proche de 3.3V.
- Ajuster les potentiomètres si nécessaire pour obtenir les valeurs cibles.

5. Contrôle de la masse virtuelle
- Mesurer la tension entre la masse virtuelle et les bornes + et - : les tensions doivent être symétriques (environ +9.5V et -9.5V).
- Vérifier la stabilité avec ou sans charge légère.
6. Connexion des sous-systèmes
- Une fois toutes les tensions vérifiées, connecter les cartes logiques, modules analogiques et actionneurs.
- Refaire les mesures sous charge pour s’assurer que les tensions restent stables.
7. Test global
- Vérifier que tous les sous-systèmes réagissent normalement et que le système fonctionne sans échauffement anormal.
- Utiliser un multimètre ou une caméra thermique (si disponible) pour un dernier contrôle.

### 1.6. Maintenance

Préventive
Contrôle visuel :

Inspecter les condensateurs électrolytiques : vérifier l’absence de gonflement ou de fuite.

Vérifier l’état des connecteurs, des fils et des soudures (pas de corrosion ni de dessoudage).

Comportement thermique :

Contrôler les échauffements des MOSFETs, diodes et bobine avec le doigt ou une caméra thermique (si disponible). Une température anormale indique souvent une surcharge ou un dysfonctionnement.

Tests électriques :

Vérifier les tensions de sortie à vide avec un multimètre.

Vérifier le signal PWM à l’oscilloscope en sortie du NE555.

Mesurer la tension aux bornes de la masse virtuelle pour s’assurer qu’elle reste centrée.

Corrective

Perte de tension en sortie :

- Vérifier la présence du signal PWM en sortie du NE555.

- Contrôler la continuité du circuit (test diode sur MOSFETs, diodes Schottky, etc.).
- Remplacer tout composant défectueux (Zener, MOSFET, diode, bobine…).

Instabilité des tensions :

- Contrôler les condensateurs de filtrage : leur vieillissement peut provoquer des oscillations ou du bruit.
- Vérifier que le potentiomètre du NE555 n’a pas été déréglé.

Surchauffe localisée :

- Vérifier la dissipation thermique (radiateurs si présents).
- Remplacer les composants surchauffés.

### 1.7. Améliorations possibles

Voici plusieurs pistes d’optimisation du système :

- Ajout de régulation par rétroaction (feedback)

Actuellement, la régulation se fait manuellement via un potentiomètre.

- Intégrer une boucle de rétroaction avec un amplificateur d’erreur (type TL431) permettrait une régulation automatique et plus précise.
- Ajout de voyants de statut
- Des LEDs (avec résistances en série) sur les sorties 3.3V et 5V permettent une vérification visuelle immédiate du bon fonctionnement.
- Protection à l’entrée
- Ajouter une diode de protection contre l’inversion de polarité par exemple diode Schottky
- Ajouter un fusible pour éviter les surintensités.
- Intégration sur PCB

Cela permet aussi de réduire les interférences et d’avoir une meilleure dissipation thermique.

- Filtrage

Ajouter des condensateurs céramiques supplémentaires proches des circuits sensibles pour réduire le bruit haute fréquence.

Le pcb a été finalisé le voici :


## 1. CAO

### 3.1 Présentation du boitier

Le boîtier a été conçu pour accueillir et protéger les composants électroniques de la table de mixage, notamment le Raspberry Pi, les cartes d’interface et l’alimentation. Il est composé de deux parties : un socle pour fixer les composants et un couvercle amovible.

Modélisé sur Onshape, il inclut des ouvertures précises pour les ports USB, l’alimentation et les entrées audio, ainsi que des fentes de ventilation. Il est adapté à une impression 3D en PLA ou PETG, et pensé pour être à la fois compact, accessible et simple à assembler.

### 3.2 Conception sur Onshape

La modélisation a été réalisée sur le logiciel Onshape, choisi pour sa compatibilité en ligne, sa simplicité d’utilisation, et ses outils collaboratifs.

Le boîtier final est rectangulaire et divisé en plusieurs parties :
- Un couvercle supérieur amovible pour l’accès aux composants.
- Des ouvertures latérales pour les ports USB et d’alimentation du Raspberry Pi.
- Des ouvertures avant/arrière pour les autres connecteurs audio.
- Des supports internes permettant la fixation stable du Raspberry Pi à l’aide d’entretoises

### 3.3 Avantage sur Onshape

Le choix d’Onshape s’est révélé stratégique pour ce projet. Contrairement à des logiciels comme SolidWorks (très lourd, nécessite une licence coûteuse) ou Fusion 360 (limitations dans la version gratuite), Onshape est gratuit, accessible depuis un navigateur et idéal pour le travail collaboratif.

Il permet également de travailler à distance sans perdre les fichiers, de partager facilement la modélisation avec les membres du groupe ou les enseignants et de gérer les versions automatiquement (historique des modifications intégré)

### 3.4 Résultat final de la conception

Vue basse
gauche

Vue basse
droite

Vue haute
droite

Vue haute
gauche
Vue arriere | Vue avant

Emplacement
enceinte

Emplacement
USB,ethernet

A l’interieur :
Vue sur les
emplacement
s des PCB

A l’interieur :
Vue sur les
emplacemen
ts des PCB

Passage câble
d’alimentation

écran

Données :

- Dimensions extérieures approximatives : 240 mm (L) x 200 mm (l) x 200 mm (H)
- Matériau prévu : PLA ou PETG
- Méthode de fabrication choisie : Impression 3D
- Nombre de pièces : 2 (boîtier + couvercle)
- Fixation prévue : emboîtement simple, possibilité de visser si nécessaire
- Ventilation : fentes latérales présentes sur les côtés du boîtier

### 3.5 Maintenance Préventive

La maintenance préventive vise à éviter les pannes ou dysfonctionnements en effectuant des vérifications régulières sur les composants du système. Pour le boîtier et ses éléments internes, les actions suivantes sont recommandées :
- Contrôle de l’état du boîtier (fissures, déformations, usure des fixations)
- Vérification de l’aération : nettoyage des ouvertures pour éviter l’accumulation de poussière
- Inspection visuelle des connecteurs : s’assurer qu’ils ne sont pas desserrés ou obstrués
- Contrôle du serrage des vis internes (Raspberry Pi, entretoises)
- Test de bon fonctionnement des ports (USB, alimentation, audio) à intervalles réguliers

Ces actions peuvent être planifiées tous les 3 à 6 mois selon l’utilisation du système.

### 3.6 Maintenance Corrective

La maintenance corrective intervient en cas de dysfonctionnement ou de dommage. Voici les principales opérations à prévoir :
- Remplacement du boîtier en cas de casse suite à un choc ou à une mauvaise manipulation
- Réimpression de pièces endommagées (ex : couvercle fissuré, supports cassés) si le boîtier est imprimé en 3D
- Réparation ou remplacement de fixations internes (entretoises, vis desserrées ou manquantes)
- Réajustement des ouvertures si un nouveau composant remplace un ancien et modifie les dimensions
- Nettoyage ou remplacement des ports si l’un d’eux devient inaccessible ou défectueux

La maintenance corrective est effectuée à la demande, suite à un incident ou à un diagnostic lors d’un contrôle préventif.

### 3.7 Problèmes rencontrés

Les problèmes rencontrés on surtout était lié à l’ajustement des ouvertures aux vraies dimensions des ports du Raspberry Pi ou à la création des emplacements stratégique de chaque pcb.

### 3.8 Amélioration possible

- Ajouter un système de verrouillage du couvercle (vis ou charnières)
- Intégrer des patins antidérapants en dessous du boîtier
- Optimiser l’aération avec des grilles imprimées plus larges ou un espace pour ventilateur

### 3.9 Annexes

Lien Onshape du projet : Accéder à la modélisation (https://cad.onshape.com/documents/032326b3787c1e76715cad98/w/7b044c102994627b340a6dc8/e/e7f3cf3d5f06f05159f7ded6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)

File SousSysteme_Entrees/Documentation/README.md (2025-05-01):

# Documentation du Sous-Système Entrées

## Dossiers

### [PRESENTATION](PRESENTATION)
Contient les supports de présentation liés au sous-système.

### [SCHEMAS](SCHEMAS)
Contient les schémas, blocs fonctionnels et autres représentations techniques.

---

## Documents

### [Doc_Conception_SS_EA_et_N.pdf](Doc_Conception_SS_EA_et_N.pdf)
Document de conception du sous-système Entrées Analogiques et Numériques.

### [Doc_Fabrication__SS_EA_et_N.PDF](Doc_Fabrication__SS_EA_et_N.PDF)
Document de fabrication, incluant les étapes d'assemblage et les choix techniques.

### [Procedure_d'installation_et_de_mise_en_service_SS_EA_et_N.pdf](Procedure_d'installation_et_de_mise_en_service_SS_EA_et_N.pdf)
Procédure d'installation et de mise en service du sous-système.

### [Procedure_de_maintenance_preventive_SS_EA_et_N.pdf](Procedure_de_maintenance_preventive_SS_EA_et_N.pdf)
Procédure de maintenance préventive pour assurer le bon fonctionnement dans le temps.

### [Rapport_et_procedure_de_test__SS_EA_et_N.pdf](Rapport_et_procedure_de_test__SS_EA_et_N.pdf)
Rapport de tests et procédures de vérification du sous-système.

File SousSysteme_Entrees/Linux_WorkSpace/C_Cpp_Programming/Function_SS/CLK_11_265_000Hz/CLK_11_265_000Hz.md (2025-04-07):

Le fonction pricipales de fichier CLK_11_265_000Hz.sh est d'e prendre une valeur de frequence en argument est utiliser Pigpio pour envoyer la cette frequence sur la surtie GPIO4 = GPCLK0.
On ne peux pas utiliser Pigpio et WiringPi en meme temps donc in faut assurer que les deux ne sont pas activées en meme temps. Cette fichier verifie si le Pigpio etait deja en cours d'execution sinon le script lance le Pigpio, en suite la frequence est reglé a la frequence donnée dans l'argument de fichier de script bash. et une fois que c'est fait le script "desactive"(kill the task) pigpio.

voici les lignes de script importantes :

```
sudo pigpiod
pigs hc $GPIO_PIN $FREQ # pigs hc 4 11265000, il faut remplacer les variables par des valeurs
sudo killall pigpiod
```

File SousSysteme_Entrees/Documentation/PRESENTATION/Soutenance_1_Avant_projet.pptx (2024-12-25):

## Presentation SAE S5

Conception d'une Table de Mixage

MUHAMMAD Asad
BUT 3 GEII ESE FI

## I - Analyse fonctionnelle

- Objectif principal :
  - Concevoir une table de mixage fonctionnelle pour : traiter et synchroniser des signaux audio analogiques(ou Numeriques) venant de différentes sources.
- Livrable principal : Prototype d'une table de mixage.
- Pourquoi ? : Besoin d’un outil pour synchroniser et mélanger les signaux de différents instruments créés dans le cadre de la SAÉ.


## II - Cahier des charges - Contexte du projet

- Situation : Développer un système permettant de gérer simultanément au moins deux sources musicales.
- Enjeux : Synchronisation, compatibilité avec d'autres instruments, restitution sonore de qualité.
- Le produit réalisé doit fonctionner avec les instruments de musique déjà conçus, qui fourniront des signaux audios
- Normes existantes

## III - Fonctionnalités clés

- Entrées audio : Minimum 2 entrées analogiques ou Numériques.
- Traitement audio : Mixage des signaux audio, synchronisation, gestion du gain, égalisation, Effets.
- Sorties : Restitution en format numérique ou analogique.
- IHM
- Option Hybrid

## IV - Schéma Bloc / Fonctionnel


## IV - Schéma Bloc / Fonctionnel


## V - Communication

- Signal Analogique ou Sonore :
  - Niveau ligne (Line Level) : Pro +4 dBu (~1.23 V RMS).
  - Niveau Instrument (Instrument Level)
  - Signal modulé (AM ou FM)
- Signal Numérique :
  - Protocole MIDI : Transmission des données via protocole MIDI (filière ou USB-MIDI).

## V - Communication


## VI - Synchronisation des données

- Signal de Démarrage/Enable (Common Clock Synchronization)
- Signal Analogique ou Sonore :
  - PLL (avec modulation)
  - SMPTE (avec modulation)
  - TimeStamp(version custom)
  - Impulsion de Reference (Reference Pulse) ou (Sync Pulse)
- Signal Numérique :
  - TimeStamp
  - TimeCode

## VII - Stockage et traitement des données

- Stockage :
  - Carte SD pour les microcontrôleurs
  - RAM (ou Carte SD) pour SBC (Raspberry Pi).
- Traitement :
  - Mélange Numérique (DAW,..) ou Analogique
  - Application d'effets audio Numérique ou Analogique.

## VIII - Prochaines étapes et conclusion

GANTT


- Conclusion : Ce projet offre une opportunité d'appliquer concrètement des compétences en électronique, informatique et traitement du signal.

## Questions et Réponses

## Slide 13


## Contraintes et budget

- Contraintes : Utiliser uniquement le matériel disponible à l’IUT.
- Budget : 200 € pour l’ensemble du projet.

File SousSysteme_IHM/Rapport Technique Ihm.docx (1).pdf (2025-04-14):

BUT 3 – SAE S5/6

1

CY IUT – GEII Neuville

# Rapport Technique-Sous systèmes (IHM)

## Projet Chef d’Orchestre Électronique

### Document rédigé par : « Yigit-El karani » Version : 1.0 – 10/04/2025

BUT 3 – SAE S5 | Rapport Technique
Yigit-El karani

## Avant-propos

1

Dans le cadre de notre projet d’orchestrion électronique réalisé en troisième année de BUT GEII, notre équipe a eu pour mission de développer une interface permettant de créer, modifier et visualiser des sons en temps réel.

Pour cela, nous avons choisi d’utiliser Python, un langage simple à utiliser mais très puissant, notamment grâce à des bibliothèques comme numpy, scipy, matplotlib et sounddevice. Ce choix nous a permis de nous concentrer sur la logique du traitement du signal et sur l’interface, sans perdre de temps sur des problèmes techniques complexes.

Le système fonctionne sur un Raspberry Pi 4, un petit ordinateur très pratique pour embarquer notre application dans un boîtier musical. Grâce à ça, on peut envisager une utilisation autonome du dispositif, sans avoir besoin d’un PC externe.

Ce rapport présente les différentes étapes de conception de notre IHM, les choix que nous avons faits, et la manière dont notre module interagit avec les autres parties de l’orchestrion.

## Table des matières

Avant-propos | 2
Table des matières | 2-3
1. Introduction | 4
2. Conception du système IHM | 5
2.1 Objectifs de conception | 5
2.2 Choix techniques | 5
2.3 Architecture logicielle | 6
3. Fabrication | 6
3.1 Ecriture du code | 6
3.2 Interface utilisateur | 6
3.3 Visualisation graphique | 6
3.4 Tests initiaux | 7
3.5 Difficultés rencontrés | 7
3.6 Etat final | 7
3.7 Installation et mise en oeuvre sur Raspberry PI | 7
4. Vérification et Tests | 9
4.1 Procédures de tests | 9
4.2 Procédure de test du système global | 9
4.3 Liste des actions correctives | 9
4.4 CHECKLIST du bon fonctionnement | 10
5. Maintenance corrective et préventive | 11
5.1 Plan de maintenance préventive globale | 11

1

14/01/2025 Version : 1.0

5.2 Procédures de maintenance correctives | 11
5.3 Fiche type de maintenance corrective | 12
6. Implantation du système | 13
6.1 Procédure de mise en oeuvre du système | 13
6.2 Checklist de mise en oeuvre | 13
6.3 Ouverture et améliorations possibles | 14
7. Conclusion | 14
Annexes | 14

## 1. Introduction

Ce rapport technique présente le développement de notre partie du projet d’orchestrion électronique, réalisé dans le cadre de la 3e année du BUT GEII. L’orchestrion, en tant que système automatisé composé de plusieurs instruments pilotés numériquement, nécessite une coordination efficace entre plusieurs sous-systèmes. Notre groupe s’est chargé de la réalisation de l’interface homme-machine (IHM), un élément central permettant à l’utilisateur de générer, visualiser et modifier des signaux audio en temps réel.

L’IHM développée s’intègre dans l’architecture globale de l’orchestrion. Elle permet :

- La génération de signaux MIDI bruités et numériques simulés (ondes sinusoïdales, carrées, etc.),
- L’application de traitements numériques : filtres passe-bas, passe-haut, passe-bande, inversion, décalage,
- La visualisation des signaux sur une interface graphique temps réel,
- La sortie sonore du signal traité, envoyée vers un système de diffusion ou d’enregistrement.

Le système repose sur une Raspberry Pi 4, qui exécute un programme Python utilisant des bibliothèques scientifiques (numpy, scipy, sounddevice, matplotlib) pour assurer l’ensemble des fonctions. L'IHM permet également une interaction clavier pour appliquer dynamiquement différents filtres au signal audio.

## 2. Conception du système IHM

### 2.1 Objectifs de conception

L’objectif principal de cette phase de conception était de réaliser une IHM capable de :

- Générer plusieurs signaux audio,
- Appliquer différents types de filtres numériques (passe-bas, passe-haut, passe-bande, coupe-bande, inversion, décalage),
- Visualiser en temps réel les signaux (individuels et combinés),
- Permettre une interaction simple avec l’utilisateur (commande par clavier).

Le tout devait fonctionner sur un système embarqué (Raspberry Pi 4) avec des performances suffisantes pour l’audio temps réel.

### 2.2 Choix techniques

- Langage de programmation : Python 3, pour sa simplicité, ses bibliothèques scientifiques, et sa compatibilité avec Raspberry Pi.
- Environnement de développement : Visual Studio Code (VS Code), utilisé pour l’écriture, le test et le débogage du code. Il offre une interface claire, des extensions utiles et une bonne compatibilité avec Raspberry Pi via SSH ou transfert de fichiers.
- Bibliothèques principales :

numpy : génération de signaux et traitement numérique,

scipy.signal : conception et application des filtres (Butterworth),

sounddevice : sortie audio en temps réel (interface avec la carte son),

matplotlib : visualisation graphique dynamique avec FuncAnimation.

- Fréquence d’échantillonnage : 44 100 Hz (standard audio, bonne qualité sans surcharge CPU).
- Raspberry Pi 4 : carte embarquée légère, compacte, avec sorties audio et GPIO.

### 2.3 Architecture logicielle

Le système se divise en plusieurs modules :

- Génération de signaux : fonctions spécifiques pour chaque type d’onde (MIDI bruité, carré, pseudo-carré).
- Filtrage : ensemble de fonctions qui appliquent un filtre choisi par l’utilisateur (commande via le clavier).
- Visualisation : mise à jour en temps réel de 5 courbes synchronisées (4 signaux + leur moyenne).
- Sortie audio : envoi du signal audio traité vers la sortie son de la Raspberry Pi.

## 3. Fabrication

### 3.1 Écriture du code

Le code Python a été structuré autour d’une animation matplotlib qui appelle la fonction mettre_a_jour() à chaque trame :

- À chaque appel, les 4 signaux sont générés (fréquences prédéfinies : 440 Hz, 523.25 Hz, 220 Hz, 110 Hz).
- Un filtre est sélectionné selon la touche clavier pressée (de 1 à 7).
- Le signal combiné est calculé comme la moyenne des 4 signaux filtrés.
- Le signal MIDI 1 est normalisé puis joué en sortie audio via sounddevice.write().
- Les graphiques sont mis à jour dynamiquement avec les nouvelles données.

Le développement s’est fait dans Visual Studio Code (VS Code), configuré avec l’extension Python, l’autocomplétion, la coloration syntaxique, le débogueur intégré.

### 3.2 Interface utilisateur

- Interaction simple : l’utilisateur change le filtre appliqué aux signaux avec une touche (1 à 7).
- Pas de boutons : tout se fait au clavier pour plus de légèreté et de rapidité.
- Le titre des graphes indique dynamiquement le filtre en cours ("Original", "Passe-bas", etc.).

### 3.3 Visualisation graphique

5 sous-graphes sont affichés simultanément :

MIDI bruité 1 (440 Hz); MIDI bruité 2 (523.25 Hz; Numérique 1 (carré parasité 220 Hz), Numérique 2 (pseudo-carré 110 Hz); Signal combiné (moyenne des 4)

Les courbes sont mises à jour en temps réel avec matplotlib.animation.FuncAnimation, et nous fixons la limite d’amplitude à [-320, 320], échantillons affichés = TAILLE_TRAME.

### 3.4 Tests initiaux

- Vérification que chaque signal était bien généré indépendamment.
- Application correcte des filtres : testés un par un avec les touches.
- Affichage cohérent des signaux dans les graphes.
- Lecture audio fluide, sans latence ni saturation.

### 3.5 Difficultés rencontrées

Besoin de synchroniser les signaux et le graphique en temps réel (nécessité de calibrer la taille des trames).

### 3.6 État final

À l’issue de la phase de fabrication, le système est fonctionnel, stable et prêt pour une démonstration.

### 3.8 Installation et mise en œuvre sur Raspberry Pi

3.8.1 Installation de la Raspberry Pi

- Utilisation d'une Raspberry Pi 4
- Connexion à un écran HDMI, clavier et souris
- Connexion au réseau local (Ethernet ou Wi-Fi)

3.8.2 Branchement

- Alimentation via port USB-C 5V / 3A
- Sortie audio utilisée : jack 3.5 mm
- Optionnel : ventilation passive ou active en cas de température élevée

3.8.3 Déploiement du programme

- Transfert du code Python depuis VS Code

3.8.4 Bon fonctionnement attendu

- Démarrage fluide de l’interface graphique sur écran
- Affichage des signaux à l’écran dans les 2 secondes
- Changement dynamique de filtre avec les touches 1 à 7 sans bug
- Stabilité confirmée après plusieurs minutes de fonctionnement

3.8.5 Mise à jour de Visual Studio Code

Mise à jour de VS Code recommandée régulièrement pour :

- Profiter des dernières corrections de bugs
- Bénéficier d’un meilleur support Python
- Assurer la compatibilité avec Raspberry Pi OS

## 4. Vérification et Tests

### 4.1 Procédures de tests

Pour valider le bon fonctionnement de l’IHM, plusieurs séries de tests ont été réalisées :

- Tests unitaires : vérification individuelle des fonctions de génération et de filtrage des signaux.
- Tests d’affichage : cohérence entre les signaux affichés et les signaux générés.
- Tests d’interaction : changement dynamique de filtre à l’aide des touches clavier.
- Tests de performance : évaluation de la consommation CPU et de la stabilité du flux audio.

Tous les tests ont été effectués via VS Code, permettant l’exécution directe du script Python, l’observation du terminal et la mise en évidence d’éventuelles erreurs en temps réel.

### 4.2 Procédure de test du système global

1. Lancement du script Python sur Raspberry Pi.
2. Vérification de l’ouverture correcte de la fenêtre matplotlib.
3. Attente du premier affichage des 5 signaux.
4. Pression successive sur les touches 1 à 7 pour tester tous les filtres.
5. Observation de la modification dynamique des signaux.
6. Fermeture propre du programme.

### 4.3 Liste des actions correctives

Problème rencontré | Solution apportée
Affichage ralenti avec les 5 graphiques | Réduction de la taille des trames, animation plus légère
Programme bloqué si une mauvaise touche est appuyée | Filtrage des touches acceptées dans la fonction clavier
Aucun affichage | Programme mal compilé

### 4.4 CHECKLIST du bon fonctionnement

Élément à vérifier | Statut | Détail
Raspberry bien alimenté | OK
Ouverture correcte de l’interface graphique | OK | La fenêtre matplotlib s’ouvre sans erreur
Affichage des 5 courbes | OK | Tous les signaux s’affichent dès le lancement
Changement de filtre avec les touches clavier | OK | Touche 1 à 7 réagit correctement
Titre des graphes mis à jour | OK | Le nom du filtre appliqué est affiché
Stabilité générale de l’interface | OK | Pas de blocage après plusieurs minutes
Fermeture propre du programme | OK | La fenêtre se ferme sans erreur, le script se termine bien

## 5. Maintenance corrective et préventive

### 5.1 Plan de maintenance préventive globale

Afin d'assurer le bon fonctionnement sur le long terme, voici les actions de maintenance préventive à appliquer régulièrement :

Action | Fréquence recommandée | Objectif
Vérifier les mises à jour de Python | Toutes les semaines | Éviter les incompatibilités
Mettre à jour les bibliothèques Python | Tous les mois | Corriger bugs et failles
Mettre à jour VS Code | À chaque version stable | Assurer un environnement fiable
Nettoyer les fichiers inutiles | Tous les 2 mois | Alléger la charge système
Vérifier le bon fonctionnement des filtres | À chaque nouvelle session | Garantir la validité des résultats
Redémarrer le système proprement | 1 fois par semaine | Prévenir les fuites mémoire

### 5.2 Procédures de maintenance correctives

En cas de dysfonctionnement ou bug constaté, voici les étapes recommandées :

1. Identifier clairement le symptôme (ex. : l'IHM ne s’ouvre pas, le clavier ne répond plus, une courbe ne s’affiche plus...)
2. Reproduire le problème pour confirmer qu’il est récurrent
3. Vérifier les erreurs affichées dans le terminal
4. Analyser le code à l’endroit concerné (souvent une mauvaise variable, une touche non prise en compte, etc.)
5. Corriger le bug, tester localement dans VS Code
6. Re-tester tout le fonctionnement global avant de considérer le bug résolu

### 5.3 Fiche type de maintenance corrective

Voici un modèle de fiche à remplir pour chaque intervention corrective :

Fiche de maintenance corrective

Date

Intervenant

Problème

Analyse effectuée

Actions correctives appliqués

Test

Fonctionnement après les tests

## 6. Implantation du système

### 6.1 Procédure de mise en œuvre du système

Pour mettre en œuvre le système IHM de traitement audio temps réel sur Raspberry Pi, voici les étapes à suivre :

1. Préparer la Raspberry Pi :
- Installer Raspberry Pi OS

## - Mettre à jour le système avec sudo apt update && sudo apt upgrade

2. Installer les dépendances Python :
numpy scipy matplotlib sounddevice
3. Compiler le code Python sur la Raspberry Pi via VS
4. Connecter la sortie audio jack à un oscilloscope
5. Interagir avec l’IHM via le clavier (touches 1 à 7 pour les filtres)
6. Observer l'affichage graphique en temps réel des courbes sur l'écran relié à la Raspberry Pi et sur l’oscilloscope
7. Arrêter proprement le système en fermant la fenêtre ou en coupant le script

### 6.2 Checklist de mise en œuvre

Étape | Statut

Raspberry Pi alimentée et connectée

Système d’exploitation fonctionnel

Bibliothèques Python installées

Programme lancé sans erreur

Interface graphique visible

Commandes clavier fonctionnelles

Signaux affichés correctement

Fermeture propre du programme
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

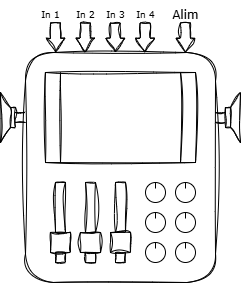
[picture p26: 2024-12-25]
SousSysteme_Entrees/Documentation/SCHEMAS/Croquis_Mixeur.drawio.png

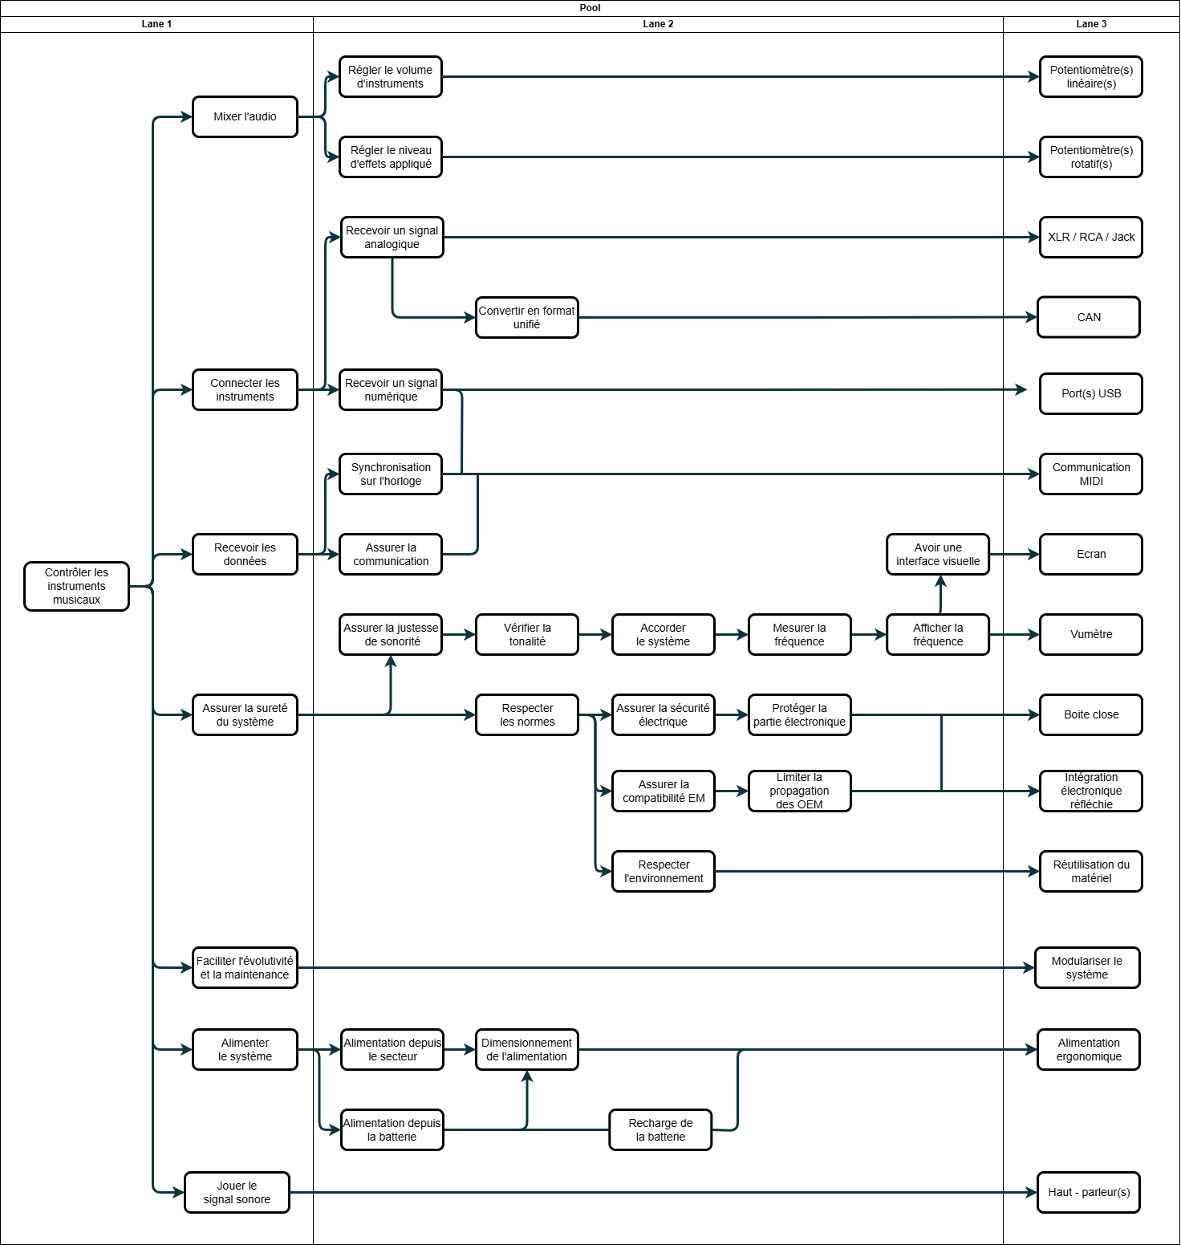
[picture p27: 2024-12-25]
SousSysteme_Entrees/Documentation/SCHEMAS/FAST_V1.drawio.png

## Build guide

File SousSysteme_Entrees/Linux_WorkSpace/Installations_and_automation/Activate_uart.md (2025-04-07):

# Activer Uart
Le raspberry pi 4B a 6 uarts en total.On peux les voirs en utilisant la command `dtoverlay -a | grep uart` dans le terminal.
Par defaut les uarts ne sont pas activés. on peux voir les uarts qui sont activées avec la commande `ls /dev/ttyA* && ls /dev/ttyS*`. 
Il ya 2 type d'uart sur raspberry pi. PL011 et miniUART. le PL011 est compatible avec 16550 Uart et les fonctionnalités de mini uart sont reduites. 
Sur le pi 4:

| Nom | Type |
| ----- | --- |
| UART0 | PL011 |
| UART1 | mini UART |
| UART2 | PL011 |
| UART3 | PL011 |
| UART4 | PL011 |
| UART5 | PL011 |

Tous les UARTS sont 3.3V, Utiliser avec 5V peux endommager les pins.

Pour pouvoir utiliser tous les uarts il faut desactiver le uart1 comme uart de console et l'utiliser comme uart normal pour cella :
- On utilise la commande `sudo raspi-config`
- Option Interface
- Port serie ou Serial Port
- Dire non au acess de shell sur port serie
- Dire non pour activer le port serie. On va l'activer manuellement apres.
- Valider

Pour activer les uarts il faut modifier le configuration de boot.txt. Pour cela on utilise un editeur de text, ici on utilise nano. avec la commande `sudo nano /boot/firmware/config.txt` on va acceder le fichier.

Toute en bas de fichier nous avons une section `[all]`.
Dans cette section on peux voir si il ya des uarts qui sont acivées. 
pour activer l'uart 1 il faut mettre `enable_uart=1` dans cette section. Pour les autres uarts on utilise 

```
dtoverlay=uart0
dtoverlay=uart2
dtoverlay=uart3
dtoverlay=uart4
dtoverlay=uart5
```

D'apres : https://www.raspberrypi.com/documentation/computers/configuration.html#networking

Pour utiliser le mini UART, vous devez configurer le Raspberry Pi pour utiliser une fréquence d'horloge fixe du cœur du VPU. En effet, l'horloge du mini UART est liée à l'horloge du cœur du VPU, de sorte que lorsque la fréquence de l'horloge du cœur change, le débit en bauds de l'UART change également. Les paramètres enable_uartet core_freqpeuvent être ajoutés pour config.txt modifier le comportement du mini UART.

`disable-bt` désactive le périphérique Bluetooth et fait du premier PL011 (UART0) l'UART principal. Vous devez également désactiver le service système qui initialise le modem, afin qu'il ne se connecte pas à l'UART, en utilisant `sudo systemctl disable hciuart`.

Il faut aussi donner les bonnes permissions aux ports series. Pour cela en terminal nous pouvons utiliser la commande : `ls -l /dev/ttyA* && ls /dev/ttyS*` pour connaitre les permission actuelle.
Pour changer les permissions nous pouvons utiliser la commande `chmod a+rw /dev/ttyAMA0` ou `ttyAMA0` doit etre remplacé par le port pour lequelle on veut changer les permissions.

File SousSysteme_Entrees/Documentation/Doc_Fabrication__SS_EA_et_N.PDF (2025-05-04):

BUT 3 – SAE S5

CY IUT – GEII Neuville

# Document de Fabrication

## Projet tutoré Mixeur Sous-système Entrées

## Document rédigé par : MUHAMMAD Asad Version : 1.1 [4 mai 2025]

BUT 3 – SAE S5 | Dossier de fabrication
4 mai 2025 | Version : 1.1 | 1

## Historique des modifications et révisions de ce document :

N° de version | Date | Auteur | Description et circonstances de la modification
V 0 | | MUHAMMAD Asad | Brouillon : première version, modèle fourni.
V 1.0 | 16/02/2025 | MUHAMMAD Asad | Première rédaction du document.
V 1.1 | 04/05/2025 | MUHAMMAD Asad | Mise a jour Fin de Projet

## Grilles d'évaluations

## Avant-propos¹

Ce document de fabrication décrit en détail la réalisation matérielle du sous-système d’entrées de la table de mixage audio développée dans le cadre du projet tutoré Mixeur Sous-système Entrées. Il constitue un guide technique permettant d’assurer une fabrication rigoureuse et conforme aux spécifications définies dans le document de conception.

L’objectif de ce document est d’apporter une vision claire des différentes étapes de fabrication, des choix techniques et des contrôles de qualité nécessaires à l’assemblage du circuit. Il regroupe l’ensemble des documents essentiels à la production.

1 Référence : Gestion de projet, 50 outils pour agir ; F. Bouchaouir, Y. Dentinger, O. Englender ; Vuibert ;
2014. | Expression du besoin et cahier des charges fonctionnel ; J. Bernard-Bousières ; AFNOR ; 2012.

## Table des matières

## Table des Figures

Figure 1 Carte Mère : Système modulaire (FT9-0 & FT9-1) Schéma | 8
Figure 2 Bornier à vis 5mm | 9
Figure 3 Headers femelle 2.54mm | 9
Figure 4 Connecteur jack 3.5mm PCB | 9
Figure 5 Carte Mère Gerber (en cours de developpement) | 10
Figure 6 Carte mère 3D plan de face | 11
Figure 7 Carte mère 3D plan de dos | 11
Figure 8 Carte mère 3D isométrique | 11
Figure 9 Module Entrée haute impédance + filtre schéma | 12
Figure 10 Montage filtre proposé avec les valeurs | 13
Figure 11 Diagramme de bode du filtre | 13
Figure 12 Module Entrée haute impédance + filtre schéma Gerber | 14
Figure 13 Module Entrée haute impédance + filtre schéma 3D vue de face | 15
Figure 14 Module Entrée haute impédance + filtre schéma vue de dos | 15
Figure 15 Module Entrée haute impédance + filtre schéma vue isométrique | 15
Figure 16 Module Gain schéma | 17
Figure 17 Module Gain Gerber | 19
Figure 18 Module Gain 3D vue de face | 20
Figure 19 Module Gain 3D vue de dos | 20
Figure 20 Module Gain 3D vue isométrique | 20
Figure 21 Module Offset schéma | 21
Figure 22 Montage simplifié régulateur de tension | 21
Figure 23 Montage complète régulateur de tension réglable | 22
Figure 24 Montage régulateur de tension schéma | 23
Figure 25 Montage résistances pour régulateur de reglable, Prescision potentiometre multitour...... 23
Figure 26 Montage résistances pour régulateur de tension réglable, potentiomètre 1 tour | 23
Figure 27 Montage Différentielle pour principe pour offset | 24
Figure 28 Diviseur de tension pour référence de Montage Offset | 25
Figure 29 Montage Différentielle offset 2 voies | 25
Figure 30 Module offset gerber | 26
Figure 31 Module Offset 3D vue de face | 27
Figure 32 Module Offset 3D vue de dos | 27
Figure 33 Module Offset 3D vue isométrique | 27

## Liste des Tableaux:

Tableau 1 Nomenclature Carte Mère | 11
Tableau 2 Nomenclature Module Entrée haute impédance + filtre schéma | 16
Tableau 3 Nomenclature Module Gain | 20
Tableau 4 Nomenclature Module Offset | 28

## I. Contexte du projet

### A. Situation et description

Le projet consiste à concevoir et réaliser une table de mixage audio automatique capable de traiter et de synchroniser plusieurs flux audios provenant d’instruments de musique. Ce dispositif sera intégré à l’Orchestrion, un système automatisé conçu pour reproduire les performances d’un orchestre en combinant différents instruments.

Développé dans le cadre de la SAE (Situation d’Apprentissage et d’Évaluation), ce projet sera présenté lors des Journées Portes Ouvertes de l’IUT de Cergy-Pontoise. Il met en avant la conception d’un dispositif électronique physique tout en respectant des contraintes écologiques et économiques.

### B. Besoins et objectifs

L’objectif principal de ce projet est de valoriser les enseignements du BUT GEII (Bachelor Universitaire de Technologie en Génie Électrique et Informatique Industrielle) à travers la création d’une unité de contrôle audio automatisée.

Ce mixeur audio doit permettre :

- Le traitement et la synchronisation de plusieurs sources sonores en temps réel.
- Une intégration optimisée au sein de l’Orchestrion, garantissant une interaction fluide avec les instruments automatisés.
- Une gestion efficace du signal audio tout en maintenant une faible consommation énergétique.

En plus des contraintes techniques, le projet répond également à des enjeux écologiques et économiques, en favorisant l’utilisation de composants optimisés et durables.

## II. Rappel des fonctions

- FT9 : Assurer la fiabilité et la maintenance
- FT9-0 : Concevoir un système modulaire avec des sous-systèmes indépendants (entrée audio, traitement, interface utilisateur, alimentation).
- FT9-1 : Garantir la sécurité électrique grâce à une protection contre les surtensions et courts-circuits sur les entrées Analogiques et Numériques.
- FT9-2 : Garantir la sécurité électrique grâce à une protection contre les surtensions et courts-circuits sur les Alimentations.
- FT2, FT3 : Gérer l’entrée audio analogique
- FT2-0 : Conditionner le signal analogique via pré amplification et filtrage.
- FT2-1 : Réguler le gain du signal d’entrée.
- FT2-2 : Appliquer un décalage (offset) sur le signal analogique AC.
- FT3 : Convertir le signal analogique en numérique (ADC) avec une résolution minimale de 12 à 16 bits et une fréquence d’échantillonnage de 44,1 kHz.
- FT1, FT6 : Gérer l’entrée audio numérique
- FT1-0 : Réceptionner les signaux MIDI.
- FT6 : Synchroniser les horloges MIDI avec le traitement audio interne.
- FT1-1 : Convertir les données MIDI en audio grâce à une synthèse numérique.
- FT5, FT6, FT7, FS1, FS2 : Assurer le traitement numérique du signal et produire un signal sonore
- FT5-0 : Appliquer des algorithmes de filtrage numérique (IIR/FIR) et de mixage pour ajuster les niveaux sonores et ajouter des effets.
- FT5-1 : Gérer le mixage audio en temps réel avec une allocation dynamique des canaux.
- FT7, FS1, FS2 : Fournir une IHM pour la gestion des paramètres de mixage et effets.
- FT6-0 : Restituer le signal audio
- FT6-1 : Fournir une sortie stéréo pour deux haut-parleurs intégrés ou une sortie ligne (non amplifiée).
- FT6-2 : Amplifier le signal audio
- Assurer l’amplification en tension et en courant du signal audio pour une restitution optimale.
- FT8 : Gérer l’alimentation électrique
- Assurer une alimentation via une batterie rechargeable.
- Permettre la recharge via un adaptateur secteur, une alimentation DC.
- FC6, FT9 : Garantir un format compact et une bonne ergonomie
- Concevoir un boîtier robuste et léger, en matériaux résistants aux chocs et adaptés aux manipulations fréquentes.
Optimiser les dimensions pour faciliter le transport et l’intégration dans un setup mobile.¹

1
Les Fonction barrées seront rédigées dans le document de fabrication de sous système

## III.Contraintes de fabrication

La fabrication du sous-système d’entrées de la table de mixage doit respecter plusieurs contraintes afin d’assurer une réalisation efficace et économiquement viable. Ces contraintes concernent principalement l’optimisation des ressources disponibles, la maîtrise des coûts et les choix technologiques liés à la production des circuits imprimés.

Optimisation des ressources disponibles
L’un des objectifs principaux est de maximiser l’utilisation du matériel disponible à l’université. Cela inclut les composants électroniques, les outils de fabrication, ainsi que les équipements de soudure et d’assemblage. Cette approche permet de réduire les coûts tout en garantissant une fabrication plus rapide et accessible.

Respect du budget
Le budget alloué pour la fabrication de ce sous-système est limité à 200 €. Ce budget inclut l’achat de composants électroniques, les éventuelles impressions de PCB et les éléments mécaniques nécessaires à l’assemblage. Pour respecter cette contrainte, des alternatives de composants sont prévues afin d’optimiser les coûts sans compromettre la performance du système.

Fabrication des PCB
- Préférence pour une production en interne : Lorsque cela est possible, les circuits imprimés (PCB) seront réalisés à l’université afin de réduire les délais et maîtriser les coûts.
- Type de PCB recommandé :
- Simple face privilégié pour une fabrication plus rapide et un routage simplifié.
- Double face accepté si nécessaire pour l’optimisation du circuit.
- Limitation à 2 couches de cuivre : Au-delà de deux couches, la fabrication en interne devient impossible et nécessite un recours à un fabricant externe, ce qui entraîne des coûts supplémentaires et n’est pas recommandé dans le cadre de ce projet.
Ces contraintes doivent être prises en compte tout au long du processus de conception et de fabrication afin d’assurer un développement efficace, économique et conforme aux objectifs du projet.

## IV. Carte Mère : Système modulaire (FT9-0 & FT9-1)

### A. Schéma électronique et fonctions techniques

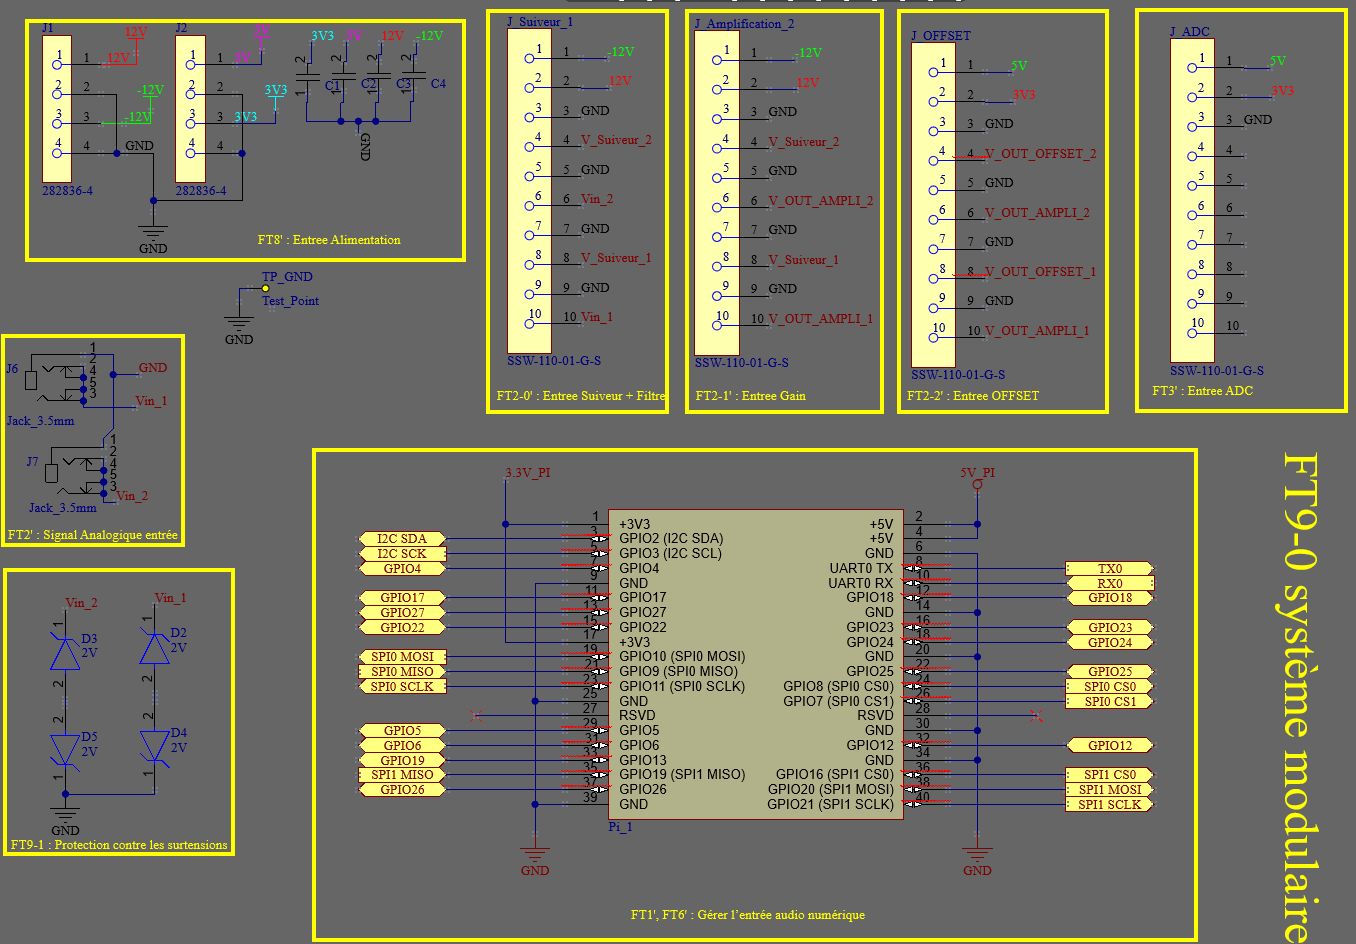
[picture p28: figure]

Figure 1 Carte Mère : Système modulaire (FT9-0 & FT9-1) Schéma

La carte mère est conçue comme un système modulaire permettant l’interconnexion des différents sous-systèmes du mixeur. Son rôle principal est de centraliser les connexions entre les différents modules tout en intégrant les éléments de protection nécessaires.
La carte mère ne contient pas de circuits actifs dédiés au traitement du signal, mais elle assure la distribution des alimentations et l’interface entre les modules grâce aux différentes connecteurs. La carte mère comporte les connecteurs pour les fonctions suivantes (FXX’

1
):
- FT8’ : Bornier 5mm pour l’alimentation pour la carte mère.
- FT2’ : Connecteurs Jack 3.5mm pour la gestion des entrées analogique.
- FT2-0’ : Header femelle 2.54mm 10pins pour le module suiveur et filtrage.
- FT2-1’ : Header femelle 2.54mm 10pins pour le module gain.
- FT2-2’ : Header femelle 2.54mm 10pins pour le module Offset.
- FT3’ Header femelle 2.54mm 10pins pour le module conversion analogique numérique.
- FT1’ et FT6’ : Header male 2.54mm 2*20 pins pour connecteur la Raspberry avec une nappe IDC 2 *20pins pour la gestion des entrées Numériques.
Pour la protection des nous circuits d’autres composants sont aussi présents :
- FT9-1 : Diodes de limitation de tension pour limiter la tension a une seuil, aussi appelés diodes de clampage ou TVS.
- FT8’ : Condensateurs de découplage sur l’alimentation.

1 Utilisation de “ ‘ “ pour désigner le connecteur pour le module ou sous-système

### B. Notice de dimensionnement et choix des composants

Les diodes de clampage ont été choisies pour limiter la tension à 2V, légèrement au-dessus du signal analogique maximal, afin de protéger contre les pics de tension élevés sans altérer le signal. La valeur minimale disponible en stock est de 2V, mais une diode de 1.7V peut également être utilisée si nécessaire.

Pour l’alimentation, des borniers à vis 5.0 mm ont été retenus pour assurer une connexion robuste et sécurisée des fils.

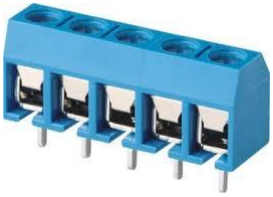
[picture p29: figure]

Figure 2 Bornier à vis 5mm

Les connecteurs des modules sont des headers femelle 2.54 mm, choisis pour leur facilité d’assemblage et leur compatibilité avec un montage vertical des cartes filles.

Figure 3 Headers femelle 2.54mm

Les entrées analogiques utilisent des connecteurs jack 3.5 mm, un standard couramment utilisé en audio, garantissant une compatibilité avec un large éventail d’appareils sonores.

Figure 4 Connecteur jack 3.5mm PCB

### C. Documents de contrôle de fabrication

1. Typon – Visuel Gerber
Dimensions : 10cm * 10cm

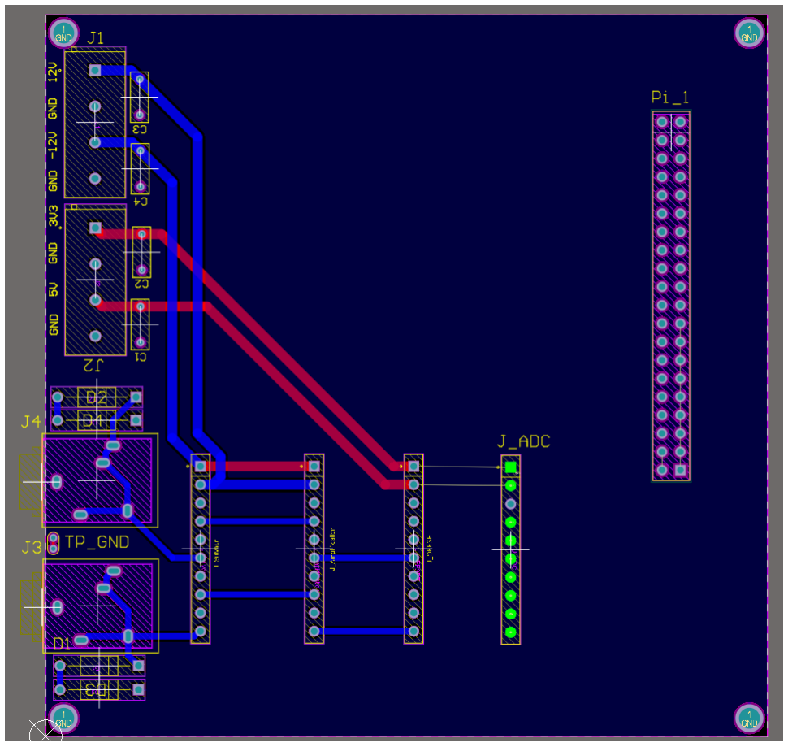
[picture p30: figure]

Figure 5 Carte Mère Gerber (en cours de developpement)

2. Plan de montage (visuel 3D)

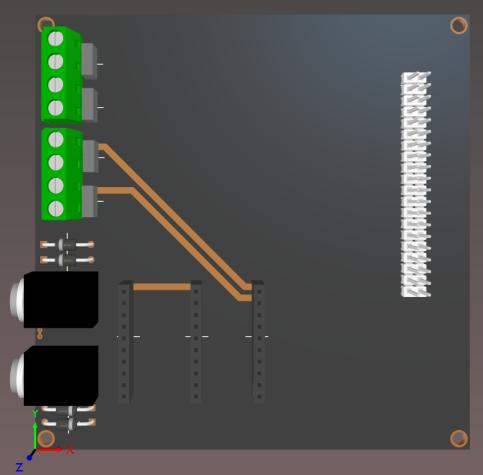
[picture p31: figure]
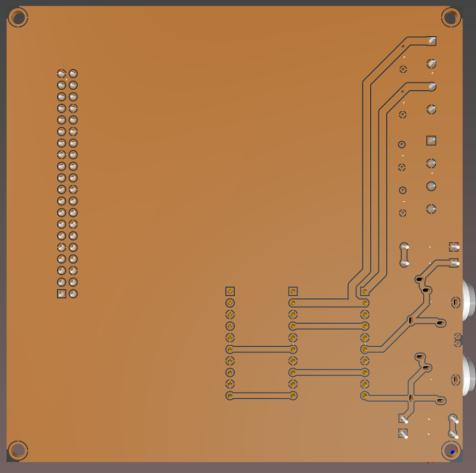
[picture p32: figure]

Figure 6 Carte mère 3D plan de face | Figure 7 Carte mère 3D plan de dos

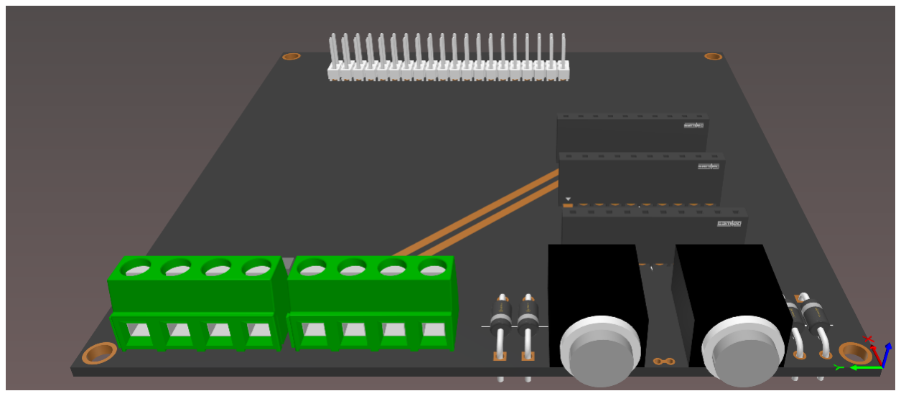
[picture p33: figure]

Figure 8 Carte mère 3D isométrique

3. Nomenclature
Référence schéma | Propriété | Fourniseur | Référence fournisseur | Coût unitaire | Quantité | Côut total
J1, J2 | 4 contacts, 5mm | RS / CYU | 176-9910 | 0.4650 € | 2 | 0.9300 €
C1, C2, C3, C4 | 100nF | RS / CYU | 241-6523 | 0.1440 € | 4 | 0.5760 €
Pi_1 | 2.54mm 20*2 | RS / CYU | 180-2455 | 2.0190 € | 1 | 2.0190 €
J6, J7 | Jack 3,5 mm PCB | RS / CYU | 913-1030 | 2.5660 € | 2 | 5.1320 €
J_ADC, J_Amplification, J_OFFSET, J_Suiveur | 2.54mm 10*1 | RS / CYU | 205-3161 | 0.6650 € | 4 | 2.6600 €
TP_GND | fil | CYU | NA | 0.0100 € | 1 | 0.0100 €
D1, D2, D3, D4 | 1.7V < Vzener < 3V | RS / CYU | 544-3519 | 0.1460 € | 4 | 0.5840 €
| | | | | Total | 11.9110 €

Tableau 1 Nomenclature Carte Mère

## V. Conditionnement, Entrée haute impédance et filtrage. (FT2-0)

### A. Schéma électronique et fonctions techniques

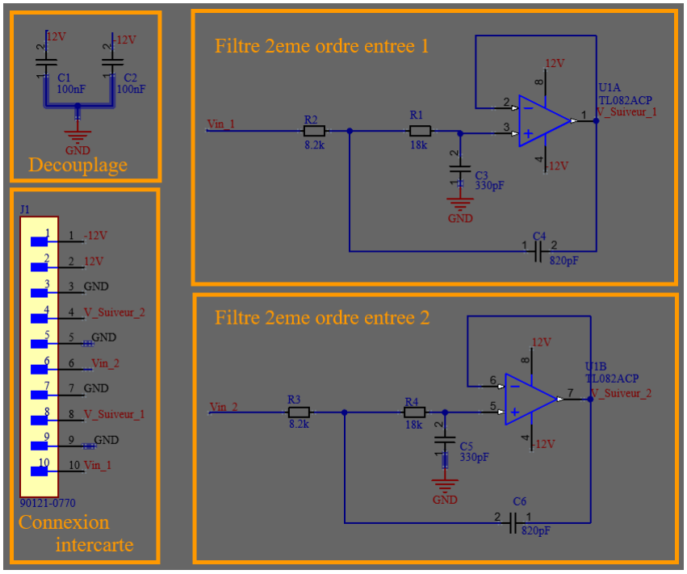
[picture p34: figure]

Figure 9 Module Entrée haute impédance + filtre schéma

### B. Notice de dimensionnement et choix des composants

Ce circuit est le premier élément de la chaîne de conditionnement du signal. Son objectif est de fournir une entrée à haute impédance et de filtrer les fréquences parasites afin d'améliorer la qualité du signal avant traitement.

Le filtre utilisé est un filtre Sallen-Key de second ordre, dimensionné à l’aide de l’outil Analog Filter Wizard d’Analog Devices.

Spécifications principales du filtre :

- Gain : 0 dB
- Atténuation : -1 dB à 20 kHz, -6 dB à 40 kHz (pour supprimer les fréquences parasites avant l’échantillonnage à 44 kHz minimum)
- Type : Tchebychev 0.07 dB
- Nombre d’étages : 1
- Composants :
- Condensateurs série E6 (tolérance 20%)
- Résistances série E12 (tolérance 5%)

Le schéma du filtre obtenu est le suivant, le logiciel nous propose le filtre avec des valeurs normalisées des composantes :

Remarque : Les annotations des composants générées
automatiquement par le logiciel ne doivent pas être prises en compte. Il faut utiliser les valeurs correctes indiquées dans le schéma principal.

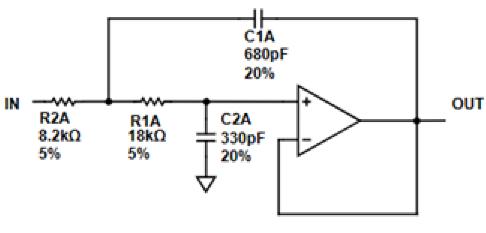
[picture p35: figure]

Figure 10 Montage filtre proposé avec les valeurs | Figure 11 Diagramme de bode du filtre

Nous devons réaliser ce même montage pour les deux entrées analogiques du système.

L’amplificateur opérationnel utilisé est un TL082, qui contient deux AOP dans un même circuit intégré, optimisant ainsi l’encombrement et la consommation d’énergie.

Pour assurer une connexion inter carte en montage vertical, un header mâle 2.54 mm angle droit est utilisé.

Les résistances utilisées auront une puissance de ¼ W, suffisante pour ce type d’application.

Les condensateurs doivent avoir une tension nominale supérieure à 10V pour garantir une marge de sécurité.

### C. Documents de contrôle de fabrication

1. Typon – Visuel Gerber

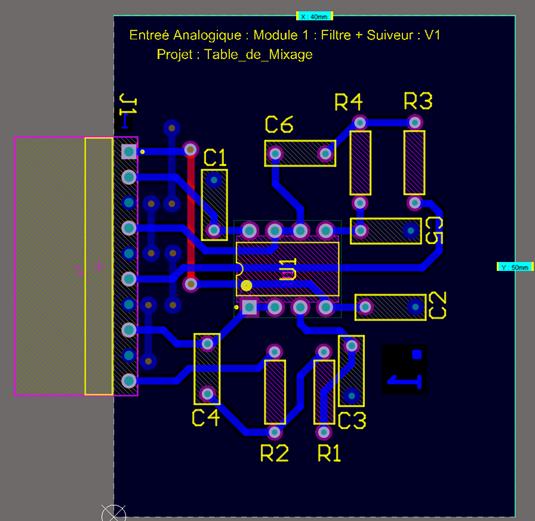
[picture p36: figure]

Figure 12 Module Entrée haute impédance + filtre schéma Gerber

Le circuit réalisé a des dimensions de 40 mm × 50 mm.

2. Plan de montage (visuel 3D)

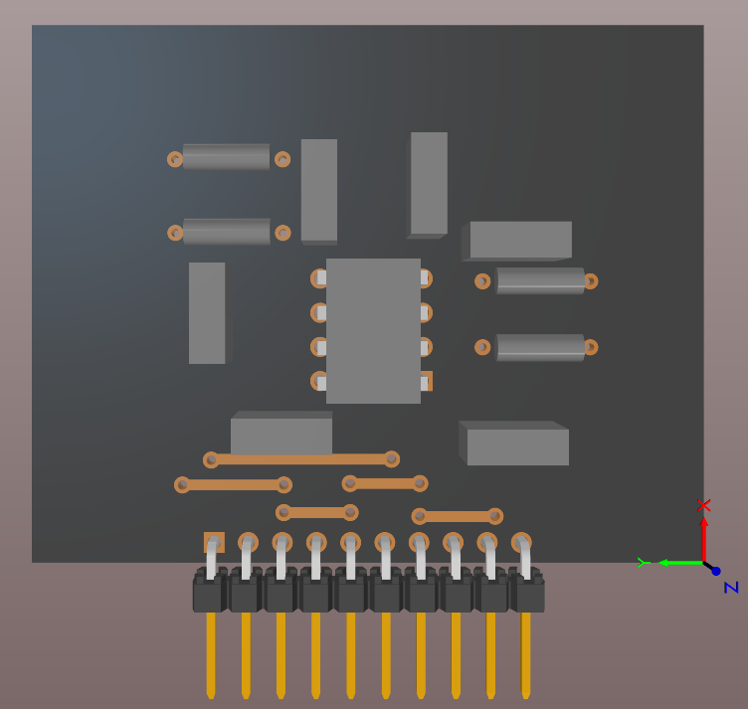
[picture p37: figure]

Figure 13 Module Entrée haute impédance + filtre schéma 3D vue de face

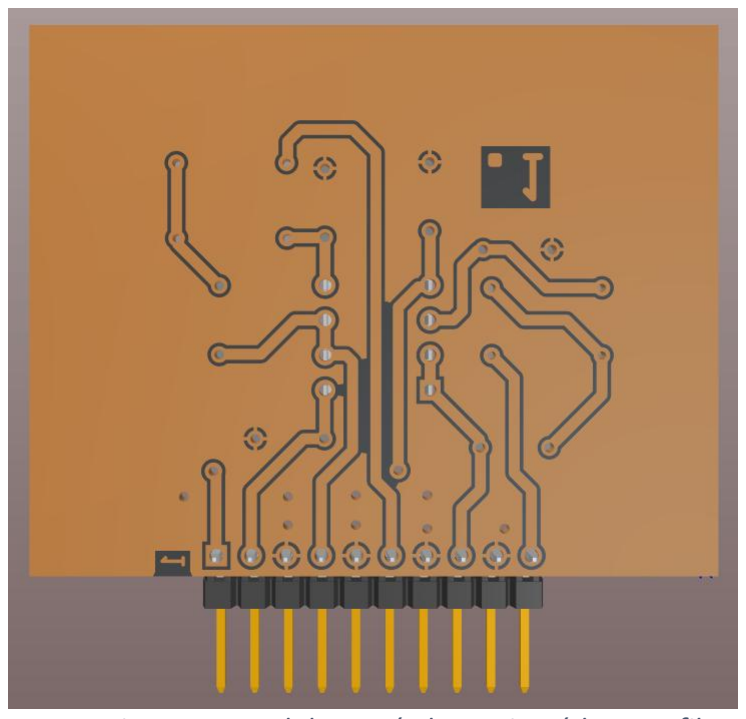
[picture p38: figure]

Figure 14 Module Entrée haute impédance + filtre schéma vue de dos

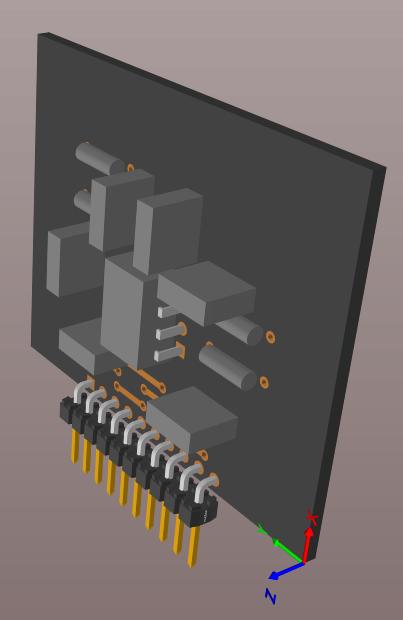
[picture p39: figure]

Figure 15 Module Entrée haute impédance + filtre schéma vue isométrique

3. Nomenclature
Référence schéma | Propriété | Fourniseur | Référence fournisseur | Coût unitaire | Quantité | Côut total
C1, C2 | 100nF | RS / CYU | 241-6523 | 0.1400 € | 2 | 0.2800 €
C3, C5 | 330pF | RS / CYU | 194-0483 | 0.1510 € | 2 | 0.3020 €
C4, C6 | 820pF | RS / CYU | 194-0493 | 0.1510 € | 2 | 0.3020 €
J1 | Header 2.54mm 10*1 mâle angle droit | RS / CYU | 205-6283 | 0.1980 € | 1 | 0.1980 €
R1, R4 | 18k | RS / CYU | 199-7599 | 0.0170 € | 2 | 0.0340 €
R2, R3 | 8.2k | RS / CYU | 148-714 | 0.0108 € | 2 | 0.0216 €
U1 | TL082 | RS / CYU | 182-2463 | 0.8000 € | 1 | 0.8000 €
| | | | | Total | 1.9376 €

Tableau 2 Nomenclature Module Entrée haute impédance + filtre schéma

## VI.Réguler le gain du signal d’entrée. (FT2-1)

### A. Schéma électronique et fonctions techniques

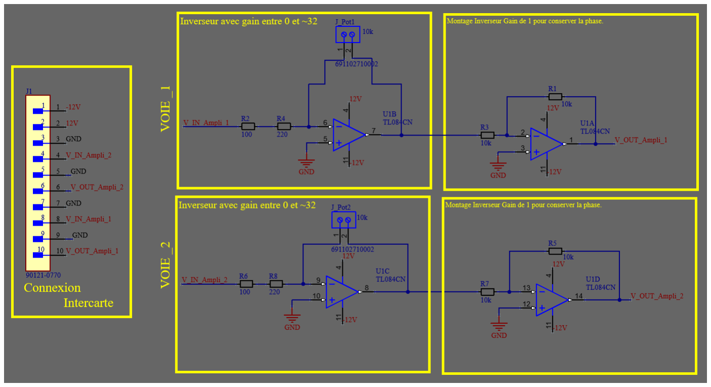
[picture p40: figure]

Figure 16 Module Gain schéma

### B. Notice de dimensionnement et choix des composants

Nous avons besoin d’appliquer un gain réglable entre 0 et 33 à notre signal, tout en conservant la phase entre l’entrée et la sortie. Pour cela, nous avons choisi deux montages inverseurs en cascade :

- Le premier étage permet d’amplifier le signal.
- Le second étage rétablit la phase pour obtenir un signal final non inversé.

Calcul du gain pour le premier étage :

Dans un amplificateur inverseur, où Rin est la résistance d’entrée et Rcr la résistance de contre-réaction, le gain G est donné par la relation :

G =

Vout
Vin = −

Rcr
Rin
Nous choisissons un potentiomètre de 10 kΩ pour Rcr , permettant un réglage progressif du gain.

Gain minimum (Rcr = 0 Ω) :

−

Rcr
Rin = −

0
Rin = 0

Peu importe la valeur de Rin, le gain est nul.

Gain maximum (Rcr = 10 kΩ, G = 33) :

G = −

Rcr
Rin = −

10k
Rin = −33

Rin =

10k
33 = 305oℎm

Cette valeur n’étant pas normalisée, nous utilisons deux résistances en série : 220 Ω + 100 Ω = 320 Ω, soit un gain réel de 31.25 au lieu de 33, ce qui reste acceptable.

Calcul du gain pour le second étage :

Le second étage doit avoir un gain de 1 pour conserver l’amplitude du signal tout en rétablissant sa phase :

G = 1 =

Rcr
Rin => Rcr = Rin

Nous choisissons donc Rcr = Rin = 10kohm.

Nous devons réaliser ce même montage pour les deux entrées analogiques du système.

L’amplificateur opérationnel utilisé est un TL084, qui contient quatre AOP dans un même circuit intégré, optimisant ainsi l’encombrement et la consommation d’énergie.

Pour assurer une connexion inter carte en montage vertical, un header mâle 2.54 mm angle droit est utilisé.

Les résistances utilisées auront une puissance de ¼ W, suffisante pour ce type d’application.

### C. Documents de contrôle de fabrication

1. Typon – Visuel Gerber

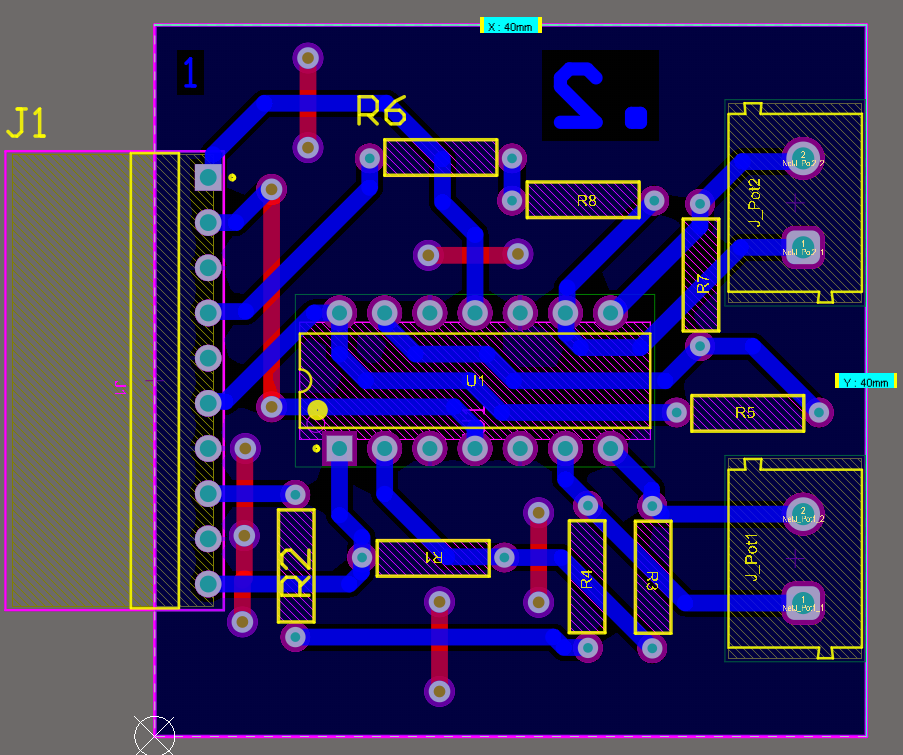
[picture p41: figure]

Figure 17 Module Gain Gerber

2. Plan de montage (visuel 3D)

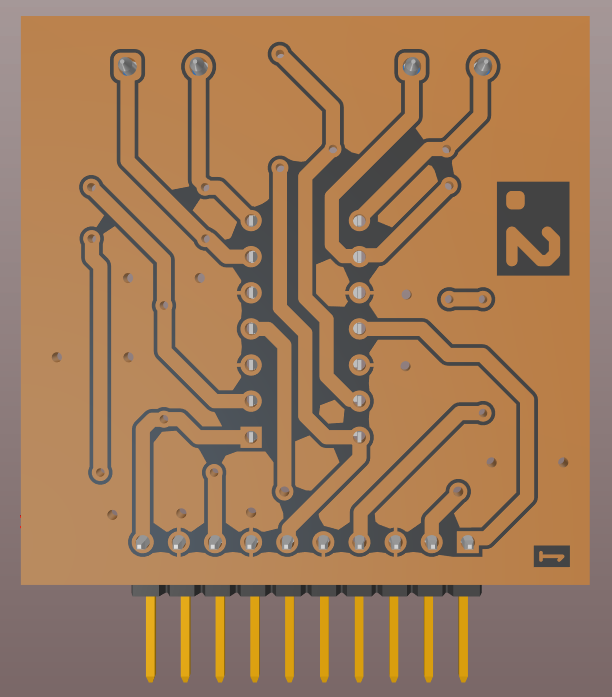
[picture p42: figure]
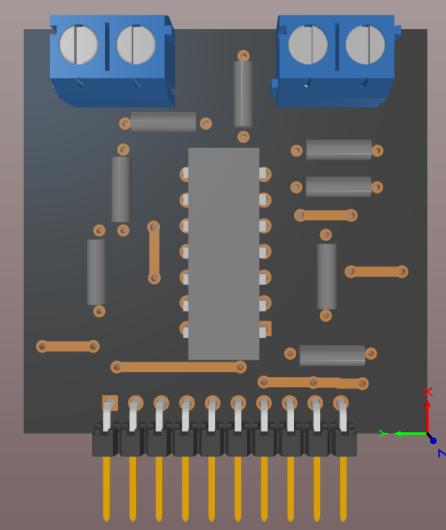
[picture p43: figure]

Figure 18 Module Gain 3D vue de face | Figure 19 Module Gain 3D vue de dos

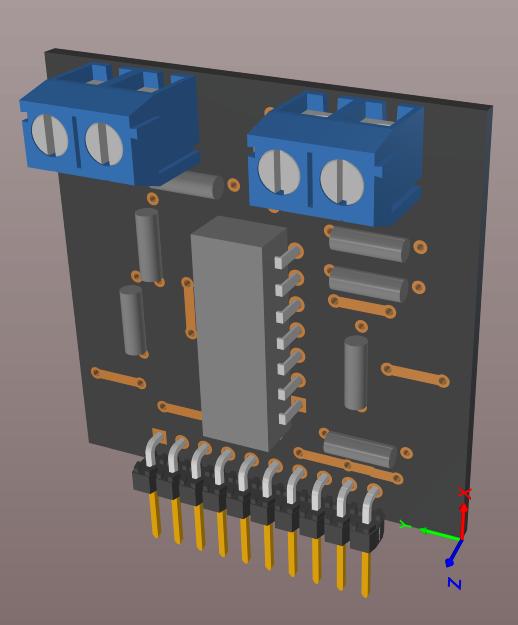
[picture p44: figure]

Figure 20 Module Gain 3D vue isométrique
3. Nomenclature
Référence schéma | Propriété | Fourniseur | Référence fournisseur | Coût unitaire | Quantité | Côut total
J1 | Header 2.54mm 10*1 mâle angle droit | RS / CYU | 205-6283 | 0.1980 € | 1 | 0.1980 €
J_Pot1, J_Pot2 | Mpot 10kohm | RS / CYU | 468-8705 | 4.2500 € | 2 | 8.5000 €
R1, R3, R5, R7 | 10kohm | RS / CYU | 707-7745 | 0.1640 € | 4 | 0.6560 €
R2, R6 | 100ohm | RS / CYU | 131-132 | 0.0500 € | 2 | 0.1000 €
R4, R8 | 220ohm | RS / CYU | 135-819 | 0.0420 € | 2 | 0.0840 €
U1 | TL084 | RS / CYU | 517-3181 | 0.4480 € | 1 | 0.4480 €
| | | | | Total | 9.7880 €

Tableau 3 Nomenclature Module Gain

## VII. Appliquer un décalage (offset) sur le signal analogique AC

(FT2-2)

### A. Schéma électronique et fonctions techniques

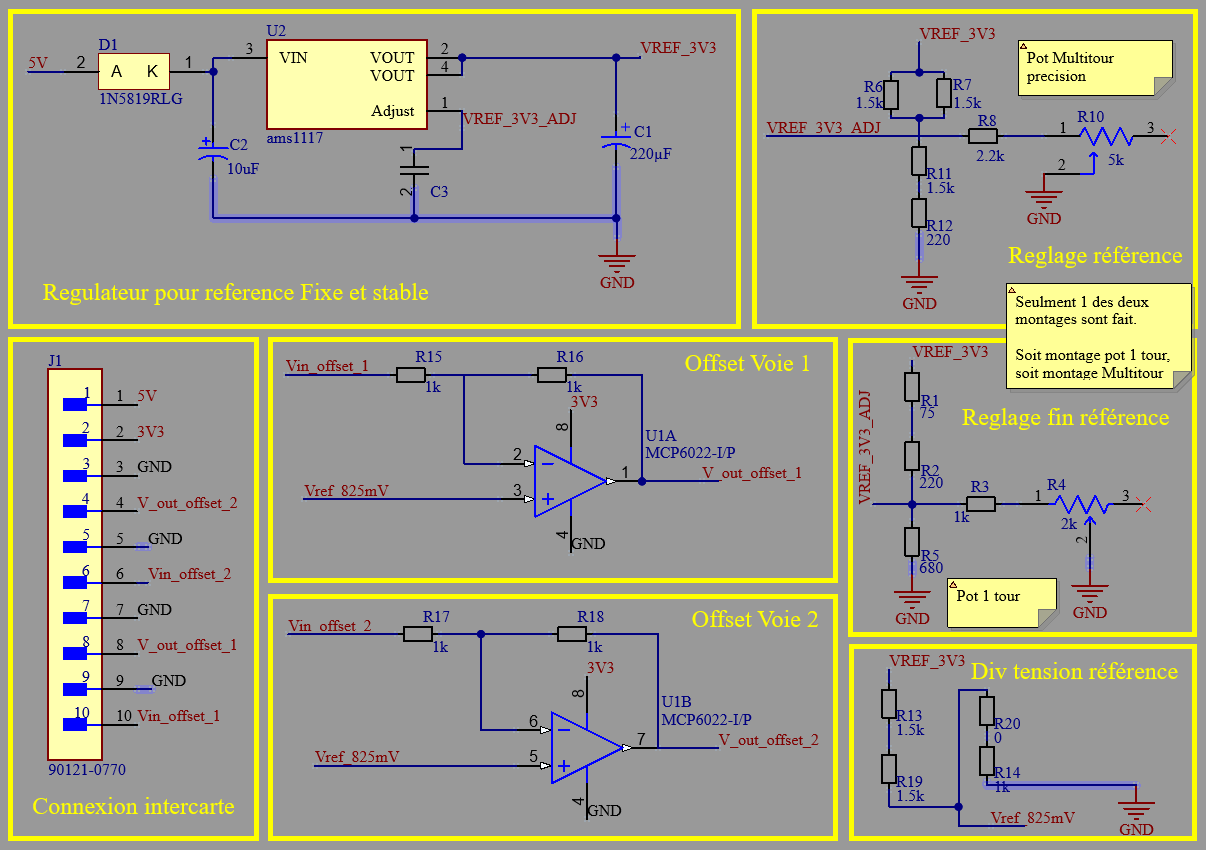
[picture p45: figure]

Figure 21 Module Offset schéma

### B. Notice de dimensionnement et choix des composants

1. Reference de tension :
Nous avons besoin d’une tension de référence réglable autour de 3.3V, avec une plage d’ajustement comprise entre 3.0V et 3.6V pour plus de précision.

Pour cela, nous utilisons un régulateur linéaire ajustable LT1117, choisi pour sa compacité et sa stabilité. Un potentiomètre permet d’affiner le réglage de la tension de sortie.

Montage simplifiée :

Figure 22 Montage simplifié régulateur de tension

La tension de sortie d’un régulateur LT1117 réglable est donnée par l’équation :

Vout = 1.25 ∗ (1 +

R2
R1

)

Ne pas tenir compte des annotations dans les calcul suivantes et Figure xx pour le montage final.

Montage réglable :

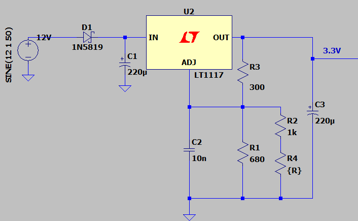
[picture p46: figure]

Figure 23 Montage complète régulateur de tension réglable

Nous proposons un montage réglable, dont l’expression généralisée est :

Vout = 1.25 ∗ (1 +
R1

′ =

R1(R2 + R4)
R1 + (R2 + R4)

R3 = R3′ )

En fixant R1 = 680, R3 = 300 et R4 réglable. Nous nous trouvons avec l’expression suivante :

Vout = 1.25 ∗ (1 +

680(R2 + R4)
680 + (R2 + R4)

300 )

Calcul des valeurs pour les extrémités de la plage de réglage :

- R4 minimum = 0ohm réglage Vout minimum 3V : Vout = 3V = 1.25 ∗ (1 +

680(R2)
680 + (R2)

300 )

Cela nous donne R2 = 1098.46 ohm or la valeur n’est pas normalisée donc nous choisissons R2 = 1kohm.

- R4 maximum = réglage Vout maximum = 3.6V:
Vout = 3.6V = 1.25 ∗ (1 +

680(1000 + R4)
680 + (1000 + R4)
300 | )

Cela nous donne R4 = 2306ohm or la valeur n’est pas normalisée donc nous choisissons un potentiomètre de 2kohm.

Avec ces valeurs, la tension de sortie est réglable entre 2.93V et 3.55V, ce qui correspond aux besoins du système.

Alternative pour un réglage plus précis

Un deuxième montage est proposé avec un potentiomètre multi tour de 5 kΩ pour un réglage plus fin. Pour garder les mêmes caractéristiques, toutes les autres résistances sont multipliées par 2.5 afin de conserver le même rapport de réglage.

Annotation correcte :

Montage Finale référence :

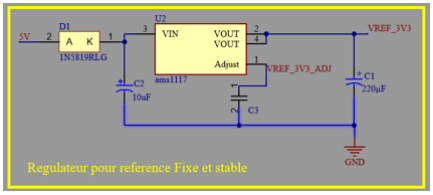
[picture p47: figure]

Figure 24 Montage régulateur de tension schéma

Figure 25 Montage résistances pour régulateur de reglable, Prescision potentiometre multitour

Figure 26 Montage résistances pour régulateur de tension réglable, potentiomètre 1 tour

Le circuit final intègre les deux options de réglage (classique et précis), permettant d’utiliser l’un ou l’autre sur le même PCB.

2. Ajout offset :
Ne pas tenir compte des annotations dans les calculs pour le montage finale, les annotations changent entre le montage finale et montage utilisé pour les calculs pour raison de simplicité.

Nous devons réaliser ce même montage pour les deux entrées analogiques du système.

Pour ajouter l’offset nous utilisons un montage différentielle :

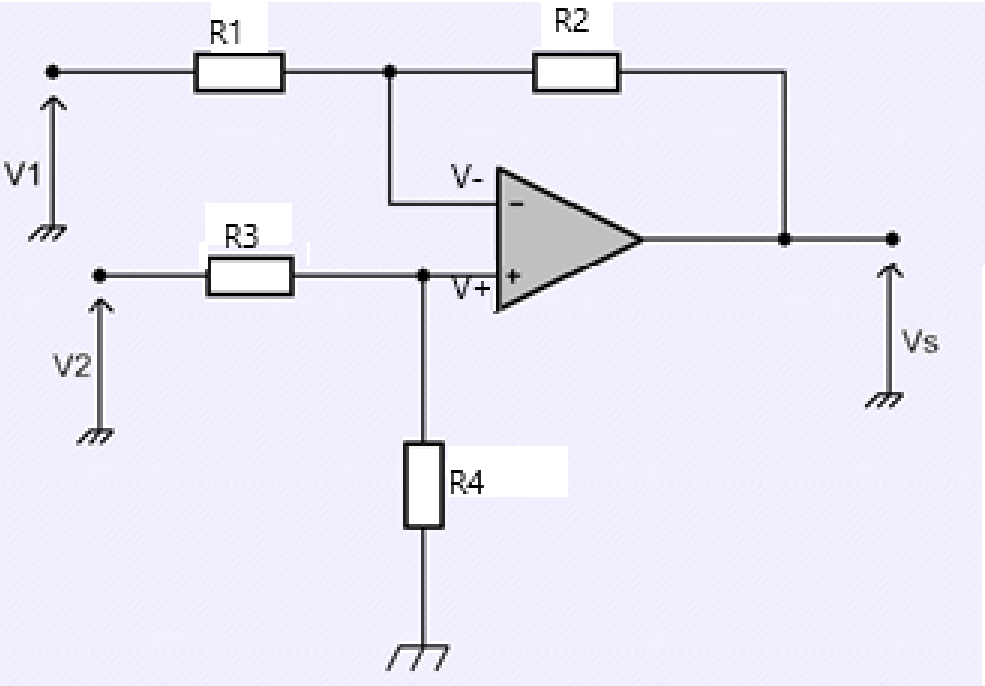
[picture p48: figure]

Figure 27 Montage Différentielle pour principe pour offset

En fixant R1 = R2 le montage a avec l’expression suivante :

Vs = 2 ∗ V2

R4
R4 + R3

− V1

V2 = 3.3V, nous voulons un offset de 1.65V donc :

1.65V = 2 ∗ 3.3

R4
R4 + R3
Fixons la valeur de R3 à 3kohm : 1.65V
2 ∗ 3.3V

=

R4
R4 + 3koℎm

=

1
4
En multipliant des deux côtés par (R4+3k) :

R4 =

1
4

(R4 + 3k)

3R4 = 3k => R4 = 1koℎm.

L’amplificateur opérationnel utilisé est un MCP6022 un amplificateur rail to rail alimentation simple, qui contient deux AOP dans un même circuit intégré, optimisant ainsi l’encombrement et la consommation d’énergie, cette AOP est aussi utilisée pour réaliser la fonction FT9-1 avant d’envoyer le signal vers le module ADC.

Pour assurer une connexion inter carte en montage vertical, un header mâle 2.54 mm angle droit est utilisé.

Les résistances utilisées auront une puissance de ¼ W, suffisante pour ce type d’application.

Annotation correcte :

Montage Finale Offset :

Figure 28 Diviseur de tension pour référence de Montage Offset

Figure 29 Montage Différentielle offset 2 voies

### C. Documents de contrôle de fabrication

1. Typon – Visuel Gerber

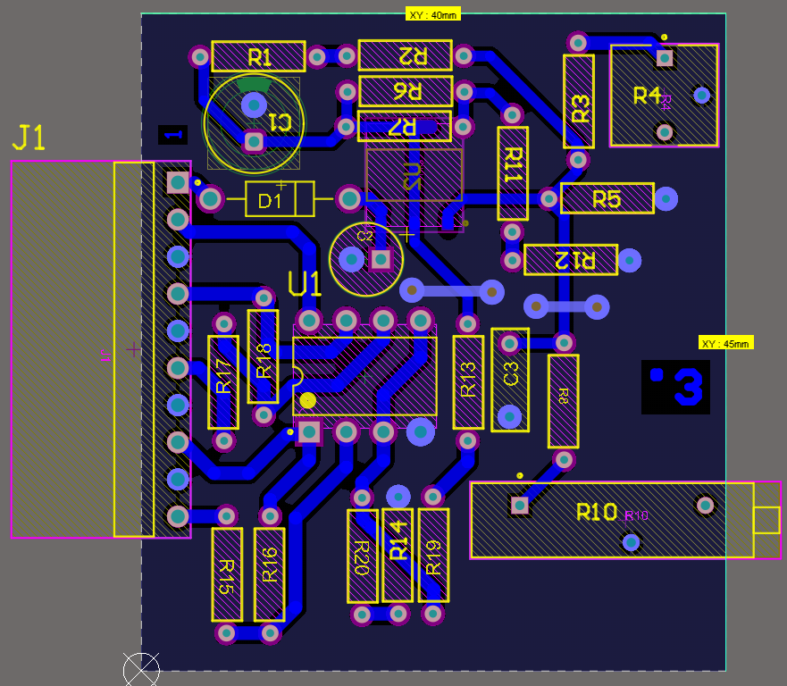
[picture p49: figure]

Figure 30 Module offset gerber

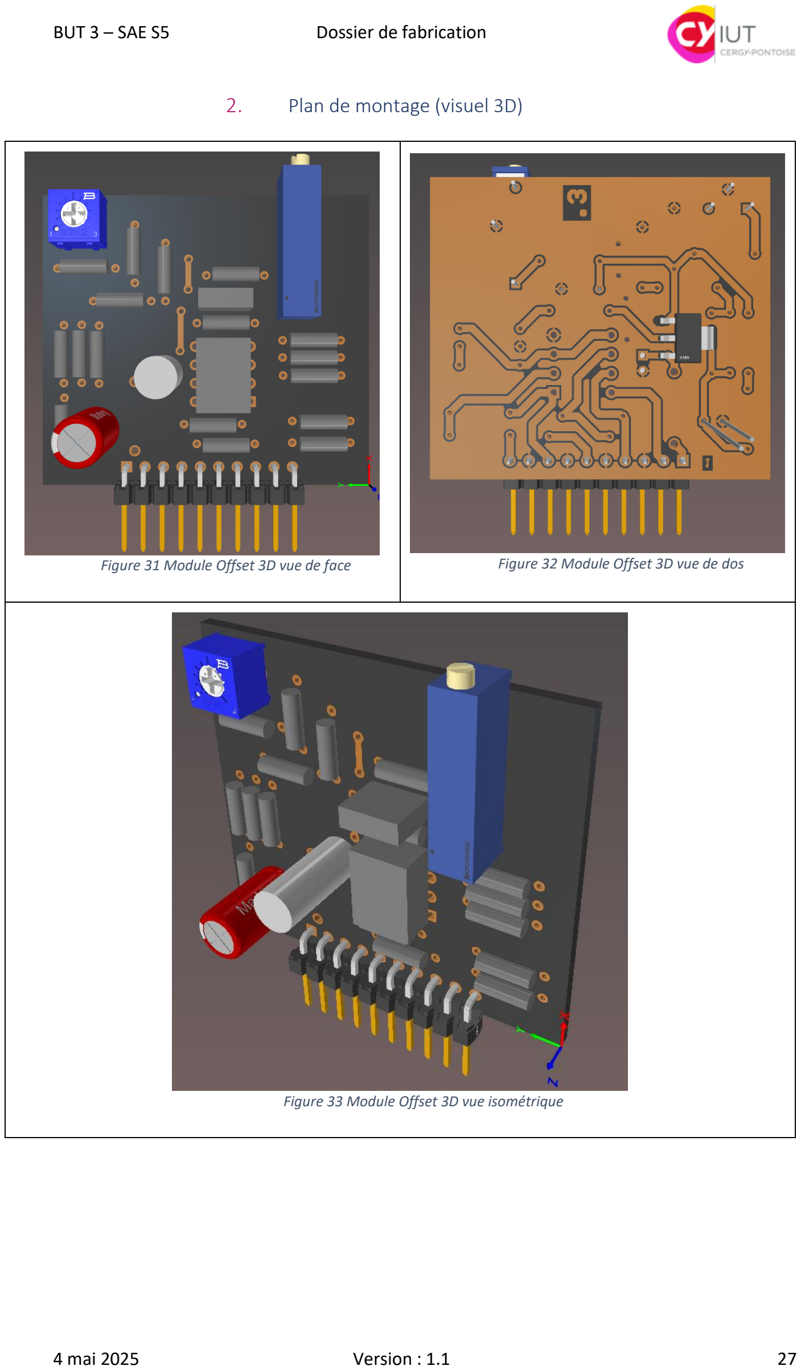
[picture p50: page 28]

2. Plan de montage (visuel 3D)
Figure 31 Module Offset 3D vue de face | Figure 32 Module Offset 3D vue de dos

Figure 33 Module Offset 3D vue isométrique

3. Nomenclature
Référence schéma | Propriété | Fourniseur | Référence fournisseur | Coût unitaire | Quantité | Côut total
C1 | 220uF, 16V, pol | RS / CYU | 839-6438 | 0.1480 € | 1 | 0.1480 €
C2 | 10uF, 50V, pol | RS / CYU | 468-8705 | 0.1680 € | 1 | 0.1680 €
C3 | 10nF, 100V | RS / CYU | 707-7745 | 0.1880 € | 1 | 0.1880 €
D1 | Schottky | RS / CYU | 654-7145 | 0.3600 € | 1 | 0.3600 €
J1 | Header 2.54mm 10*1 mâle angle droit | RS / CYU | 205-6283 | 0.1980 € | 1 | 0.1980 €
R1 | 75ohm | RS / CYU | 199-7937 | 0.0170 € | 1 | 0.0170 €
R2, R12 | 220ohm | RS / CYU | 135-819 | 0.0420 € | 2 | 0.0840 €
R3, R14, R15, R16, R17, R18 | 1kohm | RS / CYU | 199-7601P | 0.0140 € | 6 | 0.0840 €
R4 | Pot 2k 1 tour Réglage sur le côté | RS / CYU | 522-1072P | 0.8400 € | 1 | 0.8400 €
R5 | 680ohm | RS / CYU | 148-461 | 0.0120 € | 1 | 0.0120 €
R6, R7, R11, R13, R19 | 1.5kohm | RS / CYU | 199-7606 | 0.0170 € | 5 | 0.0850 €
R8 | 2.2kohm | RS / CYU | 199-1815P | 0.0130 € | 1 | 0.0130 €
R10 | pot 5k multi tour | RS / CYU | 144-2070 | 1.0360 € | 1 | 1.0360 €
R20 | 0ohm / fil | RS / CYU | NA | -€ | 1 | -€
U1 | MCP6022 | RS / CYU | 770-9811 | 1.7560 € | 1 | 1.7560 €
U2 | LT1117 /AMS1117 | RS / CYU | 535-8663P | 1.2440 € | 1 | 1.2440 €
| | | | | Total | 6.2330 €

Tableau 4 Nomenclature Module Offset

## VIII. Convertir le signal analogique en numérique (FT3)

### A. Schéma électronique et fonctions techniques

1. Présentation des schémas électroniques Le circuit est conçu autour d’un convertisseur analogique-numérique (ADC) de haute précision. Les points suivants décrivent les blocs fonctionnels intégrés dans le schéma :

Génération de la tension de référence :

Une tension de référence réglable est générée à l’aide d’un régulateur de tension et potentiomètre de précision, suivie d’un filtre passe-bas RC conforme aux recommandations du datasheet de l’ADC, afin de garantir la stabilité et la pureté du signal de référence.

Sélection de la tension de référence :

Un cavalier (jumper) permet de choisir entre une référence externe (apportée via un connecteur) ou celle générée localement sur la carte.

Alimentation analogique dédiée :

Conformément aux recommandations du constructeur, la section analogique de l’ADC est alimentée séparément via un régulateur faible bruit, pour éviter toute interférence numérique.

Sélection de l’horloge ADC :
Un second cavalier permet de choisir entre l’horloge interne de l’ADC ou une horloge externe fournie par un oscillateur présent sur le PCB.

ADC :

Filtrage anti-repliement (anti-aliasing) :

Un filtre passe-bas analogique (de type RC) est placé à l’entrée de l’ADC afin d’éliminer les composantes fréquentielles supérieures à la moitié de la fréquence d’échantillonnage (ici 1.4MHz) (selon le critère de Nyquist), empêchant ainsi les artéfacts liés au repliement spectral.

Connecteurs externes :
Des connecteurs sont prévus pour raccorder les signaux analogiques à mesurer, ainsi que pour une référence externe ou une horloge externe si nécessaire.

2. Fonctionnalités principales et interactions entre les composants
Le schéma électronique permet une numérisation fiable de signaux analogiques dans un environnement contrôlé :
- Le potentiomètre de précision, en association avec le filtre, stabilise la tension de référence utilisée par l’ADC lorsqu’elle est sélectionnée via le cavalier.
- Le régulateur linéaire fournit une tension d'alimentation propre à la section analogique, séparée de l'alimentation numérique pour minimiser les bruits de commutation.
- Les cavaliers de sélection (référence, horloge) permettent une configuration flexible du système en fonction des besoins de test ou d'intégration.
- Le filtre anti-repliement joue un rôle crucial dans la fidélité de la conversion, en limitant les signaux d’entrée aux bandes fréquentielles compatibles avec le taux d’échantillonnage.
- Le connecteur d’entrées/sorties permet la communication SPI entre Raspberry pi via carte mère.

### B. Documents de contrôle de fabrication

1. Typon – Visuel Gerber

2. Plan de montage (visuel 3D)

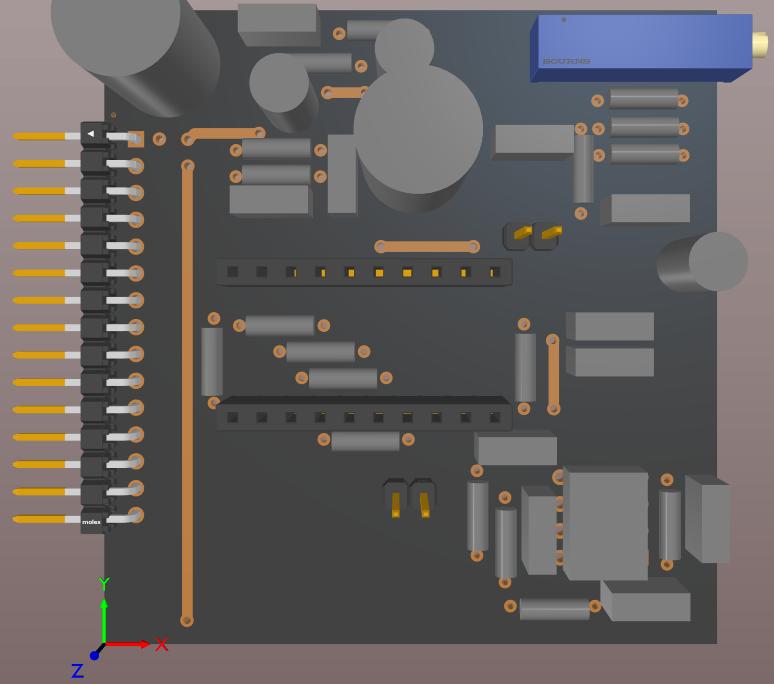
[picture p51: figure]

3. Nomenclature
Référence schéma | Propriété | Fourniseur | Référence fournisseur | Coût unitaire | Quantité | Côut total
R2 | 5k | RS / CYU | NA | 1.6200 € | 1 | 1.6200 €
J3 | 15pin 2.54mm Male rightangle RS / CYU | | NA | 0.3000 € | 1 | 0.3000 €
U1, U4 | ams1117 | RS / CYU | NA | 0.2000 € | 2 | 0.4000 €
C9, C10, C13, C14, C19 | 100nF | RS / CYU | NA | 0.0800 € | 5 | 0.4000 €
C3, C12 | 100nF | RS / CYU | NA | 0.0800 € | 2 | 0.1600 €
C15, C17 | 330pF | RS / CYU | NA | 0.1200 € | 2 | 0.2400 €
C16, C18 | 1nF | RS / CYU | NA | 0.1200 € | 2 | 0.2400 €
C1, C6 | 220uF pol | RS / CYU | NA | 0.9400 € | 2 | 1.8800 €
C2, C4, C8 | 10uF pol | RS / CYU | NA | 0.1000 € | 3 | 0.3000 €
J1, J5 | 10pin 2.54mm femaleRS / CYU | | NA | 0.2500 € | 2 | 0.5000 €
U5 | MCP6022-I/P | RS / CYU | NA | 2.0000 € | 1 | 2.0000 €
R1 | 2.2k | RS / CYU | NA | 0.0700 € | 1 | 0.0700 €
R3 | 8.2k | RS / CYU | NA | 0.2000 € | 1 | 0.2000 €
R4, R14, R22 | 10k | RS / CYU | NA | 0.0700 € | 3 | 0.2100 €
R5 | 4.7k | RS / CYU | NA | 0.0700 € | 1 | 0.0700 €
R7 | 220 | RS / CYU | NA | 0.0700 € | 1 | 0.0700 €
R8, R9 | 10 | RS / CYU | NA | 0.0700 € | 1 | 0.0700 €
R11 | 270 | RS / CYU | NA | 0.0700 € | 1 | 0.0700 €
R13 | 100 | RS / CYU | NA | 0.0700 € | 1 | 0.0700 €
R15 | 22k | RS / CYU | NA | 0.0700 € | 1 | 0.0700 €
R16, R17, R18, R19, R20 | 1k | RS / CYU | NA | 0.0700 € | 5 | 0.3500 €
R23 | 22k | RS / CYU | NA | 0.0700 € | 1 | 0.0700 €
J2, J4 | 2pin 2.54mm male | RS / CYU | NA | 0.1000 € | 2 | 0.2000 €
ADC avec conn Externe | MCP 3564 | RS | 203-4731 | 5.1240 € | 1 | 5.1240 €
| | | | | Total | 14.6840 €

## IX. Gérer l’entrée audio numérique (FT1, FT6)

### A. MIDI

Pour la gestion des messages MIDI, nous utilisons la bibliothèque WiringPi afin d’exploiter l’interface série de la Raspberry Pi.
Le programme se trouve dans le dépôt Git à l’adresse suivante :

#include "Proj_external_lib.h"

int main()
{
int fd;
int count;
unsigned int nextTime;

// Open the serial port
if ((fd = serialOpen("/dev/ttyS0", 115200)) < 0)
{
fprintf(stderr, "Unable to open serial device: %s\n", strerror(errno));
return 1;
}

// Initialize wiringPi library
if (wiringPiSetup() == -1)
{
fprintf(stdout, "Unable to start wiringPi: %s\n", strerror(errno));
return 1;
}
uint8_t byte_count = 0;
while (1)
{
// Check if data is available to read
if (serialDataAvail(fd)) {
unsigned char receivedByte = serialGetchar(fd); // Read a byte

printf("%d ", receivedByte);
fflush(stdout);
byte_count++;
if(byte_count==3)
{
printf("\n");
byte_count = 0;
}

}
}

serialClose(fd);
printf("\n");
return 0;
}
Ce programme lit les données MIDI reçues sur le port série /dev/ttyS0, à 115200 bauds, et les affiche par groupe de trois octets (correspondant à un message MIDI standard).

### B. ADC SPI

La conversion des signaux audio analogiques en numérique se fait via un ADC piloté en SPI.

Voici les étapes nécessaires à son fonctionnement :

1. Génération du signal d’horloge (MCLK) Avant toute chose, il faut activer une horloge de 11.265 MHz, fréquence typique pour l’audio 44.1 kHz (256×Fs).

Cela se fait via un script shell disponible sur Git à l’emplacement :

SousSysteme_Entrees/Linux_WorkSpace/C_Cpp_Programming/Function_SS/CLK_11_265_000 Hz/CLK_11_265_000Hz.sh

Pré-requis : la bibliothèque Pigpio doit être installée (présente par défaut sur Raspberry Pi OS).

Pour lancer le script :

./ CLK_11_265_000Hz.sh 11265000

2. Activation du SPI
Une fois le SPI activé, il est nécessaire de programmer l’interface pour communiquer avec l’ADC.

Cela implique :

- La configuration des broches SPI (MOSI, MISO, SCLK, CS)
- L’envoi de commandes de configuration à l’ADC selon son datasheet (mode, fréquence d’échantillonnage, résolution, etc.)
- La lecture cyclique des données converties
- L’intégration des données dans le flux audio global

Un exemple (qui est à Finir) de programme SPI sera fourni dans le répertoire :

SousSysteme_Entrees/Linux_WorkSpace/C_Cpp_Programming/Function_SS/Spi_Mcp3564

Ou

Main/SousSysteme_Entrees/Linux_WorkSpace/C_Cpp_Programming/Exemples/Spi_Test

https://www.raspberryme.com/activer-linterface-spi-sur-le-raspberry-pi/

Note : Pour compiler un programme C ou C++ un script a été fait :

build.sh qui stock le fichier exécutable dans build.

Voici les étapes à suivre :

En utilisant le terminal aller dans le dossier de programme que vous voulez compilez ici je prends l’exemple de : (on utilise la commande cd pour ça)

SousSysteme_Entrees/Linux_WorkSpace/C_Cpp_Programming/Function_SS/MIDI_IN/Uart_data

Rendre le Script exécutable si ce n’est pas le cas avec :

chmod +x build.sh

Lancer le script :

./build.sh

Des fichier sont stocké dans dossier build donc aller dans le dossier build :

cd build

Puis lancer le fichier avec nom de programme, ici UART_data :

./UART_data.

(Note certains programmes peuvent demander un accès administrateur pour cella il faut mettre sudo devant la commande)

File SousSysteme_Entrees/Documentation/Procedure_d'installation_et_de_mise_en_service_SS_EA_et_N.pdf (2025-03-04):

BUT 3 – SAE S5

CY IUT – GEII Neuville

# Procédure d'installation et de mise en service

## Projet tutoré Mixeur Sous-système Entrées

## Document rédigé par : MUHAMMAD Asad Version : 1.0 [4 mars 2025]

BUT 3 – SAE S5 | Procédure d'installation et de mise en service

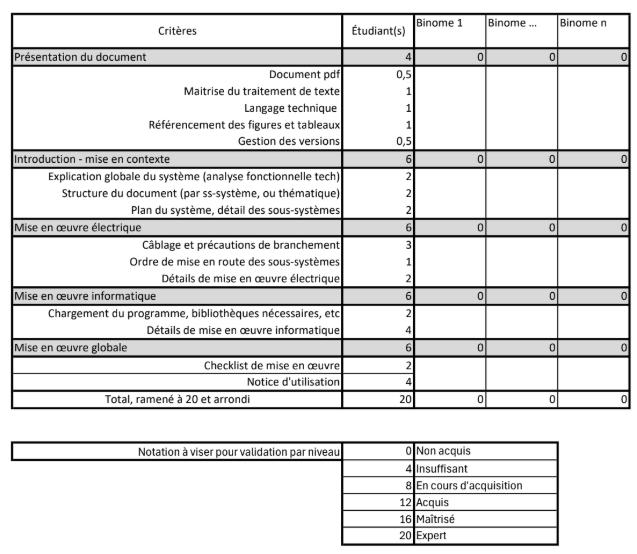
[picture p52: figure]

4 mars 2025 | Version : 1.0 | 1

## Historique des modifications et révisions de ce document :

N° de version | Date | Auteur | Description et circonstances de la modification
V 0 | | MUHAMMAD Asad | Brouillon : première version, modèle fourni.
V 1.0 | 02/03/2025 | MUHAMMAD Asad | Première rédaction complète du document.

## Grilles d'évaluations

## Avant-propos¹

Ce document présente la procédure d'installation et de mise en service de table de mixage audio destiné à offrir une solution compacte et performante pour le traitement et la gestion de signaux sonores.

Elle vise à assurer un déploiement fiable et sécurisé tout en respectant les exigences techniques du projet.

1 Référence : Gestion de projet, 50 outils pour agir ; F. Bouchaouir, Y. Dentinger, O. Englender ; Vuibert ;
2014. | Expression du besoin et cahier des charges fonctionnel ; J. Bernard-Bousières ; AFNOR ; 2012.

## Table des matières

## Table des Figures

## Tableaux

## I. Contexte du projet

### A. Situation et description

Le projet consiste à concevoir et réaliser une table de mixage audio automatique capable de traiter et de synchroniser plusieurs flux audios provenant d’instruments de musique. Ce dispositif sera intégré à l’Orchestrion, un système automatisé conçu pour reproduire les performances d’un orchestre en combinant différents instruments.

Développé dans le cadre de la SAE (Situation d’Apprentissage et d’Évaluation), ce projet sera présenté lors des Journées Portes Ouvertes de l’IUT de Cergy-Pontoise. Il met en avant la conception d’un dispositif électronique physique tout en respectant des contraintes écologiques et économiques.

### B. Besoins et objectifs

L’objectif principal de ce projet est de valoriser les enseignements du BUT GEII (Bachelor Universitaire de Technologie en Génie Électrique et Informatique Industrielle) à travers la création d’une unité de contrôle audio automatisée.

Ce mixeur audio doit permettre :

- Le traitement et la synchronisation de plusieurs sources sonores en temps réel.
- Une intégration optimisée au sein de l’Orchestrion, garantissant une interaction fluide avec les instruments automatisés.
- Une gestion efficace du signal audio tout en maintenant une faible consommation énergétique.

En plus des contraintes techniques, le projet répond également à des enjeux écologiques et économiques, en favorisant l’utilisation de composants optimisés et durables.

## II. Prérequis

Avant de commencer l’installation de Table de Mixage sous-systèmes Entrées analogiques et numériques, assurez-vous de disposer des éléments suivants :
1. Matériel :
- Alimentation et adaptateurs :
- Alimentation +12V, -12V, 3.3V, 5V.
- Adaptateurs secteur pour l'alimentation de la carte mère et des modules.
- Périphériques d’entrée :
- Instruments MIDI (avec connecteur jack 3,5 mm).
- Sources audio (avec connecteur jack 3,5 mm).
- Câbles audio 3.5mm
- Connecteurs et câbles supplémentaires :
- Câble IDC pour la connexion de la Raspberry Pi 4.
- Câbles d'alimentation et de masse (GND).
2. Logiciel :
- Firmware de la table de mixage :
- Téléchargez la dernière version du firmware depuis le dépôt officiel.
- Logiciels de configuration pour la Raspberry Pi :
- Raspberry Pi OS (anciennement Raspbian).
- Bibliothèques (WiringPi).

## III.Précautions

- Tous les instruments analogiques utilisés doivent envoyer un signal dont le niveau maximal est +4 dBu, correspondant au niveau ligne professionnel (1,736 V peak).
- Tous les signaux numériques (comme le MIDI) doivent être de niveau logique 3,3V.

## IV. Mise en Œuvre électrique

### A. Montage et connexion carte mère câblage et précaution de

| branchement
1. Liste des Connecteurs :
| • Alimentations : • +12V, -12V, 3.3V, 5V. • Masse (GND) : • Connectez toutes les masses à un point commun pour éviter les boucles de masse. • Entrées Audio Analogiques : • Connecteurs 3.5mm pour les sources audios. • Entrée Signal Numérique : • Connecteur Jack 3.5mm pour les signaux MIDI. • Raspberry Pi 4 : • Câble IDC pour la connexion à la carte mère. • Modules : • Module Suiveur. • Module Amplification. • Module Offset. • Module Conversion Analogique-Numérique.
2. Emplacement des connecteurs et Fixation mécanique :
| • Placez les connecteurs sur la carte mère en respectant les emplacements prévus. • Fixez mécaniquement les connecteurs à l'aide de vis ou de supports pour éviter tout déplacement accidentel. • Assurez-vous que les connecteurs sont bien alignés avant de souder ou de visser.

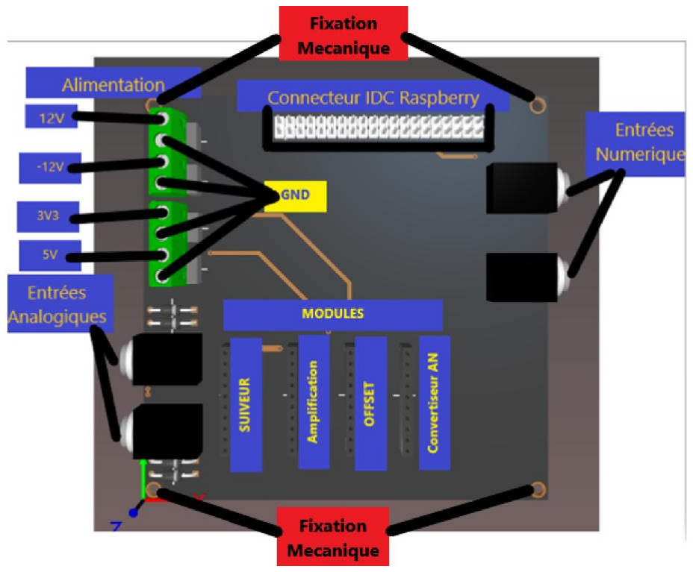
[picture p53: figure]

Figure 1 Carte mère emplacement connecteurs

### B. Installation des Cartes Modules et précaution de branchement

- Avant Tout branchement, vérifiez que l’alimentation est coupée pour éviter tout court-circuit.
- Les cartes modules doivent être branchées comme indiqué sur le schéma ci-dessous, en respectant l’orientation des cartes avec les composants du côté des connecteurs d’entrées analogiques.
- Vérifiez que chaque module est correctement inséré dans son connecteur correspondant sur la carte mère.
- Assurez-vous que les connecteurs sont bien enfoncés pour éviter les mauvais contacts.

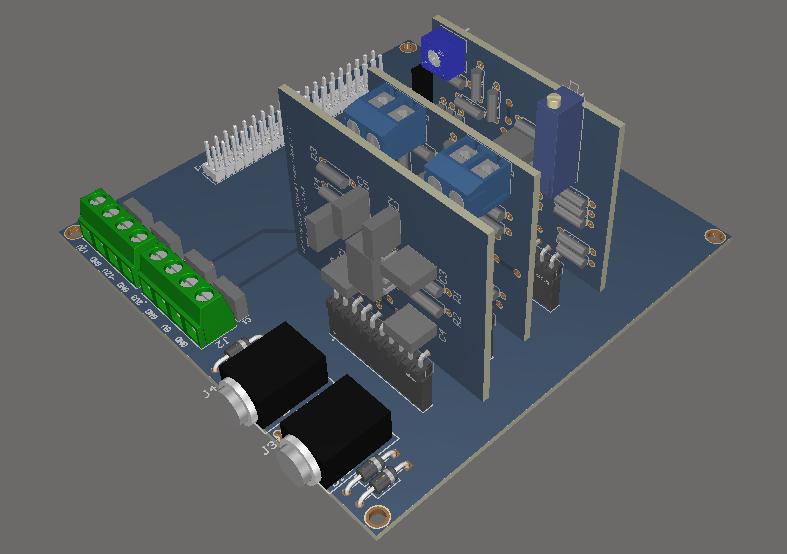
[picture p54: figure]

Figure 2 Carte Mère Branchement Modules

### C. Ordre de mise en route des sous systèmes

Étapes de Mise en Route :

- Connectez chaque module (Suiveur, Amplification, Offset, Conversion Analogique-Numérique) à la carte mère en respectant les emplacements prévus.
- Connectez la Raspberry Pi 4 à la carte mère en utilisant le câble IDC. Assurez-vous que la connexion est bien alignée et sécurisée.
- Avant de brancher les alimentations (+12V, -12V, 3.3V, 5V), vérifiez à l'aide d'un multimètre que toutes les tensions sont correctes. Ensuite, connectez les alimentations aux connecteurs prévus, comme indiqué en Figure 1.
- Branchez les instruments MIDI et les sources audio aux entrées correspondantes (3.5mm pour les sources audio, Jack 3.5mm pour les signaux MIDI).
- Allumez la Raspberry Pi et vérifiez qu’elle démarre correctement.
- Brancher le clavier et la souris si nécessaire.

## V. Mise en œuvre informatique

### A. Mise en place de Système d’exploitation Raspberry :

1. Matériel Nécessaire :
- Raspberry Pi 4B : Le micro-ordinateur principal du système.
- Carte SD de 32 Go : Pour installer le système d'exploitation.
- Clavier, Souris, Écran : Pour configurer la Raspberry Pi.
- Un autre PC : Pour préparer la carte SD et transférer les fichiers.
- Alimentation Raspberry Pi : Une alimentation stable de 5V/3A.
•
2. Installation du Système d’Exploitation :
- Étape 1 : Téléchargez et installez le logiciel Raspberry Pi Imager sur votre PC.
- Étape 2 : Insérez la carte SD dans votre PC et lancez Raspberry Pi Imager.
- Étape 3 : Sélectionnez Raspberry Pi OS (anciennement Raspbian) comme système d'exploitation.
- Étape 4 : Choisissez la carte SD comme destination et cliquez sur "Écrire" pour installer l'OS.

Avant toute manipulation physique de la carte SD, le système doit être complètement éteint.

- Étape 5 : Une fois l'installation terminée, insérez la carte SD dans la Raspberry Pi, connectez le clavier, la souris et l'écran, puis allumez la Raspberry Pi.
3. Activation des Ports UART : Étape 1 : Lancez le programme Raspberry Pi Configuration ou utilisez la commande :

sudo raspi-config
Étape 2 : Dans l’onglet Interfaces, désactivez Serial Port et Serial Console.

Étape 3 : Ouvrez le terminal et modifiez le fichier de configuration avec la commande :

sudo nano /boot/firmware/config.txt
Étape 4 : Ajoutez les lignes suivantes à la fin du fichier (En fonction d’uart qu’on veut activer), après [all] :
dtoverlay=disable-bt | # Désactive Bluetooth pour libérer ttyAMA0
dtoverlay=uart1 | # Active UART1
dtoverlay=uart2 | # Active UART2
dtoverlay=uart3 | # Active UART3
dtoverlay=uart4 | # Active UART4
dtoverlay=uart5 | # Active UART5
- Et de ne pas avoir la ligne suivante :

enable=uart0
- Étape 5 : Sauvegardez et quittez (Ctrl + X, puis Y, puis Entrée).
- Étape 6 : Redémarrez la Raspberry Pi pour appliquer les changements :

sudo reboot

Étape 7 : Vérifiez que les ports UART sont bien activés avec les commandes suivantes :

raspi-gpio get

ou

gpio readall

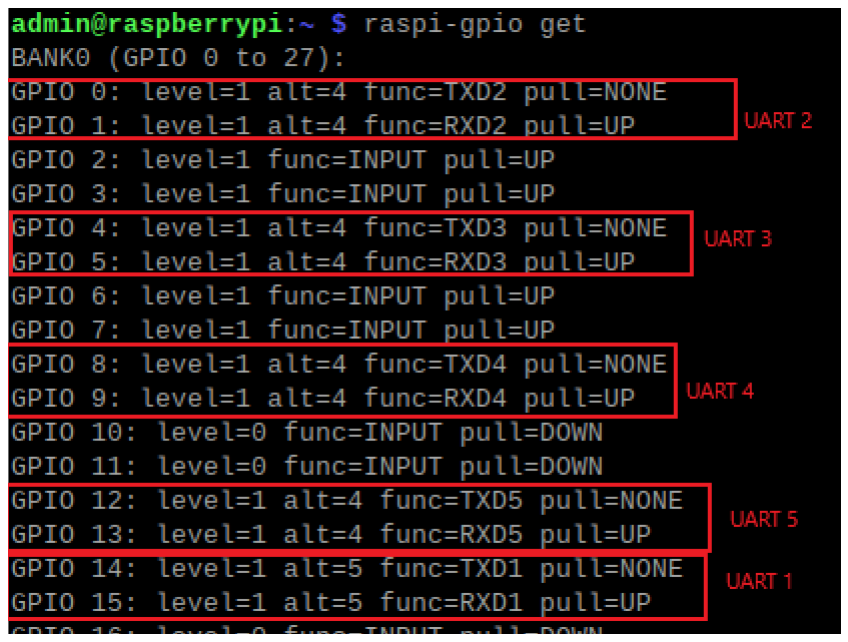
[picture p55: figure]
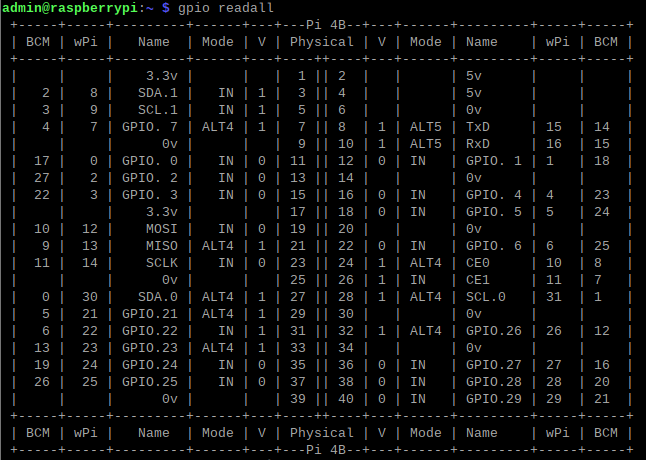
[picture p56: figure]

4. Vérification des Ports UART : Les ports UART activés sont généralement associés aux interfaces suivantes :

Tableau 1 Liste des Ports tty en fonction d'Uart

UART 1 | ttyAMA0
UART 2 | ttyAMA2
UART 3 | ttyAMA3
UART 4 | ttyAMA4
UART 5 | ttyAMA5

### B. Chargement des programmes et bibliothèques

1. Installation des Outils de Développement :
- Build Essential : Installez les outils de compilation avec la commande :

sudo apt install build-essential

2. Installation de WiringPi : Étape 1 : Installez Git pour cloner le dépôt WiringPi :

sudo apt install git
Étape 2 : Clonez le dépôt WiringPi :

git clone https://github.com/WiringPi/WiringPi.git cd WiringPi
Étape 3 : Compilez et installez WiringPi :

./build debian
mv debian-template/wiringpi-3.0-1.deb . sudo apt install ./wiringpi-3.0-1.deb
3. Téléchargement du Programme MIDI : Étape 1 : Téléchargez le programme Uart_data depuis le dépôt officiel :

Linux_Workspace/WorkSpace/MIDI_IN/

Lien vers le dépôt :

https://git.cyu.fr/geiin-ese-but3-sae/table-de-mixage/-/tree/Linux_Workspace/WorkSpace/MIDI_IN/Uart_data?
- Étape 2 : Modifiez le port UART dans le programme en fonction du signal que vous souhaitez récupérer.
- Étape 3 : Compilez le programme avec le script ./build.sh et exécutez le programme avec : ./uart_data:

./build.sh

cd build

./uart_data

Cette programme récupère les donnes midi sur un port UART. Modifiez-le en fonction de votre besoins ou ce que vous voulez faire avec ces données.

## VI.Mise en Œuvre globale

### A. Checklist

1. Vérification des Connexions Électriques :
- Tous les modules sont correctement connectés à la carte mère.
- Les alimentations (+12V, -12V, 3.3V, 5V) sont stables et conformes aux spécifications.
- Les entrées et sorties audio sont correctement branchées.
2. Vérification du Logiciel :
- Le système d'exploitation est correctement installé sur la Raspberry Pi.
- Les programmes et bibliothèques nécessaires sont installés et fonctionnels.
3. Vérification des Interfaces MIDI :
- Les interfaces MIDI sont reconnues par le système.
- Les signaux MIDI sont correctement reçus et traités.
4. Test Final :
- Testez les entrées audio pour vous assurer que le système fonctionne comme prévu.

## La fonctionnalité de conversion analogique-numérique n’est pas encore disponible. Une fois implémentée, le document sera mis à jour et le programme sera publié sur

l’espace d’hébergement officiel GitLab.

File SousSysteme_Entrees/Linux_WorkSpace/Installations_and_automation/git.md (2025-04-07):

# GIT
Comme on va programmer sur raspberry ou l'application github n'est pas disponible, il faut utiliser git pour pouvoir faire des commits sur github. Pour faire ça on va utiliser la méthode d'utilisation de protocole SSH pour se connecter a notre repo et faire un clone de repo github et d'autres actions telles que commit push, pull ...etc.

Donc Voici les étapes a survies : 

## Installation des mis à jours et installation de git : 
dans le terminal linux (CTRL+ALT+T)  executer les lines suivantes: 
```bash
sudo apt update
sudo apt install git
``` 

## generer une clé SSH
```bash
ssh-keygen -t rsa -b 4096 -C "ADD_MAIL@example.com" # remplacer ADD_MAIL@example.com par votre adresse mail personnel
```
 
vous auriez une confirmation de repertiore 
`Enter file in which to save the key (/home/aetherlinx/.ssh/id_rsa):` , laisser la ligne vide et faites entrer.
Dans mon cas (SUR MON PC) `/home/aetherlinx/.ssh/id_rsa` est le chemin vers le fichier  `id_rsa`. il faut bien noter le chemin `/home/aetherlinx/.ssh`.
on va vous demande ensuite d'ajouter un mots de passe on peux laisser ça vide, une 2eme confirmation de mot de passe, encore avec touche entere on laisse ça vide.

Dans l'etape précédente nous avons noté le chemin `/home/aetherlinx/.ssh/` vers notre clé , le fichier  `id_rsa`.
avec la commande suivante on change notre repertoire de travail en allant vers `/home/aetherlinx/.ssh/` :
`cd /home/aetherlinx/.ssh/ `

ici on demarrer le program agent SSH :
` eval "$(ssh-agent -s)" `
 
puis on fournit la clé SSH a notre programme agent : 
` ssh-add ~/.ssh/id_rsa `

dans le meme repertoire on affiche notre clé SSH : 
` cat ~/.ssh/id_rsa.pub `

ON COPIE LA CLE SSH.

On revient vers notre repertoire de travail de base avec : 
` cd `

## Ajouter la clé SSH sur GitHub
Sur votre github aller sur `github>settings> SSH & GPG keys > New SSH Key > Type cle : Authentication > coller la clé SSH copie avant > Valider`

Sur Github aller dans le reop que vous voulez copier et copier le URL SSH de cette repo.
dans mon cas `git@github.com:A-s-a-d/Table-de-Mixage.git`

## Differentes actions git

### clone : On reviens vers notre linux. 
dans le terminal : on fait un clone de repo avec URL SSH: 
` git clone git@github.com:A-s-a-d/Table-de-Mixage.git `

on change de repertoire pour aller vers notre repo github qui est maintenaant disponible en local avec le Nom: 
dans mon ça c'est `Table-de-Mixage`
` cd Table-de-Mixage `

### checkout : changer de Branche et aller vers `nom_de_branche` : 
`git checkout nom_de_branche `

Maintenant on peux travailler dans c'est répertoires, avec un projet que vous pouvez crée directement dans le  répertoire.

### add , preparer les fichiers pour le commit : 
`git add .`

### commit : faire un commit 
`git commit -m "COMMENTAIRE_POUR_COMMIT" `

### push : faire un 'push' vers origin : 
` git push origin BRANCH_NAME`

### branch : verifier la branche actuelle :
`git branch`

### pull : mettre a jour la branche en local depuis github ou gitlab
`git pull`
`git pull origin your-branch`

### supprimer le repo local : ` rm -rf repo/`

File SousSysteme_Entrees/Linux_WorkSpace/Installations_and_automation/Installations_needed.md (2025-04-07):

# Programmes a installer :

## build-essential for gcc and g++ compiler plus cmake
> Includes gcc, g++ and cmake
`sudo apt install build-essential`

## gdb (not sure but might be usefull for debugging)
`sudo apt install gdb`

## vscode for code editing
`sudo apt install vscode`

## glow for Markdown file view in terminal
> Debian/Ubuntu
[glow github link](https://github.com/charmbracelet/glow)
```
sudo mkdir -p /etc/apt/keyrings
curl -fsSL https://repo.charm.sh/apt/gpg.key | sudo gpg --dearmor -o /etc/apt/keyrings/charm.gpg
echo "deb [signed-by=/etc/apt/keyrings/charm.gpg] https://repo.charm.sh/apt/ * *" | sudo tee /etc/apt/sources.list.d/charm.list
sudo apt update && sudo apt install glow
```

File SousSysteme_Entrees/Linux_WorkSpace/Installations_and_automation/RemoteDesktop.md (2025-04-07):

# Linux to Windows Remote Desktop

On linux Machine

`ifconfig` to get IP 

in linux install : 
`sudo apt install xrdp`

`sudo apt install tightvncserver`

TO start a remote server as ROOT use :
`sudo vncserver`

To start vnc server as some other user (in my case admin) with resolution wanted :
`sudo -u admin vncserver :1 -geometry 1920x1080 -depth 24 -dpi 96`

This also works but resolution isn't right :
`sudo -u admin vncserver :1`

to kill a process (remote server) use : 
`vncserver -kill :screen_number`

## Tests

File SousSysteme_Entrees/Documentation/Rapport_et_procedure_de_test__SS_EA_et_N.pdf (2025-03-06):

BUT 3 – SAE S5

CY IUT – GEII Neuville

# Procédure et Rapport de Test

## Projet tutoré Mixeur Sous-système Entrées

## Document rédigé par : MUHAMMAD Asad Version : 1.0 [6 mars 2025]

BUT 3 – SAE S5 | Rapport de Test

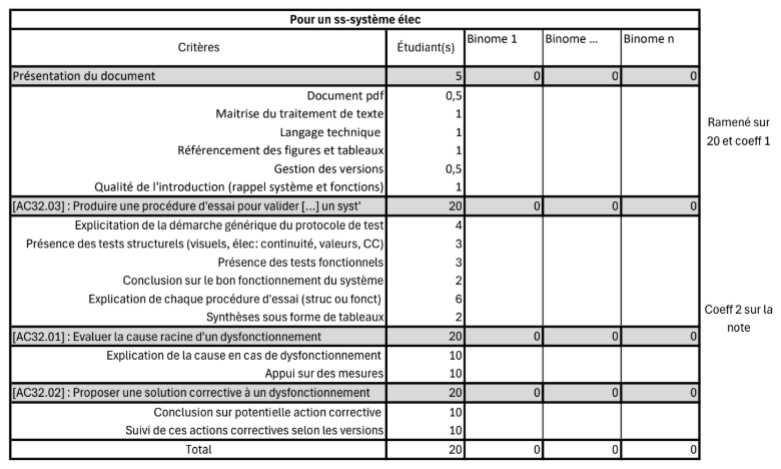
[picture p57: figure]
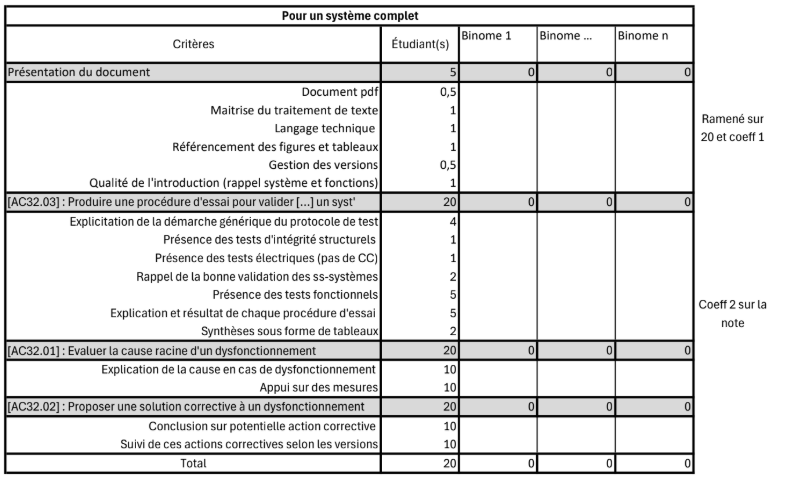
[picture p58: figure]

6 mars 2025 | Version : 1.0 | 1

## Historique des modifications et révisions de ce document :

N° de version | Date | Auteur | Description et circonstances de la modification
V 0 | | MUHAMMAD Asad | Brouillon : première version, modèle fourni.
V 1.0 | 05/02/2025 | MUHAMMAD Asad | Première rédaction du document.

## Grilles d'évaluations

## Avant-propos¹

Ce document de test a pour objectif de détailler les procédures et résultats associés aux tests réalisés sur le sous-système d’entrée de la table de mixage audio, développé dans le cadre du projet SAE. Il constitue un guide technique permettant de vérifier le bon fonctionnement du système, conformément aux spécifications établies dans le document de conception.

Ce rapport regroupe les différentes étapes de validation des modules, les critères de validation ainsi que les observations effectuées lors des tests. L’objectif est de garantir que les composants du sous-système respectent les exigences de performance et de fiabilité, en vue de leur intégration dans le projet global.

Dans un 1er lieu, le document présentera une synthèse des tests. Puis en deuxième partie tout la procédure de test et rapport de chaque test détaillé.

1 Référence : Gestion de projet, 50 outils pour agir ; F. Bouchaouir, Y. Dentinger, O. Englender ; Vuibert ;
2014. | Expression du besoin et cahier des charges fonctionnel ; J. Bernard-Bousières ; AFNOR ; 2012.

## Table des matières

## Table des Figures

Figure 1 Pinout module haute impédance | 10
Figure 2 Filtre : Signal entrée sortie à 20kHz | 10
Figure 3 Filtre : Signal entrée sortie à 44kHz | 11
Figure 4 Pinout module Gain | 12
Figure 5 Gain : Signal entrée sorti, gain 0 | 12
Figure 6 Gain : Signal entrée sorti, gain ~33 | 13
Figure 7 Pinout module Offset | 14
Figure 8 Offset : Signal entrée Offset 1.65V | 14

## Liste des Tableaux:

Tableau 1 Synthèse globale des tests | 6
Tableau 2 Synthèse des tests carte Mère | 9
Tableau 3 Cause et Solutions : dysfonctionnement Carte Mère | 9
Tableau 4 Synthèse des tests Module Suiveur + Filtre | 11
Tableau 5 Cause et Solutions : dysfonctionnement Module Suiveur + Filtre | 11
Tableau 6 Synthèse des tests Module Gain | 13
Tableau 7 Cause et Solutions : dysfonctionnement Module Gain | 13
Tableau 8 Synthèse des tests Module Offset | 15
Tableau 9 Cause et Solutions : dysfonctionnement Module Offset | 15
Tableau 10 Synthèse des tests sous-système analogique | 17
Tableau 11 Synthèse des tests Info : Entrée numérique MIDI | 18
Tableau 12 Cause et Solutions : dysfonctionnement Module Offset | 19

## I. Contexte du projet

### A. Situation et description

Le projet consiste à concevoir et réaliser une table de mixage audio automatique capable de traiter et de synchroniser plusieurs flux audios provenant d’instruments de musique. Ce dispositif sera intégré à l’Orchestrion, un système automatisé conçu pour reproduire les performances d’un orchestre en combinant différents instruments.

Développé dans le cadre de la SAE (Situation d’Apprentissage et d’Évaluation), ce projet sera présenté lors des Journées Portes Ouvertes de l’IUT de Cergy-Pontoise. Il met en avant la conception d’un dispositif électronique physique tout en respectant des contraintes écologiques et économiques.

### B. Besoins et objectifs

L’objectif principal de ce projet est de valoriser les enseignements du BUT GEII (Bachelor Universitaire de Technologie en Génie Électrique et Informatique Industrielle) à travers la création d’une unité de contrôle audio automatisée.

Ce mixeur audio doit permettre :

- Le traitement et la synchronisation de plusieurs sources sonores en temps réel.
- Une intégration optimisée au sein de l’Orchestrion, garantissant une interaction fluide avec les instruments automatisés.
- Une gestion efficace du signal audio tout en maintenant une faible consommation énergétique.

En plus des contraintes techniques, le projet répond également à des enjeux écologiques et économiques, en favorisant l’utilisation de composants optimisés et durables.

## II. Rappel des fonctions

- FT9 : Assurer la fiabilité et la maintenance
- FT9-0 : Concevoir un système modulaire avec des sous-systèmes indépendants (entrée audio, traitement, interface utilisateur, alimentation).
- FT9-1 : Garantir la sécurité électrique grâce à une protection contre les surtensions et courts-circuits sur les entrées Analogiques et Numériques.
- FT9-2 : Garantir la sécurité électrique grâce à une protection contre les surtensions et courts-circuits sur les Alimentations.
- FT2, FT3 : Gérer l’entrée audio analogique
- FT2-0 : Conditionner le signal analogique via pré amplification et filtrage.
- FT2-1 : Réguler le gain du signal d’entrée.
- FT2-2 : Appliquer un décalage (offset) sur le signal analogique AC.
- FT3 : Convertir le signal analogique en numérique (ADC) avec une résolution minimale de 12 à 16 bits et une fréquence d’échantillonnage de 44,1 kHz.
- FT1, FT6 : Gérer l’entrée audio numérique
- FT1-0 : Réceptionner les signaux MIDI.
- FT6 : Synchroniser les horloges MIDI avec le traitement audio interne.
- FT1-1 : Convertir les données MIDI en audio grâce à une synthèse numérique.
- FT5, FT6, FT7, FS1, FS2 : Assurer le traitement numérique du signal et produire un signal sonore
- FT5-0 : Appliquer des algorithmes de filtrage numérique (IIR/FIR) et de mixage pour ajuster les niveaux sonores et ajouter des effets.
- FT5-1 : Gérer le mixage audio en temps réel avec une allocation dynamique des canaux.
- FT7, FS1, FS2 : Fournir une IHM pour la gestion des paramètres de mixage et effets.
- FT6-0 : Restituer le signal audio
- FT6-1 : Fournir une sortie stéréo pour deux haut-parleurs intégrés ou une sortie ligne (non amplifiée).
- FT6-2 : Amplifier le signal audio
- Assurer l’amplification en tension et en courant du signal audio pour une restitution optimale.
- FT8 : Gérer l’alimentation électrique
- Assurer une alimentation via une batterie rechargeable.
- Permettre la recharge via un adaptateur secteur, une alimentation DC.
- FC6, FT9 : Garantir un format compact et une bonne ergonomie
- Concevoir un boîtier robuste et léger, en matériaux résistants aux chocs et adaptés aux manipulations fréquentes.
Optimiser les dimensions pour faciliter le transport et l’intégration dans un setup mobile.¹

1
Les Fonction barrées seront rédigées dans le document de fabrication de sous système

# Synthèse Globale des Tests

Tableau 1 Synthèse globale des tests

Sous-système | Modules Testés | Type de Test | Critères Validation de | Résultats | Actions Correctives
Carte Mère | FT9-0 & FT9-1 | Tests de fonctionnement | Bonne modularité et absence de court-circuit | Fonctionnel | Aucune
Entrée Audio Analogique | FT2-0 | Test de pré-amplification et filtrage | Amplification correcte, atténuation bruit | Fonctionnel | Aucune
| FT2-1 | Test de régulation du gain | Variation du gain conforme aux attentes | Fonctionnel | Aucune
| FT2-2 | Test de décalage (offset) | Offset réglable et stable | Fonctionnel | Aucune
| FT3-0 | Conversion analogique-numérique (ADC) | Résolution entre 12 et 24 bits, échantillonnage à 44,1 kHz | Non-disponible ou en cours | Aucune
Entrée Audio Numérique | FT1-0 | Test de réception MIDI | Réception des messages MIDI sans erreur | Fonctionnel | Aucune
| FT6 | Synchronisation horloge MIDI | | Non-disponible ou en cours | Aucune
| FT3 -1 | Programme Conversion Analogique Numerique | | Non-disponible ou en cours | Aucune

Au final, le système est [Fonctionnel / non-fonctionnel / fonctionne en mode dégradé / Non-disponible ou en cours].

## Le Système est : Fonctionne en mode dégradé

# Procédure et Synthèse détaillé des Tests

## III. Liste des équipements pour les tests

Matériel pour les tests :

- Oscilloscope : Mesure et visualisation des signaux analogiques et numériques.
- Multimètre : Mesure de tensions, courants et résistances.
- Alimentation : Sources de tension stabilisées (+12V, -12V, 5V, 3.3V).
- Générateur de fonctions (GBF) : Génération de signaux test (sinusoïdal, carré, triangulaire).
- Analyseur logique : Capture et analyse des signaux logiques.
- ESP32 : Simulation des instruments numériques.
- Pince brucelle : Manipulation précise de composants électroniques.
- Sondes d'oscilloscope : Connexion des circuits pour visualisation des signaux.
- Câbles pour les alimentations : Connexions entre les équipements de test et le circuit.

Matériel pour actions correctives :

- Plaque de prototypage (Plaque lab) : Montage rapide de circuits pour corrections.
- Pince à couper : Coupe précise des fils et composants.
- Cutter de précision : Ajustements fins et modifications de circuit.
- Fer à souder : Assemblage de composants électroniques.
- Etain : Matériau pour la soudure des connexions.
- Tresse à dessouder : Retrait de soudure pour corrections.
- Pompe à dessouder : Extraction de l'étain en excès.

## IV. Vérification Électrique générale

Cette vérification doit être réalisée sur tous les circuits de la table de mixage pour garantir leur bon fonctionnement avant l'assemblage final.

### A. Tests Visuelles

Procédure d’essai :

- Inspection visuelle détaillée de la carte mère sous lumière directe.
- Vérification des soudures des composants pour détecter toute anomalie (fissures, soudures froides, etc.).
- Vérification de la présence et de l'intégrité des connecteurs et composants montés sur la carte (résistances, condensateurs, CI, etc.).
- Vérification des marquages et des références des composants pour s'assurer qu'ils correspondent aux spécifications du circuit.

Critères de validation :

- Aucune soudure défectueuse.
- Connecteurs et composants en bon état et correctement positionnés.

### B. Tests de Continuité et courtes circuits

Procédure d’essai :

- Utiliser un multimètre en mode test de continuité pour vérifier que toutes les liaisons électriques entre les différents composants sont intactes.
- Tester les points d'alimentation pour vérifier qu'il n'y a pas de court-circuit entre les rails d'alimentation (GND, +12V, -12V, 5V et 3.3V).
- Vérifier qu'il n'y a pas de connexions inattendues entre les différentes pistes ou composants.

Critères de validation :

- Aucune continuité n’est détectée sur les pistes qui ne devraient pas être connectées.
- Aucune présence de court-circuit entre les différents rails d'alimentation.

### A. Tests Alimentation

Vérifier les tensions aux différents points de mesure sur la carte (points de test : -12V, +12V, 5V, 3.3V).

## V. Carte Mère : Système modulaire (FT9-0 & FT9-1)

La carte mère sert de base pour interconnecter les différents modules du mixeur audio et fournir les connecteurs d'entrée pour les signaux. Elle assure la liaison entre les modules tout en garantissant la protection contre les surtensions et courts-circuits.

### A. Tests fonctionnement

Procédure d’essai :

- Simuler des signaux analogiques de 1Vpp sur les connecteurs analogiques et des signaux numériques de 0-3.3V sur les connecteurs d'entrée numériques.
- Vérifier les signaux aux points clés du circuit pour s'assurer que les modules interagissent correctement (les entrées et sorties des connecteurs sont bien connectées entre elles).
- Augmenter la tension du signal analogique jusqu'à 4Vpp en entrée, puis tester les sorties des protections pour vérifier que la tension en sortie ne dépasse pas 3.3V.

Critères de validation :

- Les signaux doivent être conformes aux attentes à chaque point de test.
- Aucun dysfonctionnement ne doit être détecté dans l’interaction entre les modules et la carte mère.

Tableau 2 Synthèse des tests carte Mère

Type de Test | Précision | Etat
Structurelle | Vérification Électrique générale | Non-disponible ou en cours
Fonctionnel | Test réception des signaux d’entrées | Non-disponible ou en cours
Fonctionnel | Test Protection électriques | Non-disponible ou en cours
Au final, le circuit est [Fonctionnel / Non-fonctionnel / Fonctionne en mode dégradé / Non-disponible ou en cours].

### Le Système est : Non-disponible ou en cours = Non-fonctionnel

Tableau 3 Cause et Solutions : dysfonctionnement Carte Mère

Cause racine d'un dysfonctionnement | Solution corrective à un dysfonctionnement
Une cause fréquente de dysfonctionnement sur la carte mère peut être l'absence de via pour relier les pistes d'un côté de la carte à l'autre. | Souder un fil à la place des vias manquants pour établir correctement la connexion entre les pistes.

## VI. Module : Entrée haute impédance et filtrage (FT2-0)

Le module Entrée haute impédance et filtrage est conçu pour fournir une entrée à haute impédance tout en filtrant ou atténuant les fréquences indésirables ou parasites.

### A. Tests fonctionnement

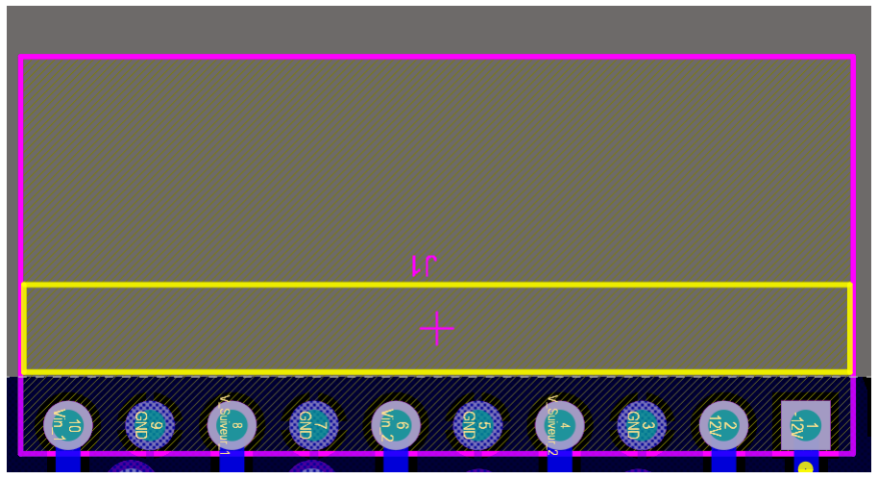
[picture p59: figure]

Figure 1 Pinout module haute impédance

Alimentation et Configuration de Test :

Sur une plaque lab alimenter la carte en +12V, -12V et GND sur les pins correspondants.

Procédure de Test :

- Appliquer un signal de 1Vpp avec une fréquence de 1 kHz sur l'entrée Vin_1 à l'aide d'un Générateur de Basse Fréquence (GBF).
- Mesurer le signal à la sortie avec un oscilloscope. Le signal de sortie doit être identique au signal d'entrée, avec un léger déphasage.
- Varier la fréquence jusqu'à 20 kHz. L'atténuation doit être de -1 dB.

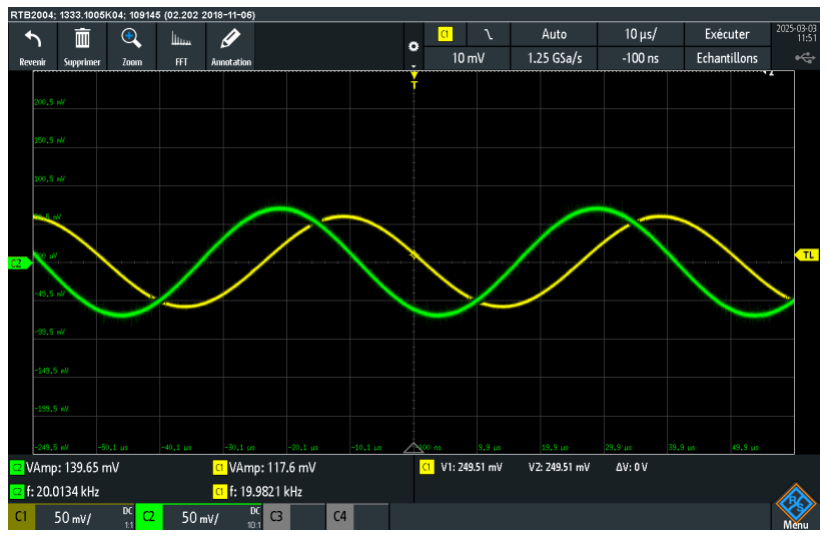
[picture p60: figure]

Figure 2 Filtre : Signal entrée sortie à 20kHz

- Augmenter la fréquence jusqu'à 44 kHz. L'atténuation doit être supérieure ou égale à -6 dB.

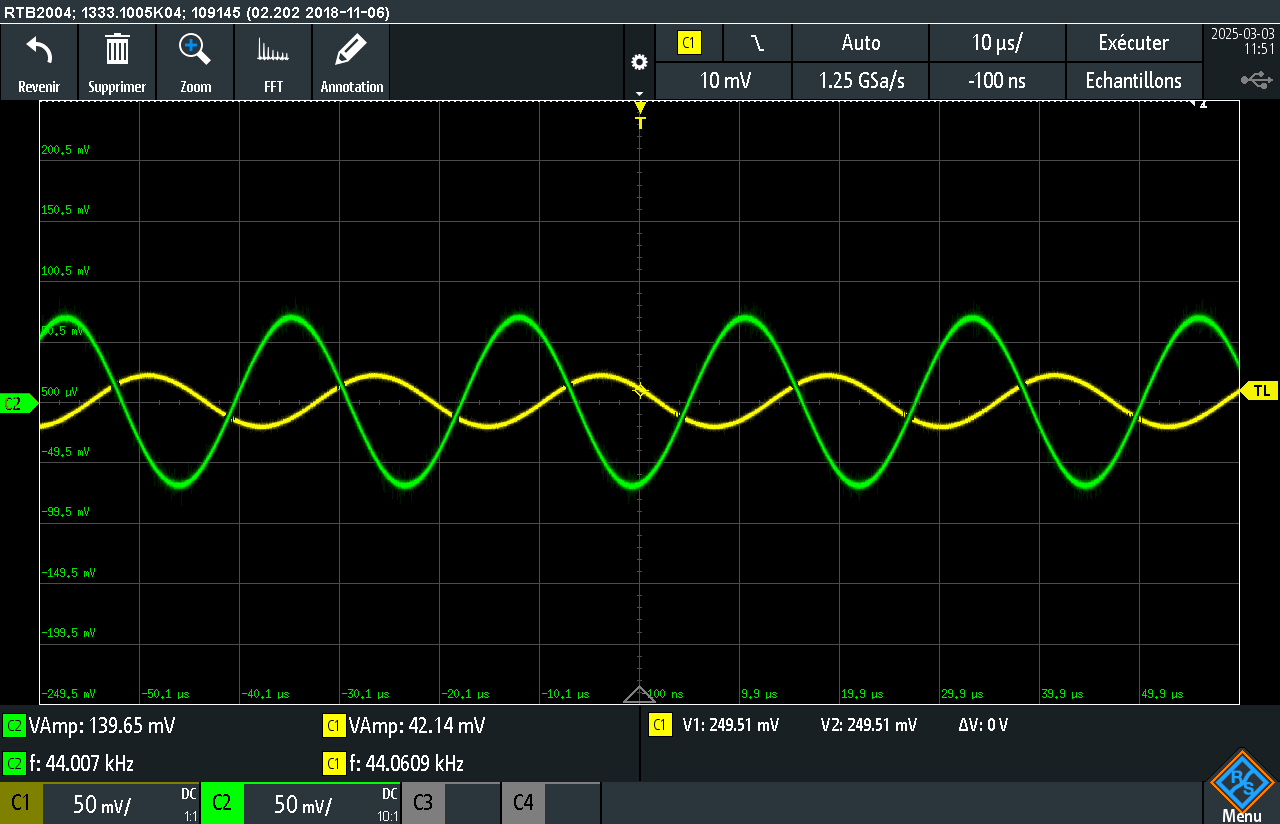
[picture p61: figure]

Figure 3 Filtre : Signal entrée sortie à 44kHz

Répétez la même procédure avec voie 2.

Tableau 4 Synthèse des tests Module Suiveur + Filtre

Type de Test | Précision | Etat
Structurelle | Vérification Electrique générale : | Fonctionnel
Fonctionnel | Test avec fréquence 20kHz, petite atténuation (-1dB) | Fonctionnel
Fonctionnel | Test avec fréquence 44kHz, petite attenuation (-6dB) | Fonctionnel

Au final, le circuit est [Fonctionnel / Non-fonctionnel / Fonctionne en mode dégradé / Non-disponible ou en cours].

### Le Système est : Fonctionnel

Tableau 5 Cause et Solutions : dysfonctionnement Module Suiveur + Filtre

Cause racine d'un dysfonctionnement | Solution corrective à un dysfonctionnement
AOP défectueux affectant la gestion du signal et la réponse en fréquence | Remplacer l'AOP défectueux par un nouveau composant fonctionnel. Tester à nouveau le module pour vérifier la performance du signal.

## VII. Module : Régulation du gain (FT2-1)

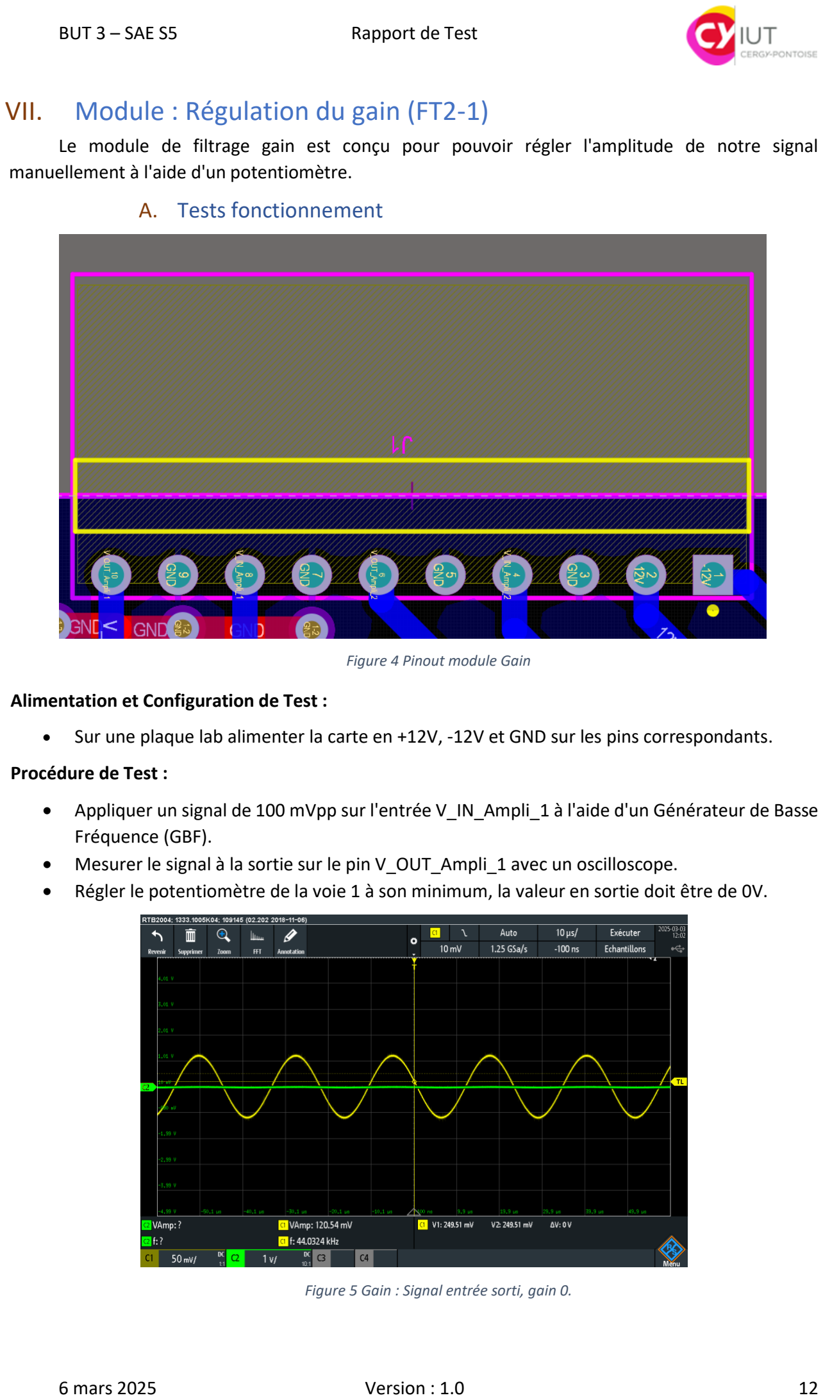
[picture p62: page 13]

Le module de filtrage gain est conçu pour pouvoir régler l'amplitude de notre signal manuellement à l'aide d'un potentiomètre.

### A. Tests fonctionnement

Figure 4 Pinout module Gain

Alimentation et Configuration de Test :

- Sur une plaque lab alimenter la carte en +12V, -12V et GND sur les pins correspondants.

Procédure de Test :

- Appliquer un signal de 100 mVpp sur l'entrée V_IN_Ampli_1 à l'aide d'un Générateur de Basse Fréquence (GBF).
- Mesurer le signal à la sortie sur le pin V_OUT_Ampli_1 avec un oscilloscope.
- Régler le potentiomètre de la voie 1 à son minimum, la valeur en sortie doit être de 0V.

Figure 5 Gain : Signal entrée sorti, gain 0.

- Tourner progressivement le potentiomètre pour faire varier le gain et suivre l'amplitude du signal sur l'oscilloscope.
- Lorsque le potentiomètre est réglé à son maximum, l'amplitude en sortie doit être de 3.3Vpp, ce qui correspond à un gain d’environs 33.

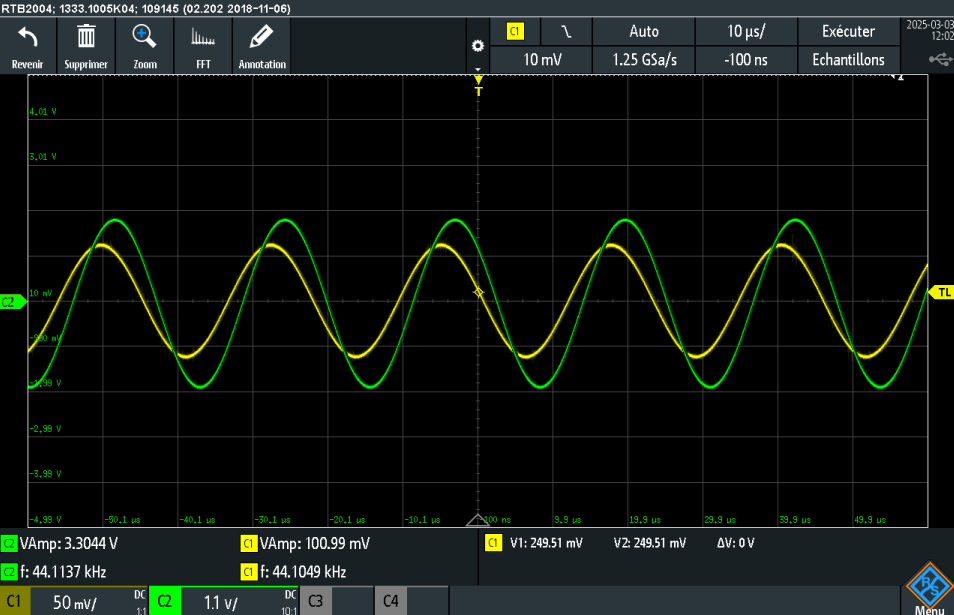
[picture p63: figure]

Figure 6 Gain : Signal entrée sorti, gain ~33

Répéter la même procédure pour la voie 2.

Tableau 6 Synthèse des tests Module Gain

Type de Test | Précision | Etat
Structurelle | Vérification Electrique générale : | Fonctionnel
Fonctionnel | Gain minimum de 0 | Fonctionnel
Fonctionnel | Gain maximum de 33 | Fonctionnel
Au final, le circuit est [Fonctionnel / Non-fonctionnel / Fonctionne en mode dégradé / Non-disponible ou en cours].

### Le Système est : Fonctionnel

Tableau 7 Cause et Solutions : dysfonctionnement Module Gain

Cause racine d'un dysfonctionnement | Solution corrective à un dysfonctionnement
AOP défectueux affectant la gestion du signal et la réponse en fréquence | Remplacer l'AOP défectueux par un nouveau composant fonctionnel. Tester à nouveau le module pour vérifier la performance du signal.
Potentiomètres dysfonctionnels ou mal branchés | Vérifier les connexions des potentiomètres et les tester. Si nécessaire, remplacer les potentiomètres défectueux.

## VIII. Module : Offset et protection surtension (FT2-1)

Le module d’offset et de protection surtension permet d’ajouter un offset au signal et de limiter la tension maximale de sortie à 3.3V.

### A. Tests fonctionnement

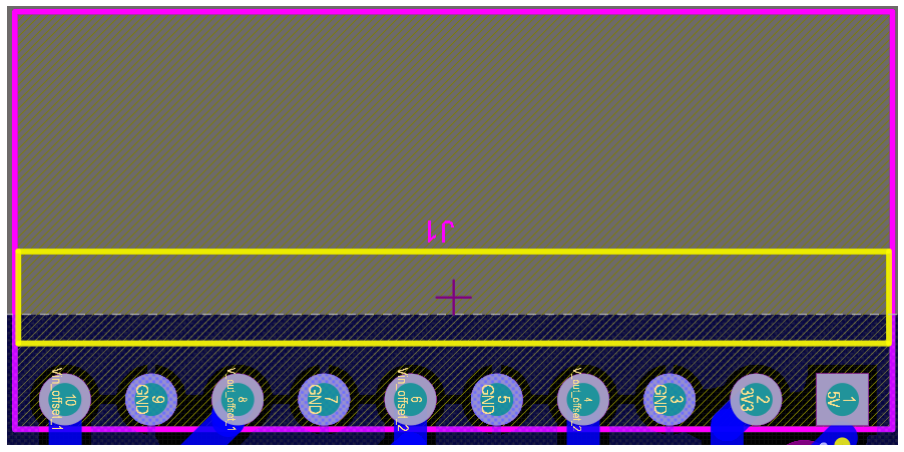
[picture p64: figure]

Figure 7 Pinout module Offset

Alimentation et Configuration de Test :

- Sur une plaque lab, alimenter la carte en +5V, +3.3V et GND sur les pins correspondants.

Procédure de Test :

- Appliquer un signal de 100 mVpp sur l'entrée Vin_offset_1 à l'aide d'un Générateur de Basse Fréquence (GBF).
- Mesurer le signal à la sortie sur le pin Vout_offset_1 avec un oscilloscope.
- Le signal doit être centré sur 1.65V. Si nécessaire, ajuster le potentiomètre pour atteindre 1.65V.
- Faire varier le signal d’entrée jusqu’à 4Vpp. En sortie, la tension doit être clampée entre 0V et 3.3V.

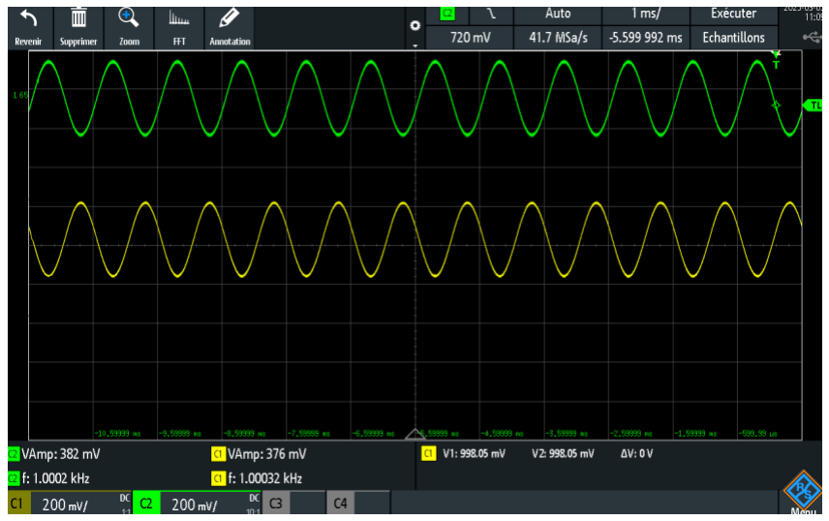
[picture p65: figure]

Figure 8 Offset : Signal entrée Offset 1.65V.

Répéter la même procédure pour la voie 2.

Tableau 8 Synthèse des tests Module Offset

Type de Test | Précision | Etat
Structurelle | Vérification Electrique générale : | Fonctionnel
Fonctionnel | Signal centré sur 1.65V | Fonctionnel
Fonctionnel | Signal d'entrée varié jusqu'à 4Vpp, tension clampée entre 0V et 3.3V | Fonctionnel

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

### Le Système est : Fonctionnel

Tableau 9 Cause et Solutions : dysfonctionnement Module Offset

Cause racine d'un dysfonctionnement | Solution corrective à un dysfonctionnement
AOP défectueux affectant la gestion du signal et la réponse en fréquence | Remplacer l'AOP défectueux par un nouveau composant fonctionnel. Tester à nouveau le module pour vérifier la performance du signal.
Régulateur de tension ou montage diviseur de tension dysfonctionnels ou mal branchés | Vérifier les connexions des régulateurs de tension ou du diviseur de tension. Si nécessaire, remplacer les composants défectueux.

## IX. Module : Conversion analogique-numérique (FT3)

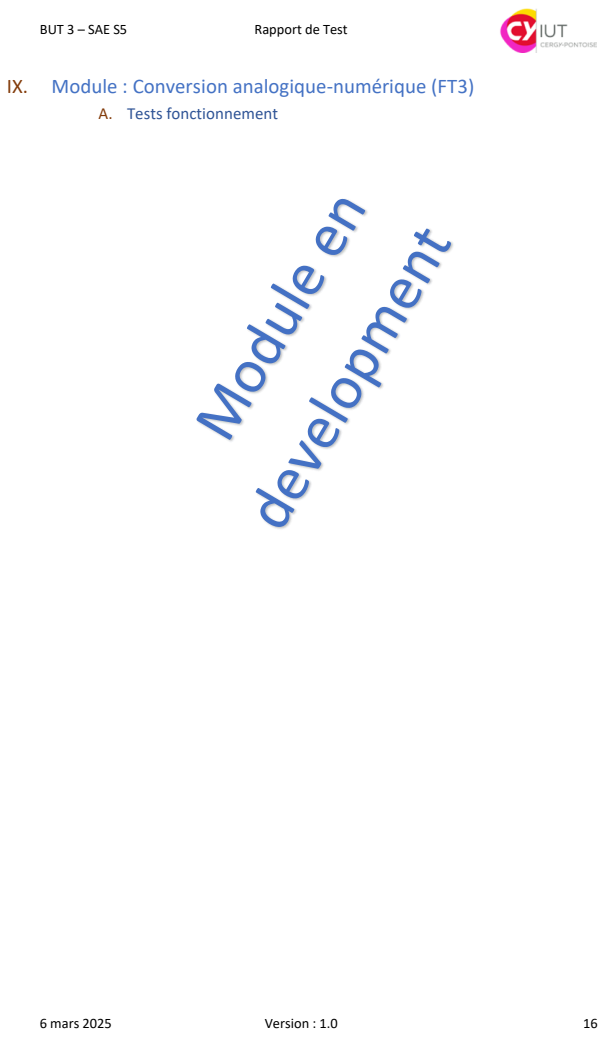
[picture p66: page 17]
A. Tests fonctionnement

## X. Sous-système d’entrée analogique, Complet

### A. Tests fonctionnement

Procédure d’essai :

- Alimentation des modules : Vérifier que tous les modules sont alimentés avec les bonnes tensions (+12V, -12V, 5V, 3.3V, GND).
- Appliquer un signal d'entrée de 100 mVpp à 2 kHz sur l'entrée du module Suiveur.
- Connecter la sortie du module Suiveur à l'entrée du module Gain.
- Régler le gain du module Gain au maximum (le gain doit être d’environ 33).
- Connecter la sortie du module Gain à l'entrée du module Offset.
- Vérifier les caractéristiques du signal en sortie du module Offset.
- Faites varier la fréquence jusqu’à que f > 44kHz. En sortie le signal doit être atténué.

Critères de validation pour le module Offset :

- Amplitude de 3.3 Vpp.
- Signal positif, centré autour de 1.65V (avec offset).
- Tension clampée entre 0V et 3.3V lorsque le signal d'entrée varie jusqu’à 4Vpp.

Tableau 10 Synthèse des tests sous-système analogique

Type de Test | Précision | Etat
Structurelle | Vérification Electrique générale : | Fonctionnel
Fonctionnel | Amplitude 3.3V | Fonctionnel
Fonctionnel | Signal positif centré sur 1.65V | Fonctionnel
Fonctionnel | Tension clampée entre 0V et 3.3V | Fonctionnel
Fonctionnel | Atténuation du signal à f > 20kHz | Fonctionnel
Fonctionnel | Module ADC | Non-disponible ou en cours
- Au final, le circuit est [Fonctionnel / Non-fonctionnel / Fonctionne en mode dégradé / Non-disponible ou en cours].

### - Le Système est : Fonctionnel en mode dégradé

## XI. Gestion de l’entrée audio numérique MIDI (FT1, FT6)

### A. Procédure d’essai

1. Vérification de l'activation des UARTs
- Allumer la Raspberry Pi.
- Brancher un clavier et une souris.
- Ouvrir un terminal et entrer les commandes suivantes :
raspi-gpio get | grep -i "TX"
raspi-gpio get | grep -i "RX"
- Analyser la sortie pour vérifier si les UARTs requis sont activés.


2. Vérification de la réception des données MIDI Deux méthodes sont disponibles :
- Bouclage TX/RX : Brancher le TX d'un UART sur le RX du même UART, envoyer des données sur TX et vérifier leur réception sur RX.
- Simulation d'un instrument MIDI avec ESP32 (Méthode retenue) :
- Utiliser une carte ESP32 ou toute carte compatible Arduino avec un niveau logique de 3.3V et un UART.
- Brancher le TX de l'ESP32 sur le RX de la Raspberry Pi sur le port désiré.
- Télécharger le programme ESP32MIDI disponible sur GitHub (sera prochainement publié sur GitLab) :
- | o | https://github.com/A-s-a-d/MIDI_and_audio_Keypad
- Flasher le programme sur l'ESP32 et le démarrer.
- Lancer le programme de réception des données sur l'UART de la Raspberry Pi en utilisant le même port que l'ESP32.
- Vérifier la réception des données envoyées depuis l'ESP32 en utilisant un logiciel de terminal série (Tera Term, Putty ou Screen).

Tableau 11 Synthèse des tests Info : Entrée numérique MIDI

Type de Test | Précision | Etat
Fonctionnel | Activation des UARTs et vérification des signaux TX/RX | Fonctionnel
Fonctionnel | Transmission et réception des données MIDI via ESP32 | Fonctionnel
Fonctionnel | Intégration et communication avec logiciel de test | Non-disponible ou en cours

- Au final, le système est [Fonctionnel / Non-fonctionnel/ Fonctionne en mode dégradé / Non-disponible ou en cours].

### - Le Système est : Fonctionnel en mode dégradé

Tableau 12 Cause et Solutions : dysfonctionnement Module Offset

Cause racine d'un dysfonctionnement | Solution corrective à un dysfonctionnement
Problème de communication sur UART1 | UART0 est activé, modifier le fichier /boot/firmware/config.txt et désactiver UART0 si nécessaire
Données corrompues | Vérifier la configuration de la vitesse de transmission (baud rate)
Aucun signal MIDI reçu | Utiliser un logiciel de surveillance série pour diagnostiquer

## XII. Gestion de l’ADC

B. Tests fonctionnement

A. Tests activation des SPI

Vérification de la communication SPI
Test de l’initialisation des périphériques ADC

Vérification des conversions analogique-numérique
Validation de l’acquisition des signaux

## XIII. Sous-système Raspberry Pi 4, Complet

A. Tests fonctionnement

Validation de l’exécution des programmes
Vérification de la communication avec les autres modules

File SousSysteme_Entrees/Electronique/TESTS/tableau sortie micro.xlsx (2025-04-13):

fre | Vppmicro mV
100 | 2.5
200 | 4
300 | 5.5
400 | 8
500 | 9.5
1000 | 11
2000 | 26
3000 | 40
4000 | 77
5000 | 230
6000 | 55
7000 | 20
8000 | 14.5
10000 | 17

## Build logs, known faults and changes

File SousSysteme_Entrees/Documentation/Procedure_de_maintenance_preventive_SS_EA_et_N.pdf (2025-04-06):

BUT 3 – SAE S5

CY IUT – GEII Neuville

# Procédure de maintenance préventive

## Projet tutoré Mixeur Sous-système Entrées

## Document rédigé par : MUHAMMAD Asad Version : 1.0 [6 avril 2025]

BUT 3 – SAE S5 | Procédure de maintenance préventive

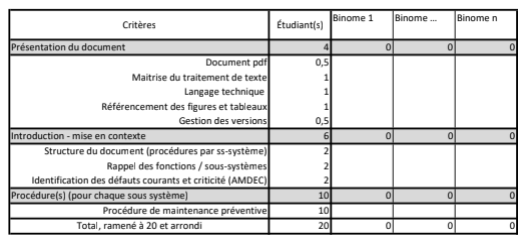
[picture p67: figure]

6 avril 2025 | Version : 1.0 | 1

## Historique des modifications et révisions de ce document :

N° de version | Date | Auteur | Description et circonstances de la modification
V 0 | | MUHAMMAD Asad | Brouillon : première version, modèle fourni.
V 1.0 | 05/04/2025 | MUHAMMAD Asad & Volodymyr Vronskyi | Première rédaction complète du document.

## Grilles d'évaluations

## Avant-propos¹

"Ce document décrit les procédures de maintenance préventive pour le sous-système 'Entrées' de la table de mixage audio développée dans le cadre du projet tutoré. Il vise à garantir la fiabilité, la sécurité et la longévité des composants électroniques critiques, tels que les circuits de protection contre les surtensions, les filtres audio, les convertisseurs analogique-numérique (ADC), et les interfaces MIDI.

L’approche adoptée s’appuie sur l’analyse AMDEC (Analyse des Modes de Défaillance, de leurs Effets et de leur Criticité), identifiant les points sensibles comme les entrées analogiques (risque de surtensions) ou les connecteurs MIDI (usure mécanique). Les procédures détaillées incluent des checklists, des fréquences d’intervention recommandées, et des outils spécifiques (multimètre, oscilloscope, logiciels de diagnostic).

1 Référence : Gestion de projet, 50 outils pour agir ; F. Bouchaouir, Y. Dentinger, O. Englender ; Vuibert ;
2014. | Expression du besoin et cahier des charges fonctionnel ; J. Bernard-Bousières ; AFNOR ; 2012.

## Table des matières

A. Contexte : Rappel des objectifs du projet et des sous-systèmes concernés (entrées
C. Besoins et Objectifs de la maintenance : Prévenir les pannes, optimiser la durée de vie,
A. Calendrier : Tableau synthétique (ex : "Mensuel : vérification des protections ; Annuel :

## I. Introduction

### A. Contexte : Rappel des objectifs du projet et des sous-systèmes

concernés (entrées analogiques/numériques).

Le projet s’inscrit dans le cadre du module de SAE (Situation d’Apprentissage et d’Évaluation) du BUT GEII, dont l’objectif est de concevoir une table de mixage audio autonome, capable d’interfacer à la fois des sources analogiques (microphones, instruments) et numériques (interfaces MIDI), de traiter ces signaux en temps réel, puis de les restituer de manière fidèle et performante.

La structure globale du système repose sur une architecture modulaire divisée en plusieurs sous-systèmes indépendants, chacun étant dédié à une fonction critique :

- Sous-système Entrées analogiques : assure la prise de son, le conditionnement du signal, le filtrage, le gain et la conversion ADC.
- Sous-système Entrées numériques (MIDI) : réceptionne les données MIDI, les synchronise et les convertit en données audio exploitables.
- Sous-système Traitement : applique les algorithmes de mixage, d’effets et de filtrage numérique.
- Sous-système Alimentation : assure la gestion d’énergie, incluant batterie et alimentation externe.
- Sous-système IHM / Interface utilisateur : permet l’interaction avec les différents paramètres du mixeur (gain, effets,).
- Sous-système Sorties audio : amplification et restitution du signal traité (casques, haut-parleurs, sortie ligne).

L’ensemble est conçu pour être compact, fiable et facilement maintenable, notamment grâce à l’adoption de standards ouverts, de connecteurs modulaires, et d’un boîtier résistant.

### B. Rappel des fonctions

- FT9 : Assurer la fiabilité et la maintenance
- FT9-0 : Concevoir un système modulaire avec des sous-systèmes indépendants (entrée audio, traitement, interface utilisateur, alimentation).
- FT9-1 : Garantir la sécurité électrique grâce à une protection contre les surtensions et courts-circuits sur les entrées Analogiques et Numériques.
- FT9-2 : Garantir la sécurité électrique grâce à une protection contre les surtensions et courts-circuits sur les Alimentations.
- FT2, FT3 : Gérer l’entrée audio analogique
- FT2-0 : Conditionner le signal analogique via entrée haute impudence et filtrage.
- FT2-1 : Réguler le gain du signal d’entrée.
- FT2-2 : Appliquer un décalage (offset) sur le signal analogique AC.
- FT3 : Convertir le signal analogique en numérique (ADC) avec une résolution minimale de 12 à 16 bits et une fréquence d’échantillonnage de 44,1 kHz.
- FT1, FT6 : Gérer l’entrée audio numérique
- FT1-0 : Réceptionner les signaux MIDI.
- FT6 : Synchroniser les horloges MIDI avec le traitement audio interne.
- FT1-1 : Convertir les données MIDI en audio grâce à une synthèse numérique.
- FT5, FT6, FT7, FS1, FS2 : Assurer le traitement numérique du signal et produire un signal sonore
- FT5-0 : Appliquer des algorithmes de filtrage numérique (IIR/FIR) et de mixage pour ajuster les niveaux sonores et ajouter des effets.
- FT5-1 : Gérer le mixage audio en temps réel avec une allocation dynamique des canaux.
- FT7, FS1, FS2 : Fournir une IHM pour la gestion des paramètres de mixage et effets.
- FT6-0 : Restituer le signal audio
- FT6-1 : Fournir une sortie stéréo pour deux haut-parleurs intégrés ou une sortie ligne (non amplifiée).
- FT6-2 : Amplifier le signal audio
- Assurer l’amplification en tension et en courant du signal audio pour une restitution optimale.
- FT8 : Gérer l’alimentation électrique
- Assurer une alimentation via une batterie rechargeable.
- Permettre la recharge via un adaptateur secteur, une alimentation DC.
- FC6, FT9 : Garantir un format compact et une bonne ergonomie
- Concevoir un boîtier robuste et léger, en matériaux résistants aux chocs et adaptés aux manipulations fréquentes.
- Optimiser les dimensions pour faciliter le transport et l’intégration dans un setup mobile.¹

1
Les Fonction barrées seront rédigées dans les documents de sous-système correspondants

C. Besoins et Objectifs de la maintenance : Prévenir les pannes, optimiser la durée de vie, respecter les normes de sécurité.

Besoins de la maintenance :

1. Prévenir les pannes :
- Identifier et corriger les problèmes potentiels avant qu’ils n’entraînent une panne imprévue.
- Mettre en place des interventions régulières pour assurer le bon fonctionnement de l’équipement.
- Minimiser les risques de défaillances en remplaçant les pièces susceptibles de s'user avant qu'elles ne causent un dysfonctionnement majeur.
2. Optimiser la durée de vie des équipements :
- Effectuer des contrôles réguliers pour garantir la longévité des composants clés (cartes électroniques…).
- Assurer un entretien adéquat pour éviter l’usure prématurée des pièces sensibles.
- Appliquer des techniques de maintenance qui prolongent la durée de vie utile de l’équipement en maintenant des performances optimales.
3. Respecter les normes de sécurité :
- Veiller à ce que l'équipement fonctionne selon les normes de sécurité en vigueur, garantissant la sécurité du personnel et de l'environnement.
- Assurer que toutes les vérifications de sécurité (protection contre les courts-circuits, les surchauffes, etc.) sont réalisées lors de chaque intervention.
- Vérifier la conformité des équipements aux certifications de sécurité, et appliquer les mesures de prévention nécessaires (mise à jour des protocoles de sécurité, ajustement des dispositifs de sécurité, etc.).

D. Méthodologie : Référence à l’AMDEC et aux critères de criticité.

L’Analyse des Modes de Défaillance, de leurs Effets et de leur Criticité (AMDEC) est une méthode structurée et proactive d’évaluation des risques, visant à identifier, classer et maîtriser les défaillances potentielles d’un système. Utilisée dans les domaines industriels, électroniques et mécaniques, elle permet d’anticiper les pannes avant leur apparition et d’optimiser la fiabilité du produit.

Dans le cadre du projet Table de Mixage, cette analyse est essentielle pour garantir la robustesse de l’appareil, notamment en vue de son utilisation intensive lors des Journées Portes Ouvertes (JPO).

L’AMDEC repose sur trois étapes clés :

Identification des Modes de Défaillance :

- Pour chaque composant critique (ex. AOP, Raspberry Pi 4B, ADC), nous listons les pannes possibles (surchauffe, court-circuit, usure mécanique, etc.).

Analyse des Effets et Causes :

- Pour chaque défaillance, nous évaluons :
- L’effet sur le système (ex. arrêt complet, dégradation des performances).
- La cause racine (ex. courant excessif, mauvaise dissipation thermique).

Évaluation de la Criticité :

- Chaque défaillance est notée selon trois critères (sur une échelle de 1 à 5) :
- Gravité (G) : Impact sur le système.
- Occurrence (O) : Probabilité que la défaillance se produise.
- Détectabilité (D) : Facilité à détecter la panne avant qu’elle n’impacte le système.
- La Criticité (C) est calculée par : C = G × O × D.
- Exemple : Une défaillance avec G=5, O=4, D=1 aura une criticité de 20/25 (risque critique).

Pourquoi l’AMDEC est Cruciale pour le Table de Mixage ?

- Enjeu de Fiabilité : Le système doit fonctionner sans interruption pendant les JPO.
- Optimisation des Coûts : Identifier les faiblesses en amont évite des réparations coûteuses.
- Sécurité : Prévenir les risques électriques (surchauffe, courts-circuits) et mécaniques (connecteurs abimées).
- Amélioration Continue : L’AMDEC sert de base pour les futures itérations du projet.

## I. Raspberry Pi : Gestion de entrées

Composant | Mode de défaillance | Effet | Cause | Criticité (G/O/D) | Action Préventive
Raspberry Pi | Surchauffe | Throttling / Arrêt temporaire du système | Ventilation insuffisante, Poussier | 3/3/2 Moyenne | Nettoyage / Permettre un meilleur flux d’air.

## II. Procédures sous-système Analogique

### A. Carte Mère (FT9-0, FT9-1, FT2, FT3, FT1, FT6)

Composant | Mode de défaillance | Effet | Cause | Criticité (G/O/D) | Action Préventive
Connecteurs entrées et Carte à Carte | Mauvais contact | Intermittence des données et d’alimentation | Oxydation / vibration / | 3/2/4 Faible | Utiliser des connecteurs sertis Nettoyage périodique
Carte mère non fixée | Mauvaise connexion avec autres modules | Mauvais fonctionnement général, défaillance de communication entre modules | Carte mère non fixée correctement | 3/2/4 | Fixer correctement la carte mère avec vis, vérifier les connexions
Diodes Zeners / TVS | Court-circuit / fuite | Endommagement composant suivant / surtension | Tension d’entrée trop élevée ou décharge statique | 4/1/5 Moyenne | Remplaceme nt périodique, Vérification visuelle

### B. Module Filtrage (FT2-0)

Composant | Mode de défaillance | Effet | Cause | Criticité (G/O/D) | Action Préventive
Connecteurs entrées et Carte à Carte | Mauvais contact | Intermittence des données et d’alimentation | Oxydation / vibration / | 3/2/4 Faible | Utiliser des connecteurs sertis Nettoyage périodique
Resistance et condensateurs | Valeur incorrecte | Mauvais Filtrage | Variation de valeur des résistances ou des condensateurs a cause de chaleur ou d’autres facteurs | 3/1/5 Moyenne | Inspection annuelle, remplacemen t si nécessaire

### C. Module Gain (FT2-1)

Composant | Mode de défaillan ce | Effet | Cause | Criticité (G/O/D) | Action Préventive
Connecteurs entrées et Carte à Carte | Mauvais contact | Intermittence des données et d’alimentation | Oxydation / vibration / | 3/2/4 Faible | Utiliser des connecteurs sertis Nettoyage périodique
Potentiomètres | Usure / oxydatio n | Mauvais réglage de gain | Oxydation, Vieillissement / usage mécanique intensif | 2/3/3 Faible | Nettoyage avec produit anti oxydant, remplacemen t des potentiomètr es

### D. Module Offset (FT2-2)

Composant | Mode de défaillan ce | Effet | Cause | Criticité (G/O/D) | Action Préventive
Connecteurs entrées et Carte à Carte | Mauvais contact | Intermittence des données et d’alimentation | Oxydation / vibration / | 3/2/4 Faible | Utiliser des connecteurs sertis Nettoyage périodique
Potentiomètres, régulateurs de Tension, Résistances | Dérive de valeur | Mauvais Offset de quelques mV par rapport à 1.65V | Vieillissement thermique / instabilité composants | 2/1/3 Faible | Calibration régulière de potentiomètr e pour avoir un Offset de 1.65V soit 825mV en entrée d’AOP de Montage différentiel.

### E. Module Convertisseur ADC (FT3)

Composant | Mode de défaillan ce | Effet | Cause | Criticité (G/O/D) | Action Préventive
Connecteurs entrées et Carte à Carte | Mauvais contact | Intermittence des données et d’alimentation | Oxydation / vibration / | 3/2/4 Faible | Utiliser des connecteurs sertis Nettoyage périodique
Potentiomètres, régulateurs de Tension, Résistances | Référenc e erronée | Mauvais Valeur en Sortie de montage référence de tension | Dérive thermique / composants vieillissants | 2/1/3 Faible | Calibration en réglant le potentiomètr e pour avoir une référence de 3.3V.
Horloge externe | Signal incorrect | Erreurs d’échantillonnage et communication SPI | Mauvais réglage de fréquence / Rapport cyclique instable | 4/2/4 Moyenne | Ajuster la Frequence et rapport cyclique dans le programme raspberry Pi, soit en mode CLK, soit PWM.

## III.Procédures sous-système Numérique

### A. Module MIDI (FT1)

Composant | Mode de défaillance | Effet | Cause | Criticité (G/O/D) | Action Préventive
Connecteurs entrées et Carte à Carte | Mauvais contact | Intermittence des données et d’alimentation | Oxydation / vibration / | 3/2/4 Faible | Utiliser des connecteurs sertis Nettoyage périodique
Optocoupleur MIDI | Défaillance de l’isolation | Signal MIDI non reconnu ou bruité | Vieillissement, surtension, décharge électrostatique | 4/1/4 | Tester le bon fonctionneme nt en injectant un signal MIDI connu, remplacemen t périodique

## IV.Planification et outils

### A. Calendrier : Tableau synthétique (ex : "Mensuel : vérification des

protections ; Annuel : calibration ADC").

Fréquence | Action
Hebdomadaire | Vérification visuelle des connexions, test de démarrage
Mensuel | Nettoyage des connecteurs et de la ventilation ; vérif. valeurs offsets
Trimestriel | Calibration des potentiomètres (offset, gain, tension de ref)
Semestriel | Test de stabilité thermique ; validation échantillonnage
Annuel | Vérification complète des composants passifs ; recalibrage général
B. Outils requis : Liste commentée (multimètre,).
- Multimètre numérique : Pour vérifier les tensions d'alimentation, les offsets et la continuité.
- Oscilloscope : Observation des signaux d’entrée, vérification des horloges (échantillonnage).
- Générateur de fonctions : Pour tester les réponses analogiques des modules filtrage/gain.
- Spray nettoyant pour contacts électroniques : Pour les potentiomètres et connecteurs.
- Tournevis de précision : Pour ajustement fin des potentiomètres.
- Station de soudure : Pour remplacement de composants défaillants.

C. Fiches d’intervention : Modèles prêts à remplir (date, technicien, observations).

Fiche d'Intervention - Maintenance Préventive

Équipement concerné : [ | ]
Technicien : [ | ]
Date de l'intervention : [ | ]

Type d’intervention : Maintenance préventive

1. Check-list d'Intervention
1. Vérification des composants
☐ Vérification de l’alimentation électrique (tension, connexions, etc.) ☐ Vérification des câbles et des connecteurs
☐ Vérification du système de ventilation (poussières, filtres)
☐ Vérification de l’état des cartes électroniques
☐ Test de la communication (SPI, UART.)
2. Maintenance préventive physique
☐ Nettoyage des composants (carte, connecteurs, dissipateurs) ☐ Vérification de l'état des vis et fixations
☐ Remplacement des pièces usées ou endommagées
☐ Vérification de l’alignement des composants
3. Test de fonctionnement
☐ Test de démarrage de l'équipement
☐ Test de la stabilité du système
☐ Vérification de la réponse des entrées/sorties
4. Réglages
☐ Réajustement des paramètres de configuration (CLK SPI)
5. Observations et Remarques
☐ Anomalies détectées : [ |
| ]
☐ Pièces remplacées : [ | ]
☐ Problèmes résolus : [ | ]
☐ Recommandations pour la prochaine intervention : [ |
| ]

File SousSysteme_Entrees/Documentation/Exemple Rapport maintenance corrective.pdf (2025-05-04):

BUT 3 – SAE S5

CY IUT – GEII Neuville

# Rapport de maintenance corrective

## Projet tutoré Mixeur Sous-système Entrées

## Document rédigé par : Asad Muhammad [4 mai 2025]

BUT 3 – SAE S5 | Rapport de maintenance corrective
4 mai 2025 | Version : 1.0 | 1

## Table des matières

## I. Introduction

### A. Contexte

Le projet consiste à concevoir une table de mixage audio modulaire capable d’interfacer des entrées analogiques et numériques (MIDI), et de traiter les signaux en temps réel. Chaque sous-système est conçu pour être facilement remplaçable ou réparable en cas de défaillance.

### B. Objectifs de la maintenance corrective

- Restaurer rapidement le fonctionnement normal après une panne.
- Minimiser le temps d'arrêt du système.
- Limiter les impacts sur les performances globales.
- Analyser les causes racines pour éviter la réapparition du problème.

## II. Symptômes observés

Lors des tests de fonctionnement :

- Le signal audio en sortie du module gain est très faible, même avec le potentiomètre au maximum.
- Aucun problème n’a été détecté en amont (module filtrage OK) ni en aval (ADC reçoit le signal, mais très atténué).

## III.Diagnostic

Élément vérifié | Observation | Conclusion
Potentiomètre de réglage du gain | Valeur mesurée instable, saute de 10 kΩ à 500 Ω en rotation | Composant probablement défectueux
Tension d’alimentation AOP | ±12 V correct | AOP bien alimenté
Signal de sortie | Amplitude faible (<100 mVpp) | Gain très insuffisant
AOP | Aucun échauffement ou court-circuit visible | Fonctionnel à première vue

Tableau 1 Tests et Diagnostiques

## IV.Intervention (Action corrective)

### A. Remplacement du potentiomètre :

- Retrait du potentiomètre linéaire de 10 kΩ.
- Installation d’un nouveau potentiomètre de même valeur et caractéristique.
- Soudure vérifiée et nettoyée.

### B. Contrôle du gain :

- Signal d’entrée : sinusoïde 1 kHz.
- Variation progressive du gain observée sur oscilloscope.
- Amplitude maximale en sortie : ~1.5 Vpp (conforme au design).

## V. Analyse des causes

La panne était due à une usure mécanique du potentiomètre, probablement causée par des manipulations fréquentes.
Le défaut est localisé au sous-système FT2-1 (Régulation du gain du signal d’entrée).

## VI.Fiche d'Intervention - Maintenance CORRECTIVE

Équipement concerné : [Module Gain]

Technicien : [Asad MUHAMMAD]

Date de l'intervention : [03/05/2025]

Type d’intervention : Maintenance corrective

### A. Check-list d'Intervention

1. Vérification des composants
✅ Vérification de l’alimentation électrique (tension, connexions, etc.) ☐ Vérification des câbles et des connecteurs
☐ Vérification du système de ventilation (poussières, filtres)
✅ Vérification de l’état des cartes électroniques et des composants ☐ Test de la communication (SPI, UART.)
2. Maintenance corrective physique
☐ Nettoyage des composants (carte, connecteurs, dissipateurs)
☐ Vérification de l'état des vis et fixations
✅ Remplacement des pièces usées ou endommagées
3. Test de fonctionnement
✅ Test de démarrage de l'équipement
✅ Vérification de la réponse des entrées/sorties
4. Réglages
☐ Réajustement des paramètres de configuration (CLK SPI)
5. Observations et Remarques

Anomalies détectées : [Le signal audio en sortie du module gain est très faible, même avec le potentiomètre au maximum.]

Pièces remplacées : [Potentiomètre]

Problèmes résolus : [Le signal audio en sortie du module gain est très faible, même avec le potentiomètre au maximum.]

Recommandations pour la prochaine intervention : [Prévoir un stock de composants (potentiomètres …etc.), Protéger mécaniquement le potentiomètre]

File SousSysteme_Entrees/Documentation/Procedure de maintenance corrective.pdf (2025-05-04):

BUT 3 – SAE S5

CY IUT – GEII Neuville

# Procédure de maintenance corrective

## Projet tutoré Mixeur Sous-système Entrées

## Document rédigé par : MUHAMMAD Asad Version : 1.1 [4 mai 2025]

BUT 3 – SAE S5 | Procédure de maintenance corrective

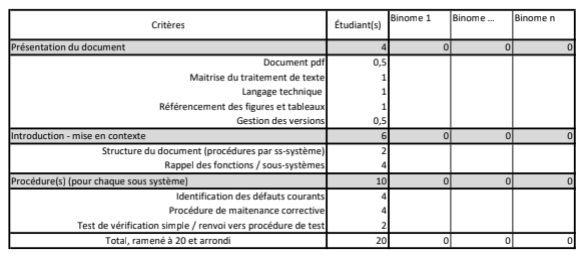
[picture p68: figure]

4 mai 2025 | Version : 1.1 | 1

## Historique des modifications et révisions de ce document :

N° de version | Date | Auteur | Description et circonstances de la modification
V 0 | | MUHAMMAD Asad | Brouillon : première version, modèle fourni.
V 1.0 | 27/04/2025 | MUHAMMAD Asad | Première rédaction complète du document.
V 1.1 | 04/05/2025 | MUHAMMAD Asad | Correction

## Grilles d'évaluations

## Avant-propos¹

Ce document décrit les procédures de maintenance corrective pour le sous-système 'Entrées' de la table de mixage audio développée dans le cadre du projet tutoré.

Il vise à établir des protocoles clairs pour diagnostiquer, réparer et remettre en service les éléments critiques en cas de défaillance constatée.

Les interventions correctives sont déclenchées suite à l’identification d’une panne ou d’une anomalie affectant le fonctionnement du système.

1 Référence : Gestion de projet, 50 outils pour agir ; F. Bouchaouir, Y. Dentinger, O. Englender ; Vuibert ;
2014. | Expression du besoin et cahier des charges fonctionnel ; J. Bernard-Bousières ; AFNOR ; 2012.

## Table des matières

## I. Introduction

### A. Contexte

Le projet consiste à concevoir une table de mixage audio modulaire capable d’interfacer des entrées analogiques et numériques (MIDI), et de traiter les signaux en temps réel. Chaque sous-système est conçu pour être facilement remplaçable ou réparable en cas de défaillance.

### B. Objectifs de la maintenance corrective

- Restaurer rapidement le fonctionnement normal après une panne.
- Minimiser le temps d'arrêt du système.
- Limiter les impacts sur les performances globales.
- Analyser les causes racines pour éviter la réapparition du problème.

### C. Méthodologie

L’approche corrective repose sur :

- La détection de la panne (signalement utilisateur, monitoring automatique).
- Le diagnostic précis via mesures, tests fonctionnels et observations visuelles.
- L’intervention rapide en respectant les procédures établies pour chaque type de panne.
- La traçabilité de chaque intervention (fiche d’intervention complétée).

## II. Rappel des fonctions

- FT9 : Assurer la fiabilité et la maintenance
- FT9-0 : Concevoir un système modulaire avec des sous-systèmes indépendants (entrée audio, traitement, interface utilisateur, alimentation).
- FT9-1 : Garantir la sécurité électrique grâce à une protection contre les surtensions et courts-circuits sur les entrées Analogiques et Numériques.
- FT9-2 : Garantir la sécurité électrique grâce à une protection contre les surtensions et courts-circuits sur les Alimentations.
- FT2, FT3 : Gérer l’entrée audio analogique
- FT2-0 : Conditionner le signal analogique via entrée haute impudence et filtrage.
- FT2-1 : Réguler le gain du signal d’entrée.
- FT2-2 : Appliquer un décalage (offset) sur le signal analogique AC.
- FT3 : Convertir le signal analogique en numérique (ADC) avec une résolution minimale de 12 à 16 bits et une fréquence d’échantillonnage de 44,1 kHz.
- FT1, FT6 : Gérer l’entrée audio numérique
- FT1-0 : Réceptionner les signaux MIDI.
- FT6 : Synchroniser les horloges MIDI avec le traitement audio interne.
- FT1-1 : Convertir les données MIDI en audio grâce à une synthèse numérique.
- FT5, FT6, FT7, FS1, FS2 : Assurer le traitement numérique du signal et produire un signal sonore
- FT5-0 : Appliquer des algorithmes de filtrage numérique (IIR/FIR) et de mixage pour ajuster les niveaux sonores et ajouter des effets.
- FT5-1 : Gérer le mixage audio en temps réel avec une allocation dynamique des canaux.
- FT7, FS1, FS2 : Fournir une IHM pour la gestion des paramètres de mixage et effets.
- FT6-0 : Restituer le signal audio
- FT6-1 : Fournir une sortie stéréo pour deux haut-parleurs intégrés ou une sortie ligne (non amplifiée).
- FT6-2 : Amplifier le signal audio
- Assurer l’amplification en tension et en courant du signal audio pour une restitution optimale.
- FT8 : Gérer l’alimentation électrique
- Assurer une alimentation via une batterie rechargeable.
- Permettre la recharge via un adaptateur secteur, une alimentation DC.
- FC6, FT9 : Garantir un format compact et une bonne ergonomie
- Concevoir un boîtier robuste et léger, en matériaux résistants aux chocs et adaptés aux manipulations fréquentes.
- Optimiser les dimensions pour faciliter le transport et l’intégration dans un setup mobile.¹

1
Les Fonction barrées seront rédigées dans les documents de sous-système correspondants

## III.Raspberry Pi : Gestion de entrées

Défaut constaté | Cause probable | Solution corrective | Test de vérification
Erreur de communication SPI | Horloge instable ou broche déconnectée | Vérification des câbles GPIO, re paramétrage SPI | Test de communication SPI

## IV.Procédures sous-système Analogique

### A. Carte Mère (FT9-0, FT9-1, FT2, FT3, FT1, FT6)

Défaut constaté | Cause probable | Solution corrective | Test de vérification
Mauvais contact | Oxydation connecteurs | Nettoyage au spray pour contacts | Test de continuité à l'ohmmètre

### B. Module Filtrage (FT2-0)

Défaut constaté | Cause probable | Solution corrective | Test de vérification
Mauvais filtrage | Condensateurs usés | Remplacement des condensateurs | Injection sinus 1kHz et analyse spectre de sortie
Pas de Signal sortie | AOP défectueux | Replacement AOP | Injection sinus 1kHz et analyse spectre de sortie

### C. Module Gain (FT2-1)

Défaut constaté | Cause probable | Solution corrective | Test de vérification
Signal trop faible/fort | Potentiomètre défectueux | Remplacement potentiomètre | Test de variation de gain avec oscilloscope
Pas de Signal sortie | AOP défectueux | Replacement AOP | Injection sinus 1kHz et analyse spectre de sortie

### D. Module Offset (FT2-2)

Défaut constaté | Cause probable | Solution corrective | Test de vérification
Offset incorrect | Dérive thermique | Recalibrage du potentiomètre | Vérification offset avec multimètre sur entrée de l'AOP
Pas d’offset ou offset varie | Régulateur de tension défectueux | Remplacement Régulateur de tension | Vérification de tension de sortie de régulateur égale à 3.3V avec un multimètre
Pas de Signal sortie | AOP défectueux | Replacement AOP | Injection sinus 1kHz et analyse spectre de sortie

### E. Module Convertisseur ADC (FT3)

Défaut constaté | Cause probable | Solution corrective | Test de vérification
Échantillonnage incorrect | Horloge défectueuse | Vérification du signal d'horloge, reconfiguration | Capture du signal échantillonné et analyse sur oscilloscope

## V. Procédures sous-système Numérique

### A. Module MIDI (FT1)

Défaut constaté | Cause probable | Solution corrective | Test de vérification
Synchronisation erratique | Défaillance signal d'horloge | Ajustement fréquence de l'horloge | Observation du timing MIDI sur oscilloscope

## VI.Outils et Matériel requis

- Multimètre numérique : Pour vérifier les tensions d'alimentation, les offsets et la continuité.
- Oscilloscope : Observation des signaux d’entrée, vérification des horloges (échantillonnage).
- Générateur de fonctions : Pour tester les réponses analogiques des modules filtrage/gain.
- Spray nettoyant pour contacts électroniques : Pour les potentiomètres et connecteurs.
- Tournevis de précision : Pour ajustement fin des potentiomètres.
- Station de soudure : Pour remplacement de composants défaillants.

VII. Fiches d’intervention : Modèles prêts à remplir (date, technicien, observations).

| Fiche d'Intervention - Maintenance CORRECTIVE

Équipement concerné : [Module Gain]

Technicien : [Asad MUHAMMAD]

Date de l'intervention : [ | ]

Type d’intervention : Maintenance corrective

1. Check-list d'Intervention
1. Vérification des composants
☐ Vérification de l’alimentation électrique (tension, connexions, etc.) ☐ Vérification des câbles et des connecteurs
☐ Vérification du système de ventilation (poussières, filtres)
☐ Vérification de l’état des cartes électroniques
☐ Test de la communication (SPI, UART.)
2. Maintenance corrective physique
☐ Nettoyage des composants (carte, connecteurs, dissipateurs) ☐ Vérification de l'état des vis et fixations
☐ Remplacement des pièces usées ou endommagées
3. Test de fonctionnement
☐ Test de démarrage de l'équipement
☐ Vérification de la réponse des entrées/sorties
4. Réglages
☐ Réajustement des paramètres de configuration (CLK SPI)
5. Observations et Remarques
Anomalies détectées : [ |
| ]
Pièces remplacées : [ | ]
Problèmes résolus : [ | ]
Recommandations pour la prochaine intervention : [ |
| ]

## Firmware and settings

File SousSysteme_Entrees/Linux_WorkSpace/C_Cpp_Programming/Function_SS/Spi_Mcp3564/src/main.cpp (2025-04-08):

#include "../lib/MCP3564/MCP3564.h"
#include <stdio.h>

int main() {
    MCP3564 adc;

    if (!adc.begin()) {
        printf("Erreur d'initialisation du MCP3564\n");
        return -1;
    }

    printf("Configuration actuelle :\n");
    adc.printConfiguration();

    int32_t val0 = adc.read(0);
    int32_t val1 = adc.read(1);

    printf("Canal 0 : %ld\n", val0);
    printf("Canal 1 : %ld\n", val1);

    return 0;
}

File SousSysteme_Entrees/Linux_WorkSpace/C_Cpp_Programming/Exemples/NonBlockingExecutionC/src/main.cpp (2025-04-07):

#include <stdio.h>
#include <time.h>

int main() {
    struct timespec current, start_1s, start_H_s; // POSIX.1b structure for a time value.
    long elapsed_ns_1s, elapsed_ns_H_s; // Separate elapsed time variables
    long interval_ns = 1000000000L; // 1s in ns
    long interval_H_ns = 500000000L; // 0.5s in ns

    // Get the starting time
    clock_gettime(CLOCK_REALTIME, &start_1s);
    clock_gettime(CLOCK_REALTIME, &start_H_s);

    while (1) {
        // Get the current time
        clock_gettime(CLOCK_REALTIME, &current);

        // elapsed time for 1-second interval in nanoseconds
        elapsed_ns_1s = (current.tv_sec - start_1s.tv_sec) * 1000000000L + (current.tv_nsec - start_1s.tv_nsec);

        // elapsed time for 0.5-second interval in nanoseconds
        elapsed_ns_H_s = (current.tv_sec - start_H_s.tv_sec) * 1000000000L + (current.tv_nsec - start_H_s.tv_nsec);

        // Check if the elapsed time exceeds the 1-second interval
        if (elapsed_ns_1s >= interval_ns) {
            printf("Hello, World!\n");
            // Reset the starting time for 1-second interval
            start_1s = current;
        }

        // if  elapsed time exceeds the 0.5-second interval
        if (elapsed_ns_H_s >= interval_H_ns) {
            printf("Half Sec\n");
            // Reset the starting time for 0.5-second interval
            start_H_s = current;
        } 
    }
    return 0;
}

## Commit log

2024-10-27 change diagrames and cahier des charges
2024-10-27 Update Cahier des charges techniques.pdf
2024-12-02 modification des fichiers instruction d'installation
2024-12-25 CDC_V3, PlanificationV2, modification de structure
    [Liste de Materiel.xlsx]
2024-12-28 added HTML for embedded liste de materiels
    added html page of embedded list of materiel, deployed the page on github repo setting that can be accessed using : https://a-s-a-d.github.io/Table-de-Mixage/FILES/EXCEL.html so when the link is clic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
2025-01-21 added thread exemple and thread with synch
2025-01-22 Added new template for wiring pi, digitialwrite exemple
2025-01-27 ajouté le ficier md sur comment activer l'uart
2025-01-27 added program that sends data to uart0, and tested
2025-01-27 modified uart config md file
2025-01-30 modified all cmakes for correctly adding source files
    [main.cpp]
2025-02-05 had problem with sending midi data, tried Wiringpi exemple, seems to work
    [main.cpp]
2025-02-09 Dossier de Conception V1
2025-02-09 Document de Conception
2025-02-10 Modifié la date en DDC
2025-02-13 added backuped files to new branch
    [01-Suiveur.PrjPcb, 02-Ampli.PrjPcb, 03-Offset_et_PBF.PcbDoc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]
2025-02-13 02-Ampli all composants aavalaible
    [Ampli.SchDoc, Suiveur.SchDoc]
2025-02-13 03 Offset all components avaliable
    [03-Offset_et_PBF.SchDoc]
2025-02-13 01 -suiveur all components avalaible
    [Suiveur.SchDoc]
2025-02-13 generated gerbers
    [01-Suiveur.PrjPcb, 02-Ampli.PrjPcb, 03-Offset_et_PBF.PcbDoc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]
2025-02-15 Modification Carte mere et library
    [CarteMere.PcbDoc, CarteMere.SchDoc, Carte_Mere.PrjPcb]
2025-02-15 bom carte mere
2025-02-15 Annotation and BOM
    [Suiveur.PcbDoc, Suiveur.SchDoc]
2025-02-15 Annotation, remove unnecessary components, reposition, BOM
    [03-Offset_et_PBF.PcbDoc, 03-Offset_et_PBF.SchDoc, Ampli.SchDoc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]
2025-02-16 Dossier de Conception Version 1.1
2025-02-16 Dossier de Fabrication Version 1
2025-02-19 setup a remote desktop on raspberry to work through my laptop
2025-02-26 UART recive midi data, we'll use 115200 baud cause midi one is not standard
2025-03-03 MotherBoard and assembly
    [03-Offset_et_PBF.PcbDoc, Amplification.PcbDoc, CarteMere.PcbDoc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]
2025-03-04 Procédure d'installation et de mise en service V1
2025-03-06 Rapport et procedure de test
2025-04-04 added script for Clock on GPIO4 for ADC, and some other minor changes
2025-04-06 Procedure de maintenance preventive
2025-04-07 modified the code of SPI
2025-04-07 added all docs in a folder named documentation
    [Liste de Materiel.xlsx]
2025-04-13 modified structure / rearranged files for "Dossier Technique"
    [Liste de Materiel.xlsx, tableau sortie micro.xlsx]
2025-04-27 Create Procedure de maintenance corrective.pdf
2025-04-30 merged PCB design for Inputs and main and moved it to "entrees" folder
    [01-Suiveur.PrjPcb, 02-Ampli.PrjPcb, 03-Offset_et_PBF.PcbDoc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]
2025-04-30 again : merged PCB design for Inputs and main and moved it to "entrees" folder
    [01-Suiveur.PrjPcb, 02-Ampli.PrjPcb, 03-Offset_et_PBF.PcbDoc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]
2025-05-04 Rapport de Maintenance corrective
2025-05-04 Gerber and modified ADC PCB
    [01-Suiveur.PrjPcb, 02-Ampli.PrjPcb, 03-Offset_et_PBF.PrjPcb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]
2025-05-04 Doc conception V1.2 and BOM ADC
2025-05-04 V 1.1 dossier de fabrication
2025-05-04 ajouté les fichiers sous format word pour pouvoir modifier en future
